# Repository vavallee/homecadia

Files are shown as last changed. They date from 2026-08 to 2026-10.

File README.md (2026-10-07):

<h1 align="center">
  <picture>
    <source media="(prefers-color-scheme: dark)" srcset="docs/img/logo-dark.svg">
    homecadia
  </picture>
</h1>

<!-- Logo: the Grand-Pré Memorial Church (Grand-Pré National Historic Site, Nova
     Scotia) behind the case wordmark; drawn without religious symbols. -->

**A battery-powered Matter-over-Thread room sensor for Home Assistant, built
from scratch on the ESP32-C6 with esp-matter and ESP-IDF. 125 µA average,
e-ink display, rotary dial, no cloud, no Wi-Fi, and every trap written down.**








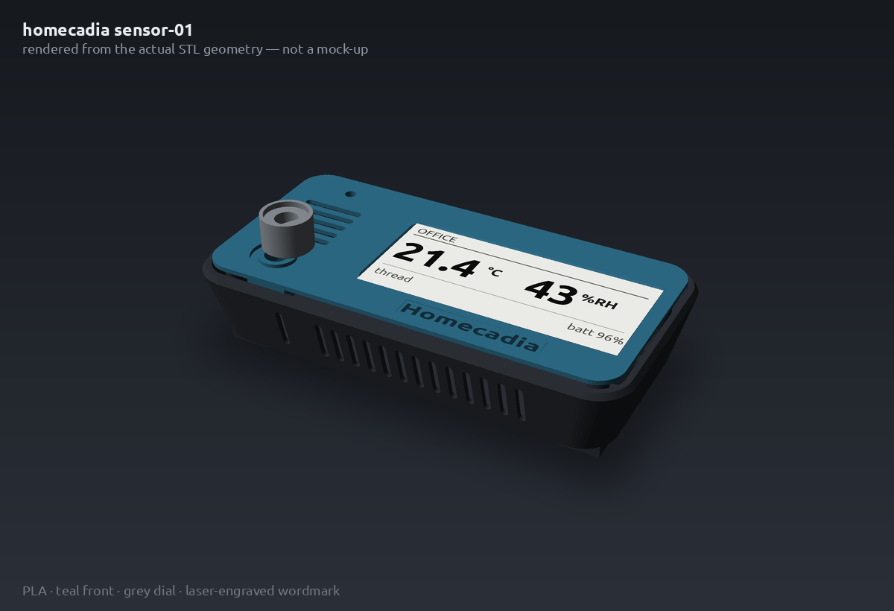
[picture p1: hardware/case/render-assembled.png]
sensor-01


<!-- photo replaces the render once a unit is assembled: ![sensor-01](docs/img/sensor-01.jpg) -->

A room temperature and humidity sensor that reports to Home Assistant over
Thread as a Matter sleepy end device, shows its own readings on a 2.9" e-ink
panel, and takes input from a rotary dial. It averages **125 µA** measured on
the bench, about eighteen months on one 2000 mAh cell at 85 % usable. No vendor
cloud, no hub beyond a Thread border router, and no Wi-Fi: the radio is
compiled out.

Everything is here: firmware, drivers, pin map with schematic-verified board
facts, measured power budget, 3D-printable enclosure, bill of materials with
real prices, and the reasoning behind each decision, including the ones that
turned out wrong.

## At a glance

| | |
|---|---|
| MCU | Seeed XIAO ESP32-C6 (RISC-V, 802.15.4 + BLE; Wi-Fi compiled out) |
| Firmware | **aardvark** (Matter model name and version string, e.g. `aardvark 0.7.0`; build output `aardvark.bin`, OTA image `aardvark-<version>.ota`) |
| Stack | [esp-matter](https://github.com/espressif/esp-matter) v1.6 on ESP-IDF v5.5.5, C++ |
| Network | Matter over Thread, OpenThread minimal device (MTD), commissioned over BLE |
| Power mode | Intermittently Connected Device (ICD), short idle time: 15 s parent polls, 600 s idle interval, automatic light sleep |
| Controller | Home Assistant with matterjs-server, Home Assistant Connect ZBT-2 border router |
| Clusters | Temperature Measurement, Relative Humidity Measurement, Power Source (battery % and voltage), Thread Network Diagnostics with counters |
| Measured current | **125 µA** paired and settled (sleep floor 57 µA, parent poll ~0.48 mC); **19.7 µA** unpaired in deep sleep |
| Display | 2.9" 296×128 SSD1680 e-paper, partial refresh ~6–7.5 mC, full ~19 mC |
| Status | One unit bench-verified on a Nordic PPK2; enclosure being redesigned |

## If you are building Matter or Thread devices on an ESP32

Most of this repo is reusable even if you never build this sensor. The
findings that took longest, with where to read them:

| Topic | Where |
|---|---|
| Getting an ESP32-C6 Matter device from ~376 µA to 125 µA: ADC power domain, bus power-down flags, ICD mode, a pin regression | [power-budget.md](docs/power-budget.md), [field-notes](docs/field-notes.md) §20–§22, §28 |
| Long Idle Time ICD buys nothing with Home Assistant (no check-in client) and costs ~67 µA; what to use instead | [retro](docs/retro.md) M8, [sdkconfig.defaults](firmware/sensor-01/sdkconfig.defaults) |
| A non-wake GPIO with a level interrupt under `CONFIG_PM_SLP_DISABLE_GPIO`: +16 µA floor, polls 60 % dearer | [field-notes](docs/field-notes.md) §28 |
| Waking light sleep from a rotary encoder: LP GPIOs only, level not edge | [field-notes](docs/field-notes.md) §21, [`ec11_encoder`](firmware/components/ec11_encoder) |
| An unpaired Matter device draws 28 mA; deep sleep that works (restart, then sleep before the stack starts) | [field-notes](docs/field-notes.md) §26–§27 |
| `attribute::update()` silently does nothing for code-driven clusters in esp-matter v1.6 | [field-notes](docs/field-notes.md) §9 |
| Commissioning to Home Assistant without HAOS: test certificates, BLE proxy, border router | [commissioning.md](docs/commissioning.md) |
| Thread coverage, border-router outages, a bare XIAO ESP32-C6 as a Thread router | [field-notes](docs/field-notes.md) §6–§7, §24, [infrastructure.md](docs/infrastructure.md), [bringup.md](docs/bringup.md) Radio / Matter |
| Measuring µA on a sleepy radio device with a PPK2, and analysing captures offline | [`tools/ppk2-events.py`](tools/ppk2-events.py), [retro](docs/retro.md) T7–T9 |
| Hardware bring-up traps: FPC ribbons, flux, underside pads, breadboard battery paths | [assembly.md](docs/assembly.md), [battery-runbook.md](docs/battery-runbook.md), [field-notes](docs/field-notes.md) §15–§19, §25 |
| Eight weeks of bring-up in one place: what went wrong, why, and the checklist for the next unit | [retro.md](docs/retro.md) |

> **Status: bench-verified, not yet assembled.** One unit runs on the bench
> (XIAO, driver board, panel, SHT40, encoder on a breadboard) with a Nordic
> PPK2 standing in for the cell. Verified there: commissioning to Home
> Assistant over Thread, display output, battery-voltage reading (within 3 mV
> of a meter, 3.4–4.0 V), **125 µA settled paired current** (2026-10-05),
> 19.7 µA unpaired deep sleep, and the dial waking the chip from light sleep on
> battery power. It has run 21 h on a real LiPo with no restart. **Not yet
> done:** a long soak on a real cell, and the enclosure, which is being
> redesigned. Open rows are in [docs/bringup.md](docs/bringup.md); code written
> ahead of hardware is marked `HW-VERIFY` and tracked there. The build
> procedure, with a test gate after every soldering stage, is
> [docs/assembly.md](docs/assembly.md).

## Devices

| Device | Status | Description |
|---|---|---|
| [sensor-01](firmware/sensor-01/) | in development | Battery-powered room temp/humidity sensor. 2.9" e-ink display, rotary dial, Matter-over-Thread sleepy end device (SIT ICD). 3 units. |

## What you can lift from here

The drivers are self-contained ESP-IDF components with no dependencies beyond
the IDF itself. Copy the directory into your own `components/` and it builds.
MIT licensed.

| Component | Why it might be useful |
|---|---|
| [`sht40`](firmware/components/sht40) | Sensirion SHT40 on the ESP-IDF 5.x `i2c_master` API (not the deprecated legacy driver), high-precision single-shot with CRC-8 validation |
| [`ssd1680`](firmware/components/ssd1680) | 2.9" e-paper with **differential partial refresh**, periodic full refresh to clear ghosting, and panel deep sleep between updates — the parts most sample code leaves out |
| [`monogfx`](firmware/components/monogfx) | 1-bit framebuffer renderer with a scaled 5×7 font and a seven-segment digit routine. No LVGL, no external graphics library |
| [`ec11_encoder`](firmware/components/ec11_encoder) | EC11 rotary encoder decoded from a Gray-code transition table in an ISR — bounce-immune without debounce delays, and draws no idle current |

Tools, usable on any project:

| Tool | What it does |
|---|---|
| [`tools/ppk2-events.py`](tools/ppk2-events.py) | Reads a Nordic PPK2 `.ppk2` capture offline and splits it into sleep floor, radio polls, bursts and short wakes with their charge, so one capture gives a per-item current budget |
| [`tools/matter-node.py`](tools/matter-node.py) | Reads a node through the Home Assistant Matter server WebSocket: the cached attributes (free for the device) or a forced interview |
| [`tools/check-profiles.sh`](tools/check-profiles.sh) | Asserts a shipping and a bench sdkconfig really differ on sleep, and that test-only options are off in shipping. Runs in CI |

Also reusable regardless of hardware: the
[power budget](docs/power-budget.md) and the firmware policies it forced, the
[retro](docs/retro.md), and the [documented traps](#traps-that-cost-time)
below.

## Features

Firmware capabilities, all implemented in this repo unless noted:

- **Matter over Thread**, Wi-Fi compiled out. OpenThread MTD, commissioned over
  Bluetooth Low Energy, joins via any OpenThread border router (developed
  against Home Assistant Connect ZBT-2).
- **Short Idle Time ICD** (Intermittently Connected Device): automatic light
  sleep between 15 s parent polls, and a 600 s idle interval that the device
  offers as its subscription max interval, so a report with nothing new goes
  out every 10 min. Long Idle Time was dropped on 2026-10-04: Home Assistant
  registers no check-in client, so it only added cost
  ([retro](docs/retro.md) M8).
- **Unpaired deep sleep**: a unit nobody pairs deep-sleeps at 19.7 µA once
  its 15-minute commissioning window closes, and a turn of the dial starts a
  new window ([field-notes](docs/field-notes.md) §27).
- **Thread Network Diagnostics with counters** (attach attempts, parent
  changes, MAC retries), readable from the controller at no reporting cost.
- **Matter clusters**: TemperatureMeasurement, RelativeHumidityMeasurement, and
  PowerSource with battery percentage and voltage.
- **Delta-gated reporting** — a report is sent on ≥0.2 °C / ≥1 %RH change, with
  a forced heartbeat every N polls, instead of on every sample.
- **SHT40 driver** (`firmware/components/sht40`) on the ESP-IDF 5.x
  `i2c_master` API, high-precision single-shot with Sensirion CRC-8 checking.
- **SSD1680 e-paper driver** (`firmware/components/ssd1680`) with differential
  partial refresh, periodic full refresh for ghosting, and panel deep sleep
  between updates.
- **1-bit framebuffer renderer** (`firmware/components/monogfx`) with a scaled
  5×7 font and a seven-segment digit routine — no external graphics library.
- **EC11 rotary encoder** (`firmware/components/ec11_encoder`) decoded from a
  Gray-code transition table in an interrupt handler: bounce-immune and drawing
  no idle current.
- **Local-only UI**: readings, diagnostics, and settings views; settings persist
  in NVS. The display never renders Home Assistant state — it shows what this
  device measured.
- **Battery monitoring** via a 2×1 MΩ + 100 nF divider on GPIO4 (an underside
  pad): 64 one-shot ADC samples after a 20 ms settle, eFuse curve-fitting
  calibration, and a scale factor fitted against a metered source to correct the
  ADC input loading the 500 kΩ divider. Open-circuit-voltage lookup table for
  percent.
- **Dial wakes the chip** from light sleep on a detent (encoder A on an LP
  GPIO underside pad, level-triggered).
- **Factory reset** on a 10-second encoder press (turn first: the switch is on
  a pin that cannot wake the chip); commissioning and low-battery states shown
  on a single LED and on the display.
- **CI** builds the flashable images on every push touching `firmware/**` and
  uploads them as an artifact.

## sensor-01 hardware

Seeed XIAO ESP32-C6 + Seeed ePaper Driver Board for XIAO V2 + 2.9" mono e-ink
(296×128, SSD1680) + Grove SHT40 + EC11 rotary encoder + 2000mAh LiPo, in a
wall-mount enclosure remixed from [veltoc](https://github.com/danking6/veltoc)
([hardware/case](hardware/case/README.md) — rev 4, FDM PLA, laser-engraved
wordmark).

assembled render

*Assembled view rendered from the enclosure STLs. Colours and finish are
indicative; no unit has been built yet.*

sensor-01 pin map

Full bill of materials: [docs/bom.md](docs/bom.md). Pin map with the
schematic-verified board facts behind this diagram:
[docs/pinmap.md](docs/pinmap.md). The official bare-board pinout is on the
[Seeed XIAO ESP32-C6 wiki](https://wiki.seeedstudio.com/xiao_esp32c6_getting_started/)
(not reproduced here — Seeed's wiki content is GPL-3.0, this repo is MIT).

⚠️ This build involves a bare lithium-polymer cell soldered directly to the
board. Read the polarity warning at the top of
[docs/assembly.md](docs/assembly.md) before connecting anything — reversed
polarity destroys the charge circuit, and damaged LiPo cells are a fire hazard.

## Firmware

Espressif [esp-matter](https://github.com/espressif/esp-matter) v1.6 on
ESP-IDF v5.5.5, C++. Thread only (Wi-Fi disabled), commissions over Bluetooth
Low Energy to Home Assistant via an OpenThread border router (Home Assistant
Connect ZBT-2). Build instructions: [docs/build.md](docs/build.md).

The device advertises Espressif's **test vendor ID 0xFFF1** and shared test
commissioning credentials. It is not a Matter-certified product; controllers
will show an uncertified-device warning. Per-device factory partitions
(`esp-matter-mfg-tool`) are an open work item — see
[docs/commissioning.md](docs/commissioning.md).

## Documentation

| Doc | Contents |
|---|---|
| [docs/bom.md](docs/bom.md) | Bill of materials, part SKUs, divider-value rationale |
| [docs/pinmap.md](docs/pinmap.md) | Pin assignments and schematic-verified XIAO ESP32-C6 board facts |
| [docs/assembly.md](docs/assembly.md) | Wiring and build order, battery-polarity warning |
| [docs/build.md](docs/build.md) | Pinned toolchain SHAs, Docker and native builds, flashing from WSL2 |
| [docs/commissioning.md](docs/commissioning.md) | Pairing to Home Assistant: the three preconditions, the BLE-proxy workaround, factory reset. Apple Home is not available here and the doc says why |
| [docs/retro.md](docs/retro.md) | **Retrospective of the whole bring-up**: lessons, timeline, every problem with its cause and rule, the checklist for the next unit, open questions |
| [docs/field-notes.md](docs/field-notes.md) | **Traps that cost real time during bring-up**, one numbered section per incident (cited as §n). Read before bringing up another unit |
| [docs/power-budget.md](docs/power-budget.md) | Modelled and measured current draw per item, battery-life calculator, the policies it forced |
| [docs/battery-runbook.md](docs/battery-runbook.md) | Why a pack reads 0 V or a unit resets on battery: protection-board causes, look-alikes, and the test order |
| [docs/bringup.md](docs/bringup.md) | Hardware verification checklist — every `HW-VERIFY` marker has a row |
| [docs/diagrams/](docs/diagrams/) | Bench wiring, battery/divider schematic, enclosure internals and the no-solder bring-up ladder (self-contained HTML) |
| [docs/infrastructure.md](docs/infrastructure.md) | Network-side hardware: ZBT-2 border router, Thread coverage, Voice PE, order status |
| [docs/source-reliability.md](docs/source-reliability.md) | Documented traps in vendor docs and third-party sources |
| [hardware/case/README.md](hardware/case/README.md) | Enclosure: revision history, measured wall thicknesses, print vendor and material, engraving artwork |
| [circuit-board-maker/](circuit-board-maker/README.md) | Custom-PCB evaluation and two paper board designs. **Concluded: not worth it for three units.** Never fabricated — see the conflicts list before reviving it |

## Traps that cost time

Findings that aren't in any datasheet, written down so the next person doesn't
pay for them twice. Full list in
[docs/source-reliability.md](docs/source-reliability.md) and
[docs/pinmap.md](docs/pinmap.md).

- **A0 and D0 are the same pin on the XIAO ESP32-C6.** If your display uses D0
  for reset, the obvious ADC pin is gone. Battery sense moved to an underside
  test pad ([pinmap](docs/pinmap.md)).
- **The C6's RF switch is off at reset.** GPIO3 has a 10k pull-up and must be
  driven low in firmware before the antenna works; GPIO14 selects onboard
  ceramic versus U.FL. Neither pin is on the header. Schematic-verified.
- **espboards.dev pin tables are wrong for the C6** — they're shared boilerplate
  across ESP32 variants.
- **The Seeed wiki's battery-sense snippet doesn't apply.** It assumes an
  onboard divider the C6 schematic shows isn't populated.
- **A 100k battery divider costs ~9% of a 300µA budget.** 2×1MΩ + 100nF instead,
  at the price of a high-impedance ADC source ([power budget](docs/power-budget.md)).
- **A live ADC unit keeps the C6's radio power domain on through every light
  sleep** (~95 µA). Create and delete the unit per reading, and hold a
  no-light-sleep lock across it or the chip can fail to wake
  ([field notes](docs/field-notes.md) §21).
- **The chip only powers down its peripherals in light sleep if every I2C and
  SPI bus asks for it** (`flags.allow_pd`, `SPICOMMON_BUSFLAG_SLP_ALLOW_PD`).
  Without them the sleep floor was 279 µA; with them, 56 µA (§21).
- **A multimeter on a high-impedance node is a load, not a reference.** A 10 MΩ
  meter reads a 1 MΩ:1 MΩ divider midpoint ~5 % low. Calibrate the ADC against
  the supply, end to end (§23).
- **Light sleep kills the USB serial port in ~2 seconds**, which makes a board
  effectively unflashable without `CONFIG_USJ_NO_AUTO_LS_ON_CONNECTION`
  ([build](docs/build.md) has the recovery procedure, including the WSL2/usbipd
  quirks).
- **Opening `/dev/ttyACM0` with a plain shell read can hard-reset the chip** —
  it pulses the USB-Serial-JTAG control lines. Use `idf.py monitor`.
- **Seeed's sleep-current figures are for a bare board.** Measured on this build:
  a 45–57 µA light-sleep floor once the fixes here were in; 376 µA before
  them ([power budget](docs/power-budget.md)).
- **Long Idle Time ICD does nothing for you under Home Assistant.** No
  check-in client registers, so the device runs short-idle mode anyway, while
  LIT forces a 5 s minimum active period after every exchange and an extra
  wake a minute. Turning it off and raising the idle interval to 600 s took
  the average from 307 to 185 µA ([retro](docs/retro.md) M8).
- **A non-wake GPIO with a level interrupt reads as triggered in light sleep.**
  With `CONFIG_PM_SLP_DISABLE_GPIO`, pins that are not wake sources are
  isolated and read low. A push switch on an HP pin with a low-level interrupt
  raised the floor 16 µA and made every Thread poll 60 % dearer;
  `gpio_sleep_sel_dis()` fixed it, 185 → 125 µA (§28).
- **Only LP GPIOs (0–7) wake the C6 from light sleep with peripheral
  power-down on, and only on a level.** On the XIAO the free LP pins are
  underside pads (§21, [pinmap](docs/pinmap.md)).
- **An unpaired Matter device on the C6 never light-sleeps and draws ~28 mA.**
  `esp_deep_sleep_start()` from the running stack hung or stuck at 20 mA; what
  worked is restarting and entering deep sleep at the top of the next boot,
  before Bluetooth, Thread or power management start (§26–§27).
- **A USB host keeps the C6 out of light sleep**, so a sleep bug can be
  invisible for weeks on the bench. Test sleep on battery or a PPK2 with USB
  out (§20).
- **A breadboard row in the battery path brown-outs the radio.** Thousands of
  restarts read as a firmware fault; the Matter `bootReason` attribute said
  brown-out all along ([battery-runbook](docs/battery-runbook.md) B3).

## Milestones

| # | Deliverable | Status |
|---|---|---|
| 1 | Repo scaffold, docs, CI compiling an esp-matter skeleton for esp32c6 | done |
| 2 | Matter temp/humidity over Thread, commissions to HA (TinyENV parity) | **done 2026-08-23** — commissioned to HA over ZBT-2 OTBR, readings live in HA; see `docs/field-notes.md` for the preconditions |
| 3 | Display driver, view 1 rendering readings, measured refresh cost | **done** — display verified 2026-08-22 (full 1.79 s / partial 0.54 s BUSY); refresh charge measured 2026-10-05: partial ~6–7.5 mC, full ~19 mC |
| 4 | Encoder, views, settings, wake behavior | **done 2026-09-28** — a detent wakes the chip from light sleep on battery (encoder A on the MTCK pad); the push switch registers within 2 s of a turn |
| 5 | ICD tuning, battery reporting, power budget with measured numbers | **done** — 238 µA over 12.6 h (2026-09-22); **125 µA settled** after the ICD and pin fixes (2026-10-05); unpaired deep sleep 19.7 µA; battery voltage within 3 mV. See `docs/power-budget.md` |
| 6 | Factory reset, low-battery behavior, assembly guide final, v1.0.0 | factory reset + LED + low-bat display done; rest awaits hardware |

## Repo layout

```
docs/               BOM, pin map, assembly, commissioning, power budget, build,
                    field notes, retro
hardware/case/      wall-mount enclosure (veltoc remix, MIT) + engraving artwork
circuit-board-maker/ custom-PCB evaluation + two unfabricated KiCad designs
firmware/
  components/       drivers shared across future homecadia devices
  sensor-01/        esp-matter application
tools/              PPK2 capture analysis, Matter server node reader, profile check
.github/workflows/  CI: firmware build on push, .bin artifacts
```

## Building it yourself

1. **Read [docs/bom.md](docs/bom.md)** — real parts, real prices in CAD, real
   vendors, and which ones have known counterfeits or reversed polarity.
2. **Print the enclosure** from [hardware/case](hardware/case/README.md), or
   adapt it. The revision history there explains why each dimension is what it
   is, which matters if you swap the battery or the display.
3. **Build the firmware** with [docs/build.md](docs/build.md) — Docker path
   matches CI exactly and is the low-friction option.
4. **Wire it** using [docs/pinmap.md](docs/pinmap.md) and
   [docs/assembly.md](docs/assembly.md). Read the LiPo polarity warning first.
5. **Commission it** with [docs/commissioning.md](docs/commissioning.md), then
   work through [docs/bringup.md](docs/bringup.md).

Forking for different hardware? `firmware/sensor-01/main/app_config.h` is the
single source of pin truth and the place to start.

## Contributing

This is a personal build against one specific parts list, so the parts list, the
pinned toolchain and the locked design decisions are unlikely to change. That
said: **corrections are very welcome**, especially if you've measured something
this repo only models, or if one of the [traps](#traps-that-cost-time) turns out
to be wrong on your hardware. Issues and pull requests both fine.

If you are working on Matter or Thread devices on the ESP32-C6 (or H2, or any
ESP32 with an 802.15.4 radio) and hit something documented here, or something
that should be, open an issue: comparing measured numbers across boards is
the fastest way to tell a board quirk from a firmware one.

## License

MIT, see [LICENSE](LICENSE). Third-party attribution — including the veltoc
enclosure remix and the TinyENV architecture references — is in
[NOTICE.md](NOTICE.md).

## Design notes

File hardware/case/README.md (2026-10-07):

# Wall-mount case (veltoc remix, rev 5)

Remix of [veltoc](https://github.com/danking6/veltoc) 3D models (MIT,
© 2026 Dan King). `case-back-wallmount.stl` and `case-front.stl` are both
modified; `insert-tray.stl` and `encoder-knob.stl` print as-is from upstream.

> **rev 5 — back 8 mm deeper (2026-10-06); not yet printed.** Print it with
> [PRINTING.md](PRINTING.md). Only
> `case-back-wallmount.stl` changed: 23.00 → **31.00 mm** tall, outline and
> rim unchanged, so the rev 4 front, tray and knob still fit it. The shell was
> cut at z = 17.74 mm (above the USB-C hole, below the rim fillet), the upper
> part lifted 8 mm and the cut joined with a vertical band (`deepen.py`, in
> this directory: `python3 deepen.py IN OUT 17.74 8`, IN = the rev 4 file). The mesh keeps the
> same open-edge count as the vendor-printed rev 4 file (33), so the cut added
> no defects.
>
> Layout it is built for, from caliper measurements of the parts as built
> (2026-10-06), floor upward: the **cell flat on the floor** (56 × 34.2 ×
> 11 mm, bare leads ~29 mm, no JST), the tray on the cell (1.6 mm plate), the
> XIAO in its sockets on the driver board (15.5 mm from the USB-C top to the
> driver board's underside), the **pins under the driver board trimmed to
> ~1.5 mm** (they are 9.0 mm as built for the breadboard), then the panel
> (~1.2 mm, not measured) against the front plate: ~30.8 mm against ~33.6 mm
> of inside depth: ~2.8 mm spare for the unmeasured panel and foam tape. The USB-C panel connector's long leads coil in the free
> bay at one end; its hole does not need to line up with the XIAO's port.
> SHT40 board: 41.8 × 19.7 × 6.5 mm, ~130–140 mm lead to a 4-pin connector.
>
> **rev 4 does not fit the parts — found 2026-09-24.** Kept in git history
> (commit `4a53b2e`). Against the STL geometry, the 2000 mAh cell
> (56 × 34.5 × 10.6 mm) does not fit the cavity with the tray and driver board
> in place; the free bay at the left end is about 35 × 48 × 17 mm and the USB
> port falls inside it. Against the printed parts in hand: the panel and the
> tray fit; the driver board does not seat, because the header sockets soldered
> to it are taller than the back allows. The "2.1 mm clearance" below counts
> length only and did not account for the stack height. A deeper back is the
> expected fix; it waits on caliper measurements of the real parts
> ([docs/bringup.md](../../docs/bringup.md), Case & mechanical).
>
> **rev 2 — lengthened 7 mm for the 2000 mAh cell.** Upstream is built around a
> 1400 mAh cell (EEMB 112945, 45 mm long). Our BOM specifies a 2000 mAh EEMB
> LP103454, whose finished size is **56 × 34.5 × 10.6 mm** — 11 mm longer. The
> rev 1 interior measured 99.64 mm and had to hold the 48.5 mm `insert-tray`
> plus the cell: 104.5 mm of parts in a 99.6 mm box.
>
> Both shells were cut at **x = 24.73 mm** — a band verified prismatic (identical
> cross-section either side) and clear of the display aperture (29.5–97.5),
> encoder, LED, vents and tray posts — and everything right of the cut moved
> +7 mm. Interior is now **106.64 mm**, leaving **2.1 mm clearance**. The display
> aperture is unchanged at 68.00 mm wide; it simply sits 7 mm further along.

assembled render

Assembled view, rev 4 (the rev 5 back is 8 mm deeper; not re-rendered). Rendered directly from the STL geometry in this
directory — real part shapes and real relative positions, so the proportions,
the wordmark placement and the aperture framing are accurate. The wordmark is
composited at its true size and position, representing the laser engraving.
Surface finish and screen contents are illustrative. `preview.png` is the older
rev 1 image and no longer matches the models.

**Colours (PLA, matched to EurekaTec stock):** teal front, light grey dial,
black or dark grey back (PLA availability to confirm), tray any colour since it
is never seen. EurekaTec's ABS stock is black / dark grey / red only, which is
part of why the build moved to PLA.

## Files (`stl/`)

| File | Status | Outer size (mm) | Notes |
|---|---|---|---|
| case-back-wallmount.stl | remixed + rev 2 stretch + **rev 5 deepen** | 116.28 × 59.28 × **31.00** | wall-mount rails, side USB-C, rear port plugged |
| case-front.stl | rev 2 stretch | 110.60 × 53.60 × 8.20 | EC11 mount (Ø6.8 shaft hole, Ø9.8/Ø14 recess), 3mm LED hole, display aperture; flat face, wordmark laser-engraved after printing |
| insert-tray.stl | rev 2 thickened | 48.50 × 45.50 × 6.60 | XIAO mount: plate thickened 1.0 → **1.6mm**, four Ø2.4mm pegs on a 17.0 × 21.0mm pattern. **Not** a battery cradle — the cell sits loose beside it |
| encoder-knob.stl | upstream | 13.50 × 13.50 × 9.50 | fits 20mm flatted D-shaft |

Interior of the assembled back: **106.64 × ~47.9 × ~26.6 mm** (rev 5; 18.6 in rev 4), one open cavity
with four corner bosses. No battery compartment and no sensor mount — both are
open questions for the test fit.

## Changes in case-back-wallmount.stl

- Rear Ø12.8mm panel-mount USB-C hole **plugged** (was center-rear — would
  face the wall).
- New Ø12.8mm USB-C hole through the **left side wall** (y=25, z=10) for the
  female USB-C panel pigtail; cable reaches the XIAO's USB-C internally.
- Two standoff rails (11×44×3mm) on the rear face: 3mm air gap so the rear
  vents breathe against a wall, and flat landings for Command Small strips
  (one per rail).
- Keyhole slots in each rail (**92mm apart after the rev 2 stretch** — was 85;
  measured centre-to-centre at x=7.50 and x=99.50, center height y=30): Ø9.5 entry,
  4.3mm slot rising 8mm, head pocket behind a 2mm retention face. Fits #6
  pan-head screws (head ≤ Ø8.5×2.4mm). Level the two screws; the slot rises
  up, so the case drops onto them.
- Orientation on the wall: slatted side **down** (air inlet), rear vent band
  at the top (outlet).

## rev 4 — wordmark is laser-engraved, not printed

**The rev 3 embossed wordmark was reverted.** Raised lettering is incompatible
with the only good print orientation for this part. The outer face is flat and
the interior bosses rise 8.2mm, so the panel must print outer-face-down: face on
the bed, bosses building upward, no supports. Add 0.6mm of raised lettering to
that face and only **85.6 mm² of letter tops touch the bed** — the entire panel
then starts 0.6mm up over air and needs support across the whole cosmetic
surface. Flipping it over is worse: the plate ends up 8.2mm in the air on boss
pillars. EurekaTec caught this in quoting; the geometry confirms it.

`case-front.stl` is therefore back to flat (2,600 triangles, 110.60 × 53.60 ×
8.20mm, 6.16 cm³, watertight) and the wordmark is applied **after printing, by
laser engraving** — which also reads crisper at 5mm cap height than extruded
plastic ever would. This requires PLA; ABS lasers poorly.

Artwork lives in [`artwork/`](artwork/):

| File | Purpose |
|---|---|
| `wordmark-homecadia.svg` | **vector, send this one.** Glyphs outlined (no live text, no font needed), 36.72 × 5.70mm, 1 user unit = 1mm, filled black = material to remove |
| `wordmark-placement.svg` | vector placement drawing: panel outline, datum lines, wordmark in position. Reference geometry is stroked grey; only the filled wordmark is engraved |
| `wordmark-homecadia-1200dpi.png` | the original raster, black-on-white at 1200 dpi. Superseded by the SVG; kept because it is what the 2026-08-13 quote was based on |
| `wordmark-placement.png` | original dimensioned drawing, datum = lower-left corner of the outer face |

The SVGs are generated from `Ubuntu-B.ttf` at 5.00mm cap height with 0.098mm of
letter-spacing, chosen so the ink box matches the 36.72mm width the raster
artwork and the quote were built around. Two independent renderers (fontTools
and PIL) put untracked Ubuntu Bold at 35.94mm, so the spacing in the original
PNG was deliberate and is reproduced rather than discarded.

**The height is 5.70mm, not the 5.64mm quoted above.** 5.70mm is the true ink
height of `homecadia` in Ubuntu Bold at a 5.00mm cap height — the ascenders of
`h` and `d` rise above the cap line, and there are no descenders. The 5.64
figure appears to be a measurement artifact; the 0.06mm difference is far below
engraving tolerance and does not move the placement datum, which is the
lower-left corner.

Placement: 54.09mm from the left edge, 3.07mm up from the bottom edge, 36.72 ×
5.64mm, Ubuntu Bold, 5.00mm cap height, engraved 0.3–0.5mm deep. That sits in
the solid strip between the aperture's bottom edge and the panel edge, clear of
the vents, encoder and LED hole.

## Wall thickness / DFM

Measured off the meshes, so these are the numbers to answer a vendor DFM flag with:

| Feature | Thickness | Verdict |
|---|---|---|
| `case-back-wallmount` shell walls | **1.44mm** | 3–4 perimeters at a 0.4mm nozzle — normal enclosure wall |
| `case-front` shell walls | **~1.3mm** | same |
| `insert-tray` plate | **1.60mm** (rev 2; was 1.00) | thickened specifically to clear the flag |
| `insert-tray` pegs | Ø2.4mm shank, Ø4.0mm base, 5mm tall | pins, not walls; printable in PLA |

JLC3DP's FDM guidance is a 1.2mm minimum with 2mm ideal, so the shells sit
between the two and trigger "thin walls detected". **Accept it** — a 1.4mm wall
is sound in PLA or ABS, and thickening the shells would mean a true surface
offset in CAD, not the cut-and-shift edits used here.

Sub-millimetre readings do appear in an automated scan (down to 0.13mm) at the
corner bosses and the mating lip. Those are **tangency slivers** where a
cylindrical boss meets a filleted wall, not standalone walls; slicers merge
them into the adjacent perimeter. Verified by cross-section at z=10.

## Material and vendor (current decision)

**FDM PLA, all four parts, at [EurekaTec.ca](https://eurekatec.ca)** — Canadian,
quotes by email, no online quoting system. Quote requested 2026-08-13; a second
request went to Azata.ca the same day.

ABS was the original choice, for heat margin around the LiPo. Two things changed
it: EurekaTec stocks ABS only in black, dark grey and red, and ABS does not
laser engrave cleanly — and the wordmark has to be engraved (see rev 4 above).
PLA gets both the intended colours and the engraving.

The heat argument turned out to be over-cautious. This is an indoor wall sensor
that must already be sited away from sun, radiators and exterior doors or its
readings are meaningless ([bringup.md](../../docs/bringup.md) placement notes),
so the conditions that would soften PLA are ones the device cannot be used in.
PETG remains the ideal middle ground — asked, answer pending.

**One material for all four parts.** Mixing PLA and ABS across two shells that
mate over 116mm introduces a shrinkage mismatch on a fit that already has only
2.1mm of battery clearance.

Avoid SLA resin: brittle, UV-degrading, and it would shear the Ø2.4mm tray pegs
and the M2 self-tapper bosses. If resin is ever forced, use a toughened grade
(8228 or 9000HE), never 9600.

### Vendor evaluation: JLC3DP — rejected for FDM, viable as MJF fallback

Recorded because the constraints are non-obvious and cost a quoting round.

**JLC3DP does not offer PETG** (their FDM lineup is ABS, ASA, PA12-CF, TPU,
PEBA, PEEK, ABS-ESD, PLA-P), and more decisively their FDM process enforces a
**30 × 30 × 10 mm minimum bounding box**, which this design cannot meet:

| Part | Size (mm) | Volume | FDM 30×30×10 | MJF 5×5×5 |
|---|---|---|---|---|
| case-back-wallmount | 116.28 × 59.28 × 23.00 | 19.86 cm³ | passes | passes |
| case-front | 110.60 × 53.60 × **8.20** | 6.16 cm³ | **rejected** (vendor-confirmed) | passes |
| insert-tray | 48.50 × 45.50 × **6.60** | 3.09 cm³ | **rejected** | passes |
| encoder-knob | 13.50 × 13.50 × **9.50** | 1.01 cm³ | **rejected** (vendor-confirmed) | passes |
| | | **30.12 cm³/set, 90.36 cm³ for 3** | | |

Splitting across processes was rejected: FDM holds ±0.3mm per 100mm and SLA
~±0.1mm, and the front and back must mate over a 116mm span with aligned corner
screws. Mixed shrinkage on mating parts trades a size rule for a fit problem.

If JLC3DP is ever needed, **MJF Nylon PA12** is the process that works there:
its 5×5×5mm minimum accepts every part, 0.8mm minimum wall clears our 1.30mm
thinnest, and 0.8mm minimum feature clears the Ø2.4mm tray pegs. PA12 is also a
genuinely good enclosure material — tough, no supports, no scars in the display
aperture. It costs more than FDM, which is why EurekaTec won on price.

The knob prints on any of these routes; a commodity aluminium 6mm D-shaft knob
remains a fine substitute if the printed bore proves too tight to ream.

## Print notes

- 3 units → print each file ×3. PLA, ~0.2mm layers.
- **case-front prints outer-face-down**, no supports — see rev 4 above for why
  this only works with a flat face.
- Back prints rear-face down (rails on bed); keyhole head-pockets bridge
  ~8.8mm — fine with standard supports/bridging.
- Tolerances derived from published dims, **not test-fitted**. Print ONE unit
  first and test-fit the panel, driver board, encoder, USB pigtail and a #6
  screw head before committing all three.
- `case-back-wallmount.stl` carries **33 non-manifold edges** — present in the
  upstream mesh, not introduced by the rev 2 stretch (verified against git
  HEAD). Slicers and print services auto-repair this class of defect; no action
  needed unless one complains.
- `preview.png` shows the rev 1 geometry and is superseded by
  `render-assembled.png`; replace both with a photo once a unit is built.

## Parts this design needs beyond the sensor BOM

- EC11-style rotary encoder (upstream links Amazon B08728K3YB; this build
  uses the Bourns PEC11R — see [docs/bom.md](../../docs/bom.md))
- Female USB-C panel-mount pigtail (upstream links Amazon B0D1MW6YPL; bezel
  must fit Ø12.8)
- 3mm LED
- Battery divider resistors: upstream specifies 2×100k, **this build uses
  2×1MΩ + 100nF** — 100k bleeds ~21µA continuously, ~9% of the power budget
  ([docs/bom.md](../../docs/bom.md)).
- Upstream firmware drives a BME280; this build's esp-matter firmware uses
  an SHT40.

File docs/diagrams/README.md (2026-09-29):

# Bench diagrams

Self-contained HTML pages used during sensor-01 bring-up. Open any of them
directly in a browser — no build step, no external assets, no network access.
Each follows the viewer's light/dark theme.

| File | What it shows |
|---|---|
| [bench-rig.html](bench-rig.html) | Breadboard wiring for the second bench step: XIAO + Grove SHT40 + ePaper driver board + panel, with the full jumper table |
| [battery-divider.html](battery-divider.html) | Step 3: the LiPo on the XIAO's underside pads and the 2×1M + 100nF ADC divider — schematic, connection table, and the polarity warning |
| [encoder-led.html](encoder-led.html) | Step 4: the EC11 rotary encoder and status LED, as built on node 26 (redrawn 2026-09-28): encoder A on the MTCK underside pad, push switch on D9 |
| [internals.html](internals.html) | How the parts sit inside the enclosure — plan view and side elevation, dimensioned from the STLs. **Does not match the parts:** the 2000 mAh cell and the stacked header height do not fit the printed case; redesign pending |
| [bringup-ladder.html](bringup-ladder.html) | The no-solder connectivity procedure: one thing added per rung, using only internal pull resistors and the ADC |
| [bench-verify.html](bench-verify.html) | Bench state as of 2026-09-12 (encoder pins since moved): every wire drawn on the breadboard by node, with the meter reading each node must give with the PPK2 as the battery. Pins from `app_config.h`, which is what is flashed — `assembly.md` steps 1–3 are stale |

## These are dated snapshots, not current state

They record what was believed at the moment they were drawn. Bench work since
has contradicted parts of them, and the contradictions are the useful bit:

- **`bench-rig.html` draws the driver board with female sockets fitted.** It
  ships with bare through-holes and no headers — see the warning in
  [../assembly.md](../assembly.md). The drawing was made before that was
  known, and the phantom faults that followed are what prompted the ladder.
- **`bench-rig.html` says step 1 is verified.** It was, then it wasn't — the
  SHT40 dropped off the I2C bus repeatedly. Root cause was a breadboard with
  dead spring clips, not the sensor or the wiring. A replacement board brought
  it straight back (`0x44` answering, readings flowing).
- **The panel has still never drawn.** Every "what success looks like" item in
  `bench-rig.html` remains unobserved.
- **`battery-divider.html` and `encoder-led.html` are drawn ahead of the
  work**, 2026-08-24. Pins and values come from `app_config.h`, `pinmap.md`
  and the component sources, but nothing in either has been built or measured.
  `encoder-led.html` draws the bench wiring; in the assembled unit the encoder
  A/B lines move to the driver board's `D4`–`D7`/`D9` breakout instead.
- **`internals.html` marks its own soft spots.** The driver board and ePaper
  module outlines are sketched rather than measured; everything tagged
  *geometry* came out of the STL files and is trustworthy.

Bring-up rows these feed are tracked in [../bringup.md](../bringup.md).

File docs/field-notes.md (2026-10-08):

# Field notes: traps that cost real time

Hard-won during sensor-01 bring-up (2026-08-17 → 24). Ordered by how much time
each one burned. Read this before bringing up units 2 and 3 — most of these
cost hours the first time and minutes once you know them.

## 1. Make "working" distinguishable from "silent" before you need it

`ssd1680.c`'s `busy_wait()` returned `ESP_OK` the instant BUSY read low, which
is also the resting state of a panel that received nothing. Every refresh
reported success while nothing was drawn. **Two days** went into probing pins
with a multimeter because the firmware said the display was fine.

Fixed by requiring BUSY to *rise* after `CMD_MASTER_ACTIVATE` (~1.8s full,
~0.5s partial). The general rule: **a status check that cannot fail is a bug.**
When adding any driver, ask what a disconnected part would return, and if it is
the same as success, fix that first.

## 2. Light sleep kills the USB-serial-JTAG console

With `CONFIG_PM_ENABLE` + `CONFIG_FREERTOS_USE_TICKLESS_IDLE` +
`CONFIG_PM_POWER_DOWN_PERIPHERAL_IN_LIGHT_SLEEP`, the port still **enumerates**
but every open fails at driver level — on Windows, `A device attached to the
system is not functioning`. It reads exactly like broken hardware. Hours were
lost blaming pyserial.

Use `sdkconfig.bench` for anything needing a console:

```sh
idf.py -B build-bench -DSDKCONFIG=build-bench/sdkconfig \
       -DSDKCONFIG_DEFAULTS="sdkconfig.defaults;sdkconfig.bench" build
```

**Nothing verified on the bench profile carries over to the shipping profile.**
ICD timing, radio wake and peripheral power-down all differ — re-validate
Matter and Thread on the default profile before shipping.

## 3. Map a tty to its USB VID before opening it

`node1` carries both the XIAO (`303a:1001`) and the Zooz Z-Wave stick
(`1a86:55d4`). Both appear as `ttyACM*`, and the numbering is not stable.
Opening the wrong one asserts DTR/RTS and resets someone else's radio.

```sh
for t in /sys/class/tty/ttyACM*; do
  root=$(readlink -f $t/device/..)
  echo "$(basename $t) -> $(cat $root/idVendor):$(cat $root/idProduct)"
done
```

Related: the ESP32-C6's USB-serial-JTAG discards output when it decides no host
is attached, and stays that way. If the port opens but yields nothing, reset
with esptool and capture immediately — a plain `cat` often never sees a byte.

## 4. ePaper FPC: go by insertion force, not by which way the copper faces

The correct orientation slides in with light finger pressure; the reversed one
needs pushing. Reversed, tab *n* meets panel pin 25−*n*, putting VDDIO on RST
and VCI on BUSY — the MCU then drives a supply rail and pulling RST low shorts
it. **Two panels died this way.** Seat until the stiffener is inside the
housing; a ribbon stopped short still latches and makes intermittent contact.
Insert and remove only with power off, and treat the bare flex as ESD-sensitive.

The XIAO seats with its **USB-C end away from the FPC connector**. Backwards,
nothing works and nothing looks wrong.

## 5. Matter commissioning needs three things aligned at once

1. **Test DAC trust.** Self-built devices carry esp-matter's test DAC, signed by
   a PAA not in the production DCL. Without `ENABLE_TEST_NET_DCL=true` on
   matter-server, commissioning reaches attestation and dies with
   `PAA not found in trust store`. The server downloads test roots either way;
   the flag is what makes it *trust* them.
2. **A working BLE proxy.** matter-server allows exactly **one** `/ble` client,
   and Home Assistant grabs it. On matter-server >= v0.8.0 that is fine — leave
   it alone and let HA's own proxy do the work. On older builds the bleak client
   could not complete the BTP handshake (matter-js/matterjs-server#1006) and the
   Node/noble client from `docs/ble-proxy-pod.yaml` was needed instead. See §12
   for why that was chased for two evenings rather than fixed in five minutes.
3. **Thread in range.** BLE and Thread must both reach the device *at the same
   time* — `connectNetwork` has to succeed inside the fail-safe window.

The commissioning window is time-limited from boot. **The QR staying on the
e-ink is not evidence the window is open** — it is drawn once and the panel
just holds the image. Power-cycle immediately before commissioning.

## 6. Check the infrastructure is alive before theorising about the device

An OTBR that has lost its dataset presents as `state: disabled` with an empty
child table, and every device then looks like it is out of range. Hours went
into a shielding theory while the border router simply was not running.

```sh
ot-ctl state        # expect leader/router/child, not disabled
ot-ctl ifconfig     # expect up
ot-ctl dataset active | head   # expect a network name
```

Restore from the dataset HA keeps in `/config/.storage/thread.datasets`:

```sh
ot-ctl dataset set active <tlv>
ot-ctl ifconfig up
ot-ctl thread start
```

Same credentials, so nothing needs re-provisioning. **Check this first whenever
a device will not attach.**

## 7. Thread coverage is a deployment problem, not a commissioning one

One border router in the basement does not cover a second-floor office. A
sensor commissions fine next to the ZBT-2 and cannot hold the mesh where it
actually lives. Any mains-powered Matter-over-Thread device becomes a router;
budget for one per floor. A Nanoleaf Shapes is a border router but hosts *its
own* network and cannot be moved onto yours without its credentials, which
Apple will not surrender without an Apple border router present.

## 8. Debugging discipline

- **Attribute traffic to the right device.** A shared Bluetooth adapter carries
  every BLE device in the house. Resolve the connection handle for the address
  you care about before reading anything into a capture.
- **One variable at a time.** Several hours here came from moving the device,
  reflashing and changing config between attempts.
- **Suspect your own instrumentation.** A capture that resets the device, a
  `pkill` that matches its own shell, an `sed` range whose end marker never
  matches — all produced confident, wrong conclusions in this build.

## 9. `attribute::update()` is a no-op for code-driven clusters

**Resolved 2026-08-23** — cause, fix and upstream status below. Symptom: the
device logs correct readings, a controller reads null for temperature and
humidity while battery reads fine, and HA creates no sensor entity at all
(it skips a sensor whose primary attribute reads null).

The investigation is kept in full because the elimination order is the reusable
part — every layer reported success, and the shape recurs.

What was established:

- Endpoints declare the right device types — `770` (0x0302 Temperature Sensor)
  on ep1, `775` (0x0307 Humidity Sensor) on ep2 — with clusters 1026/1029.
- `MinMeasuredValue` (`1/1026/1`) reads back `-4000` over the wire. Set from
  the same `config_t` by the adjacent SDK line. So the cluster is served fine.
- `MeasuredValue` (`1/1026/0`) reads null — whether set at creation via
  `temp_cfg.temperature_measurement.measured_value` or at runtime via
  `attribute::update()`.
- A forced `interview_node` (a live read of everything) still returns null, so
  it is not a matter-server cache artifact.
- Reading the attribute back on the device with `attribute::get_val()`
  immediately after the update returns `type=137` (nullable int16) with
  `i16=-32768` — the null sentinel — while `esp_matter_attribute` has just
  logged `Attribute 0x00000000 is 2437`.

So the value is lost inside `update()`, and that log line prints the requested
value rather than the stored one. Battery attributes on ep3 work at both
creation and runtime; they are the two the app creates explicitly with
`create_bat_percent_remaining` / `create_bat_voltage`, which is the only
structural difference found so far.

A controlled comparison narrows it to the attribute rather than the API. Both
calls are in the same function, one line apart, through the same `update()`:

```
DIAG in:               type=137 i16=2442                      <- value we construct is correct
DIAG after update():   err=ESP_OK  type=137 i16=-32768         <- temperature, nullable int16: LOST
DIAG after set_val():  err=ESP_ERR_NOT_FINISHED type=137 i16=-32768
DIAG battery readback: type=140 u32=680 (wrote 680)            <- battery, nullable uint32: STORED
```

So `esp_matter_nullable_int16()` builds the value correctly, `update()` returns
`ESP_OK`, and the store ends up holding the null sentinel — while the identical
pattern on `BatVoltage` stores fine. The only structural difference found: the
battery attributes are created explicitly by the app with
`create_bat_percent_remaining` / `create_bat_voltage`, whereas the measurement
attributes come from `endpoint::temperature_sensor::create()`.

Note `esp_matter_attribute`'s `Attribute 0x00000000 is 2442` prints the
*requested* value, not the stored one — the same "a log that cannot report
failure" shape as the `busy_wait()` defect in section 1. Do not trust it.

### Root cause: writes and reads use different stores

Established by writing a value that could not already be present and reading it
straight back:

```
DIAG after set_val(4660): err=ESP_OK   type=137 i16=-32768
```

`set_val()` returned `ESP_OK` — it stored — and the read immediately after still
returned the null sentinel. Writing the *same* value twice instead returns
`ESP_ERR_NOT_FINISHED`, which `set_val` only emits when `val_compare()` finds
the stored value equal to the new one. So the writes are landing.

Following the SDK:

- `set_val()` writes `current_attribute->attribute_val` on the `_attribute_t`
  struct, and `val_compare()` compares against that same struct.
- `get_val(attribute_t *)` does **not** read that struct. It resolves the path
  and delegates to `get_val(endpoint_id, cluster_id, attribute_id, ...)`, the
  path-based read that the Matter wire read also goes through.

For `MeasuredValue` those two are not linked, so every write succeeds and every
read returns null. For `BatVoltage` they are — and that attribute is created
explicitly by the app with `create_bat_voltage()` rather than by
`endpoint::temperature_sensor::create()`. That is the only structural
difference found, and it matches which attributes work.

Two consequences worth carrying:

- `attribute::update()` returning `ESP_OK` does not mean a controller will be
  able to read the value back. Verify over the wire, not from the return code.
- `esp_matter_attribute`'s `Attribute 0x... is <value>` log prints the
  *requested* value. It is not evidence of storage.

### Ruled out: bounds

The only difference between the two creation paths in the SDK is one line —
`create_bat_voltage()` calls `attribute::add_bounds()` and
`create_measured_value()` does not. Applying bounds to both MeasuredValue
attributes applied cleanly and did not fix the read. Bounds are not the cause.

### Resolved: reads and writes go to different objects (esp-matter v1.6)

Following the read path end to end: the path-based `attribute::get_val()` is
not a struct read. It runs a full simulated Matter read through
`data_model::provider::ReadAttribute()`, which is why the device-side read-back
and the wire read always agreed. That function checks, in order:

1. `mRegistry.Get(path)` — a registered code-driven server-cluster object
2. an `AttributeAccessInterface` for the cluster
3. `get_val_internal()` — esp-matter's own attribute store

`attribute::update()` writes store 3 only. esp-matter v1.6 registers a
code-driven `TemperatureMeasurementCluster` / `RelativeHumidityMeasurementCluster`
per endpoint (`data_model_provider/clusters/<cluster>/integration.cpp`), so
reads stop at step 1 and return that object's own `mMeasuredValue`, which is
never seeded — its `StartupConfiguration` carries min, max and tolerance only —
and never synced, because `temperature_measurement` has `function_list = NULL`
so `set_val_internal()`'s attribute-changed hook never fires. Min/Max survive
because the object reads them from the store at startup via `GetDefault()`.
PowerSource is exempt because esp-matter keeps it AAI-based ("uses AAI (not
SCI)" in its integration.cpp), so BatVoltage reads fall through to step 3.

**Espressif's own `examples/sensors/main/app_main.cpp` uses the same
`attribute::update()` call and is broken the same way on v1.6.** The same
applies to every measurement cluster with a registered SCI: pressure, flow,
illuminance, soil, air quality, occupancy, boolean state.

Fix (`sensor_loop.cpp`): set the value on the registered object.
`provider::registry()` is public, so

```cpp
auto *iface = esp_matter::data_model::provider::get_instance().registry().Get(
    chip::app::ConcreteClusterPath(endpoint_id, TemperatureMeasurement::Id));
static_cast<TemperatureMeasurementCluster *>(iface)->SetMeasuredValue(MakeNullable(v));
```

under the Matter stack lock. esp-matter's humidity integration already exports
exactly this as `RelativeHumidityMeasurement::SetMeasuredValue(EndpointId, ...)`
in its `integration.h`; the temperature integration has no header. Verified
over Thread: `1/1026/0 = 2463`, `2/1029/0 = 4952`, matching the device log.

Upstream status (checked 2026-08-23): this is **espressif/esp-matter#1798**
(2026-07-20, same root cause, same workaround) and **#1738** (2026-03-23, the
OccupancySensing sibling). Espressif confirmed it as a bug on both. On `main`:
`9a1c0777` (2026-07-23) makes `set_val` return `ESP_ERR_NOT_SUPPORTED` when the
cluster is SCI-served, and `3abe4c20` (2026-08-14) adds
`TemperatureMeasurement::SetMeasuredValue(EndpointId, ...)`. **Neither is on
`release/v1.6`** (tip `31b76ad1`, 2026-08-20), which is what this project pins,
so there the call still silently succeeds and there is no public setter. The
real fix — `update()` routing to the registered object — is still open.

When the toolchain moves to a release containing `3abe4c20`, the wrapper can
replace the downcast in `sensor_loop.cpp`; the registry approach keeps working
either way.

Rule to keep: **`attribute::update()` is only correct for attributes esp-matter
actually serves.** For any cluster with a local SCI integration, the served
value lives on the registered object and must be set there. Check
`data_model_provider/clusters/<name>/integration.cpp` for `registry().Register`.

## 10. Measuring sleep current with a manual-ranging DMM (AstroAI AM33D)

The meter on hand is an AstroAI AM33D: 2000-count 3½-digit, **manual ranging**,
DC current only. Read off the dial 2026-08-23:

| | |
|---|---|
| DC A ranges | **2000 µ · 20 m · 200 m · 10** |
| VΩmA jack | fused, **500 mA MAX**, 600 V MAX |
| 10 A jack | fused, **MAX 10 SEC EACH 15 MIN** |
| DC V ranges | 200 m · 2000 m · 20 · 200 · 600 |

2000 µA on a 2000-count display is 1 µA resolution — enough for a 15–40 µA
sleep floor. The problem is not resolution; it is what the meter does to the
device during a radio burst. Two consequences of the jack ratings: a C6 TX
burst (~100–300 mA) will **not** blow the 500 mA mA-jack fuse, so the fuse trap
below is mostly ruled out on this meter; but the 10 A jack **cannot** stay in
circuit through a boot and commissioning, so the bypass jumper in the procedure
is mandatory, not a convenience.

**The trap, in two forms.** Before trusting any number, rule out the
instrument. A XIAO ESP32-C6 user on the Seeed forum measured 57–80 mA where an
ESP32-H2 running identical code drew 2.5 mA and concluded the board was broken.
It was the meter: a flat meter battery plus the wrong input jack dropped enough
voltage across the meter to restart the C6 continuously. With that fixed the
real figure was ~2 mA. The failure mode is nasty because the device genuinely
misbehaves — it is restarting — so the reading looks like a real fault.

The mechanism is **burden voltage**: on a low current range the meter's shunt
is large (roughly 100 Ω for a 2000 µA range on this class), so a sleep-floor
reading is fine but a Thread TX burst of ~100–300 mA across that shunt drops
volts, browns out the C6, and it reboots — and this device bursts every
`CONFIG_ICD_SLOW_POLL_INTERVAL_MS` = 5 s, so you cannot wait one out. On many
meters of this class the burst also exceeds the mA-jack fuse (a blown fuse
reads as a device that draws nothing); the AM33D's 500 mA rating gives margin,
but check the fuse first if a reading is exactly zero.

**Procedure that works with this meter:**

1. Fresh 9 V in the meter. Check it first, not after.
2. Power the board from the cell (or a bench supply at 3.7–4.2 V) through the
   battery pads. **USB disconnected** — USB powers the board and bypasses the
   measurement entirely.
3. Put the meter in series with the battery **positive** lead.
4. Fit a **bypass jumper across the meter's leads** and keep it closed through
   boot and commissioning. The board never sees the shunt, and the 10 A jack's
   10-second limit never applies because the meter carries nothing until the
   device is asleep.
5. Once the device is attached to Thread and the panel is in deep sleep, move
   the red lead to the µA/mA jack, select the lowest DC range, then open the
   jumper. Read. If the display shows a reboot pattern (reading collapses and
   climbs every few seconds), the burst is browning it out — close the jumper.
6. To read a stable floor with bursts present, either raise
   `CONFIG_ICD_SLOW_POLL_INTERVAL_MS` in a measurement build so bursts are rare
   enough for the display to settle between them, or put a low-ESR bulk
   capacitor (1000–4700 µF) across the board's supply so bursts are sourced
   locally and the meter sees something close to the average. Say which was
   used when recording the number.

**What this meter cannot do:** capture the burst itself or a true average of a
bursty load. The per-poll and per-refresh charge figures in
[power-budget.md](power-budget.md) need a Nordic PPK2 or a µCurrent, as that
file already says. The AM33D answers one question — the sleep floor — and only
when the bursts are kept off it.

Record alongside the reading: meter range and jack, whether a bypass cap or a
longer poll interval was used, panel state, LED state, and whether the display
had refreshed within the previous minute.

## 11. There is no reference implementation for this build

Worth knowing when something does not work: as of 2026-08, nothing published
combines XIAO ESP32-C6 + esp-matter (ESP-IDF, C++) + Matter over Thread as a
LIT ICD + ePaper + battery + encoder. What exists:

- Seeed's wiki and marketing: "supports Matter and Thread", no working device.
- Seeed forum threads at Arduino / ESP LaunchPad level — sketches exceeding the
  1.3 MB limit, needing a "Huge APP" partition scheme, and commissioning that
  "added to Google Home but showed disconnected", HA discovery failing, and
  needing physical proximity to the hub. None of it diagnosed. In hindsight
  those read like the same two causes that cost days here: Thread coverage and
  a BLE proxy that cannot complete the BTP handshake.
- `github.com/Frapais/Sprig-C6` — a competent C6 board with battery management,
  but ESPHome/WiFi oriented, no display, ~32 mA average. Not a sleepy ICD.
- `tomasmcguinness.com/2025/01/06/lowering-power-consumption-in-esp32-c6/` —
  the only material found doing real Matter power work on this silicon. Worth
  reading before milestone 5.

Consequence: when something breaks there is no known-good implementation to
diff against, so budget for first-principles debugging and keep instrumenting.
One independent confirmation did turn up — the same light-sleep serial symptom
in section 2, reported verbatim ("device reports readiness to read but returned
no data") by another XIAO C6 user.

## 12. A version number in someone else's manifest is not a container tag

The manifest for matter-server was written on 2026-08-19 pinning
`ghcr.io/matter-js/matterjs-server:0.7.1`. That tag was released 2026-05-21 and
was already three months and twenty-plus releases stale on the day it was
written; current was 1.4.0.

The `0.7.1` came from the right-hand side of this line in
`kubernetes/apps/default/matter-server/README.md`:

> HA 2026.8.1's `manifest.json` requires `matter-python-client==1.3.0` and
> **`matter-ble-proxy==0.7.1`**

`matter-ble-proxy` is a **PyPI package** on its own numbering. The container
image is a different artefact with different versioning. The number was carried
across because it was sitting on the same line of the same file.

Cost: two evenings debugging a BLE commissioning failure, an upstream bug report
(matter-js/matterjs-server#1006), and a PR that was half redundant — for a
defect fixed upstream **twelve days after** the pinned tag. The maintainer
identified the build from the log format before we thought to check it.

Two things would each have caught it:

- **Ask "is this current?" when pinning anything.** One API call. The version
  was correctly stated in the bug report; nobody compared it to the latest
  release.
- **A working dependency bot.** Renovate was configured and running, had already
  detected the update, and had queued PRs for `v0.8.0` and `v1` — but six
  branches had errored on a `403` (`GET /commits/<sha>/statuses`, missing
  **Commit statuses: Read** on the token) and were holding all six
  `prConcurrentLimit` slots. Nothing new could be proposed. The backlog was
  visible only as unticked checkboxes on the dependency dashboard issue, which
  nobody opens.

Second-order lesson: **a guard that fails silently is worse than no guard**,
because it produces the feeling of coverage. Check that the bot is actually
opening PRs, not merely scheduled.

## 13. BLE is gone after commissioning, so reopening a window is not enough

`kFabricRemoved` reopened the commissioning window so an un-paired device could
be re-adopted without a physical factory reset. It never worked, for two
independent reasons, and the second one is the interesting one.

First: the window was opened with `kDnssdOnly`. Removing the last fabric also
takes the device off Thread, so it advertised on a network it had just left.

Fixing that to `kAllSupported` changed nothing. The device still advertised
**nothing at all** — `removeFabric` returned `statusCode: 0`, the `Leave` event
arrived, and `btmon` on the controller's own adapter saw zero `FFF6` reports.

The reason is in the SDK. With `CONFIG_USE_BLE_ONLY_FOR_COMMISSIONING=y`:

```cpp
void BLEManagerImpl::DeinitESPBleLayer()
{
    VerifyOrReturn(DeinitBLE() == CHIP_NO_ERROR);
#ifdef CONFIG_USE_BLE_ONLY_FOR_COMMISSIONING
    BLEManagerImpl::ClaimBLEMemory(nullptr, nullptr);
#endif
}
```

— `connectedhomeip/src/platform/ESP32/nimble/BLEManagerImpl.cpp:1004`

`ClaimBLEMemory` hands the BLE controller's RAM back to the general heap once
commissioning finishes. That cannot be undone in place. **No advertisement mode
could have worked, because there was no BLE stack left to advertise on.**

The fix is to reboot (3-second delay, so the RemoveFabric response and Leave
event get out first). A fresh boot with zero fabrics initialises BLE and
advertises the way first boot does. Verified: 2884 advertisement reports after
`remove_node`, unattended, where the same operation previously produced zero.

The general lesson: **a fix that is not tested on hardware is a hypothesis.**
The first fix was committed with a confident comment explaining reasoning that
turned out to be only half the story, and only failed testing revealed the rest.

## 14. Controllers cache device identity from the commissioning interview

`VendorName` / `ProductName` / `HardwareVersionString` are compile-time strings
(`CONFIG_CHIP_PROJECT_CONFIG` → `main/chip_project_config.h`), and the
controller reads them **once**, during the commissioning interview.

Reflashing corrected strings does not update what the controller shows. Verified:
after flashing, `strings` on the image confirmed `homecadia` present and
`TEST_VENDOR` absent, the flash hash-verified, the device rebooted and rejoined
Thread — and matter-server still reported `TEST_VENDOR` / `TEST_PRODUCT`. Only a
decommission and re-commission changed it.

Forcing a refresh does not work either. `read_attribute` is not a command
matter-server implements — it is silently dropped, no error, no log line. And
`interview_node` times out, because a complete read against a sleepy end device
on a 5-second poll exceeds the interview budget:

```
Interview requested for node @1:16 - do a complete read
WebSocket error response (interview_node) 1 [aborted] Operation aborted
    at abort.timeoutHandler (@matter/protocol/src/peer/Peer.ts:447:27)
```

Practical rule: **get device identity right before commissioning**, and treat
identity changes as requiring a re-pair. Per-unit naming belongs in NodeLabel,
set by the controller, not in VendorName/ProductName — all units share a model.

## 15. The panel FPC is the least reliable joint in the build — check it first

**2026-08-25.** Half a bench session went into a display that would not draw. It
presented as a dead panel and, for a while, as a firmware fault. It was neither:
the FPC was not seated correctly.

The symptom chain, in the order it appeared:

1. `BUSY never rose within 200ms of MASTER_ACTIVATE` on every refresh. The
   readings themselves were fine — `sensor_loop` reported real values every
   poll, so the whole software path ran and only the last step failed.
2. The panel kept showing an old commissioning QR. That is **not** evidence of
   an unpaired device: e-ink holds its last successfully drawn frame with no
   power, and every refresh after it had failed. The device was commissioned
   the whole time (`Fabric index 0x4 ... NodeId 0x17`). See also section 14.
3. MOSI (D10/GPIO18) could not be pulled low — it sat at **3.1 V** while the C6
   drove it low. Something was hard-driving it, not pulling it.

Bisecting by substitution found it, one variable at a time:

| Configuration | MOSI | Meaning |
|---|---|---|
| XIAO alone on USB | follows driver | GPIO18 healthy, no bridge on the XIAO |
| XIAO + driver board #2, no panel | follows driver | not normal behaviour for these boards |
| XIAO + driver board #1, no panel | follows driver | board #1 is fine |
| XIAO + board #1 + panel | **stuck at 3.1 V** | the panel was driving it |

MOSI is an *input* to the SSD1680 and should never drive that line. A misseated
FPC explains it: the ribbon carries supply rails (VDD, VGH, VGL) directly
alongside the signals, so a ribbon that is skewed or not fully home puts a rail
onto a signal net. That also explains why D10-to-3V3 measured **open** with the
board unpowered — the path only exists once the panel's rails come up.

Two things that would have saved the time:

- **A short is not always a bridge.** The unpowered continuity check said "no
  short" and was believed for too long. Anything gated behind a supply reads
  open until the board is powered.
- **A logic-level readback is not a voltage.** `gpio_get_level()` returning 1
  cannot distinguish a hard 3.3 V from an intermediate voltage above V_IH. The
  meter is what turned "stuck high" into "hard-driven by a supply".

After reseating, the fault became *intermittent* before it became fixed —
`BUSY` read high at rest on failing boots and low on working ones, and one boot
got a single command through before dying. Intermittent contact looks like a
flaky driver. It is not: it is a joint.

**Practical rules:**

- **Contacts face UP**, away from the driver board. That is the orientation
  this board expects — confirmed 2026-08-22 and again here. Full detail and the
  insertion-force cross-check are in [assembly.md](assembly.md).
- Reseat the FPC deliberately, once, and inspect it. Latch open before moving
  the ribbon, fully home, square at both edges, equal backing visible each side.
  Repeated blind reseating wears the contacts and is how board #2's connector
  died.
- Suspect the connection before the firmware. Every measurement in this session
  pointed at hardware, and every hour spent on the driver was wasted.
- `ssd1680_init()` now scans and drives each signal at boot and logs the result.
  Read those lines first — `drive hi=1 lo=0 follows the driver` on all five
  outputs is the precondition for anything else being worth investigating.

## 16. A diagnostic that runs after the driver owns the pin measures the driver

**2026-08-25.** Four traps from one bench session, all downstream of
instrumentation that ran too late or looked too shallow.

**The SHT40 probe was measuring the controller, not the wire.** The first I2C
line-state check in `sht40.c` ran *after* `i2c_new_master_bus()` on a failed
probe. It returned byte-identical readings — SDA held HIGH, SCL held LOW —
across every wiring change: sensor connected, sensor disconnected, cable
unplugged entirely. By the time it ran, the I2C peripheral already owned
GPIO22/23, held them with its own internal pull-ups, and was parked in a
stuck-bus state. Several wiring changes were requested on the strength of a
reading that could not have changed no matter what was on the bus.

Rule: **sample a pin before any driver claims it.** That is why the boot-time
harness scan (`firmware/sensor-01/main/bench_selftest.cpp`, gated by
`CONFIG_HOMECADIA_BENCH_SELFTEST`, set in `firmware/sensor-01/sdkconfig.bench`)
is the first call in `app_main()` (`app_main.cpp:199`), ahead of
`board_rf_switch_init()` (`:200`) — nothing has touched a pin yet. The probe
helpers were previously duplicated in `ssd1680.c` and `sht40.c`; they now live
once in `firmware/components/pinprobe/` (`pinprobe_line_state`,
`pinprobe_drive_test`), and `sht40_init()` calls `pinprobe_line_state()` on
SDA/SCL (`sht40.c:59-60`) before the bus is created two lines later.

**"Disconnected" means both ends out.** Same day, second lesson: encoder
jumpers pulled from the encoder end but left plugged into D7/D9 at the XIAO
end are unterminated antennas on two interrupt-enabled pins. The quadrature
ISR (`firmware/components/ec11_encoder/ec11.c` — the Gray table at lines
20–25, the 4-steps-per-detent accumulator at line 37) logged 411 valid-looking
detents in 25s with nobody touching the knob — each one a panel refresh,
~4,900 refreshes/hour against a panel rated for 1,000,000 cycles. Removing the
wires entirely dropped it to 0. An "isolation" test that leaves a wire in the
pin isolates nothing.

**The short that killed the SHT40 was in the breadboard, not on the board or
the panel.** The driver board's header pins sit in breadboard rows, so every
row it occupies is on a signal net — SCL was shorted to ground through the
breadboard itself, not through anything on the board or the FPC. Lifting the
board straight out of the breadboard (USB only) made SCL read floating at
boot. The timeline is the evidence: the sensor read fine through one capture
and failed on the next, and the only change between the two captures was
pulling encoder wires *on the breadboard* — the FPC was not touched. Bisect by
substitution, one reset per step, and read the timeline before touching the
ribbon.

**A line probe on a live bus is itself a fault injector.** A pull-up/pull-down
probe on a live I2C bus is itself a START condition — SDA falling while SCL is
high — so the probe can wedge an attached slave mid-transaction; afterwards
both lines read held LOW, which looks exactly like the dead-bus symptom the
probe was trying to characterise in the first place. Recovery is the standard
nine SCL clocks followed by a STOP. `bench_selftest()` issues that recovery
after probing the I2C pins (`i2c_bus_recover()`, `bench_selftest.cpp:19-47`),
and `sht40_init()` calls `i2c_master_bus_reset()` before its own probe
(`sht40.c:78`) for the same reason.

### Addendum, 2026-08-26 — three more from the encoder bring-up

- **A probe that reconfigures a pin kills whatever driver owns it.** The
  init-step bisect that found the SCL fault (`bench_probe_i2c()`) was left
  wired in after `ui_init()`. Each call ran `gpio_config()` on the encoder pins
  with interrupts disabled and pulls off, so the quadrature ISR never fired
  again and A/B floated. Two rounds of "the encoder produces no events" were
  the instrumentation, not the encoder. The function stays, with a warning in
  its header; the call sites are gone.
- **"Wired as in the diagram" is only right if the diagram is.** The diagram
  had the original D7/D9/D6 assignment; firmware had moved A to D6 and the LED
  to D7 an hour earlier. The drawing is now updated, but the rule is: after a
  pin move, the diagram, `pinmap.md`, `app_config.h` and the breadboard change
  in the same sitting or one of them lies.
- **EC11 blades do not seat.** Breadboard springs and Dupont sockets both
  grip a 0.64 mm square pin; the encoder's flat ~0.6 mm blades sit loose in
  either. Symptom: one line toggles cleanly while the other is stuck, and which
  one changes between runs. Soldered leads fixed it in one go.
- **D7 anomaly — closed 2026-08-31.** On both driver boards GPIO17/D7 read 0 V
  once `display_init()` brought up SPI; the meter read it open unpowered and
  the schematic has nothing on it. Cause found: plumbing-flux residue between
  the adjacent D7/D8 socket joints — see section 17. D7 followed SCK because
  they are neighbours, not because of anything electrical.

## 17. An ohmmeter cannot clear a powered-only path — and plumbing flux makes them

**2026-08-31.** Driver boards #1 and #2 both had 4–8 kΩ conduction between
*adjacent* socket pins (D2↔D3, D3↔D4, D7↔D8, D8↔D9, D9↔D10 — pairs with
nothing electrical in common, only physical adjacency). Every multimeter
resistance measurement of those pairs, on every range, powered off, read
open. Days went into substitution tests that could not succeed: both boards
were soldered with the same flux, so swapping boards was never an independent
trial, and the meter kept "clearing" the true fault.

**Why the meter lies:** a DMM's resistance test drives ~0.3 V. Ionic
contamination conducts electrochemically — it needs bias to move ions and
grow filaments. At 0.3 V: open. At 3.3 V: kΩ. The conduction also *drifts*
under sustained DC (watched live: 0.2–1.0 V wandering, pinning near 0, then
recovering — a fixed resistor cannot do that; ionic residue does).

**Root cause:** the flux was AIM **Nitro Flux — "a plumbing solder paste
flux"** per its own TDS, ASTM B-813 (copper *pipe* flux, water-flushable,
ionic by design). It is not an electronics flux. Every joint made with it
carries corrosive, hygroscopic residue that conducts under bias and keeps
corroding. IPA alone made it *worse* — it dissolves the binder and spreads
the ionic salts over more pads (observed: coupling count rose after an IPA
wipe).

**The measurement that works — pin-hold + voltmeter:**
`CONFIG_HOMECADIA_BENCH_PIN_HOLD` parks the pins with internal pull-ups on
and one neighbour driven low; a 10 MΩ DMM on DC volts reads the divider:

    V = 3.3 · R / (45k + R)
    3.3 V none · 2.3 V ≈ 100k · 1.65 V ≈ 45k · 0.33 V ≈ 5k · 0.03 V ≈ 450R

(The C6 pull-up is specified 10–80 kΩ — read order of magnitude, not value.)

**The clean that works — two stages, matching the two-component residue:**
1. IPA flood + brush, *drained off the board edge* (never wiped in place),
   to strip the rosin/binder.
2. Hot water + drop of dish soap, brush, then a distilled-water rinse, to
   dissolve the ionic salts (B-813 flux is water-flushable by design).
3. Dry hard: shake out socket bores, hair dryer low 10 min, an hour warm.

Verified on board #3: pre-wash 0.2–1.0 V drifting on D9; post-wash flat
3.1 V through every phase, and the first fully clean coupling scan ever
recorded on the assembled stack.

**Decoder rows:**
- *Uniform kΩ between many adjacent pins, resistance growing with distance*
  = a conductive sheet or joint contamination, not a circuit.
- *Coupling that only registers in one direction* = the follower's other
  loads (panel input leakage on MOSI/SCK) moved its threshold — not a diode.
- *Resistance that drifts under steady DC bias* = ionic/electrochemical, and
  no amount of solvent-wiping fixes it; wash the chemistry it matches.

**Standing rule:** electronics joints get rosin-core wire or a no-clean
electronics flux (J-STD-004). The plumbing paste stays with the plumbing.
After soldering headers: two-stage clean, dry, and one bench boot — the scan
must print `coupling scan: no pin follows any other` before anything else is
attached. New parts need that one 30-second scan, not days.

## 18. Never inject from a stiff source into a live GPIO

**2026-08-31.** XIAO #1 died measuring the leak. PPK2 source meter at 3.3 V
(1 A capability) clipped to D9 while the board ran — but the boot-time
coupling scan *drives* every pin, so within milliseconds of reset the C6
pulled D9 low against the source: a direct short through an output
transistor rated 40 mA. The PPK2 logged 0.68 A bursts. The smoke came out at
the opposite corner, by D0 — injected current also forward-biases the pin's
ESD clamp into the 3V3 rail, and the regulator (which lives by the USB end)
ate the rest.

Rules, in order of preference:
1. Measure **voltage** with the firmware holding the pins (pin-hold + DMM).
   Nothing external sources current; nothing can be harmed.
2. If current must be injected, put **≥1 kΩ in series** — caps any mishap at
   ~3 mA — and only into a pin the firmware provably holds as an input for
   the whole window, including reboots.
3. PPK2 source-meter mode is for **supply substitution** (battery pads, USB
   out, single supply) — never for signal pins on a powered board.

## 19. Two nodes within 0.2 V are indistinguishable by a one-point check

**2026-09-12.** The battery divider was "verified" on 2026-09-02 by one
reading: meter 1.57 V at the ADC pin, firmware 1.55 V, 1.2% apart. Both
numbers were wrong in the same direction. 1.57 V on a 10 MΩ meter across a
1 MΩ lower leg is 3.30 V at the top of the divider (the meter makes the
ratio 0.476, not 0.5) — while BAT+ was recorded at ~3.1 V the same day. The
mismatch was in the data and was rationalised as ADC tolerance.

The trap: with no cell fitted, BAT+ (charge IC output) and the 3V3 rail both
sit near 3.3 V. A divider on either node reads the same at that one point.
Ten days of "the battery always reads the same" followed.

**What separates them is a sweep, not a better single reading.** With the
PPK2 substituting for the cell (Source Meter, USB out), move the source
3400 → 4000 mV and re-read the node. A node on BAT+ follows; a node on the
rail stays at 3.3 V. Two points, in-circuit, ten minutes. That is now the
standard for any "verified against a meter" row: two source voltages, or it
is not verified.

The same session produced six readings that looked like faults and were
measurement artifacts, each of which triggered an intervention:

| Looked like | Was |
|---|---|
| Two dead packs, 0 V both polarities | probe on the JST housing rim, not the recessed contact |
| Dead pack after charging, 0 V | latched protection board; releases hours after charge starts |
| XIAO won't charge (LED blinking) | charging normally at 106 mA (spec 100 mA) |
| PPK2 reads 0.00 A | leads reversed; the PPK2 cannot read negative current |
| Short on the board (cell to 0 V "fast") | 41 mA sleep-disabled draw over three days, then the latch |
| Source not reaching BAT+ (0.6 V, decaying) | the wire had been unplugged to measure it |

Rules that came out of it, all cheaper than the interventions they replace:

- **Measure in-circuit.** DC volts with a 10 MΩ meter disturbs nothing. A
  wire unplugged to be measured reads the charge trapped on it.
- **One physical change, then measure-only until it is confirmed.** Two
  matching readings before acting on a surprise.
- **The PPK2 is the battery for bring-up.** It cannot latch, drain
  overnight, or be reversed at a JST. A cell goes on for a bounded session
  and comes off after — the bench profile draws ~41 mA and flattens a
  2000 mAh pack in about two days.
- **Read firmware from the glass.** The DIAG view shows `battery_mv`; no
  USB, so no second supply and no charge IC in the loop. It is the last
  poll's value (120 s), so wait a poll after changing the source.

What the sweep then found, once the wiring was trusted: the ADC reports a
constant 340 mV low at battery level (0.17 V at the pin), the same at 3.4 V
and 4.0 V. That is ~0.34 µA of ADC input current across the divider's
500 kΩ source impedance — the known cost of a high-value divider straight
into an ESP32 ADC, and a firmware constant, not a wiring problem.

## 20. An experimental sleep option hung the sensor the first time it really slept

**2026-09-15.** The shipping image had run for 40 minutes on USB without a
fault. On the PPK2 (Source Meter 3700 mV, USB out) it stopped waking 8
minutes after boot and never recovered: 10–33 µA, drifting, not one wake in
two minutes where a healthy sensor polls its Thread parent every 5 s. The
parent dropped it and the controller marked it unavailable.

**USB hides it.** `CONFIG_USJ_NO_AUTO_LS_ON_CONNECTION=y` keeps the C6 out of
automatic light sleep while a USB host is attached. A shipping-profile check
on USB therefore proves nothing about sleep; the first real light-sleep run
here was this one.

Lining the PPK2 recording up with the Matter server log placed the stop at
00:33:31 — two minutes after the previous sensor poll, i.e. at a poll (I2C
read of the SHT40, one ADC read). Everything before it looked normal: 5 ms
radio polls every 5.00 s, a report plus display refresh at 00:31:31, five
seconds of 500 ms fast polls after it.

Suspect: `CONFIG_PM_POWER_DOWN_PERIPHERAL_IN_LIGHT_SLEEP=y`. ESP-IDF v5.5.5
labels it EXPERIMENTAL and defaults it to n (`components/esp_pm/Kconfig`), but
it is not an oddity of this repo: both of Espressif's C6 sleepy-Thread
references turn it on (esp-matter `examples/icd_app`, IDF
`examples/openthread/ot_sleepy_device/light_sleep`), and the milestone-1
scaffold copied `icd_app`'s defaults nearly line for line. Those references run
on a DevKit-C with nothing attached. This build adds the XIAO — its antenna
switch is powered from GPIO3 and selected by GPIO14, both driven by the app —
plus SPI to the panel, I2C to the SHT40, the encoder GPIOs and an ADC read. So
the finding is "hangs on this build", not "Espressif's reference is broken".
One-variable test: a build with only that option off — the two sdkconfigs diffed to that
single line — ran 38 minutes on the PPK2 with no poll gap over 5.0 s and no
subscription loss.

| Run | Option | On PPK2 | Result |
|---|---|---|---|
| 00:25 | on | ~8 min | stopped waking at a sensor poll |
| 01:04 | off | 38 min | longest poll gap 5.0 s, no subscription loss |

One run each: strong evidence, not proof. The option stays off.

Wrong turns, each ruled out by reading the source before touching anything:

- *The display BUSY wait blocks the poll timer.* No — `display_show_readings`
  only queues; a separate task refreshes.
- *A stuck timer task stops Thread.* No — OpenThread's alarm runs off its own
  mainloop select timeout (`esp_openthread_alarm.c`), not esp_timer callbacks.
- *The SHT40 read waits forever.* No — every I2C call has a 50 ms timeout.
- *~900 "wakes" per second in the idle floor.* They are 50 µs pulses — too
  short to be light-sleep wakes. Origin still unverified.

**Save PPK2 sessions and parse them.** A `.ppk2` file is a zip:
`metadata.json` (`samplesPerSecond`, `startSystemTime` in epoch ms) and
`session.raw`, 6 bytes per sample — float32 current in µA, then a uint16 of
digital channels. With the start time the trace lines up with any log to the
millisecond; that is what placed the stop at a sensor poll.

Side finding: the +340 mV battery offset calibrated on the bench image reads
214–294 mV *high* on the shipping image. ADC error depends on the sleep
profile; calibrate on the image that ships.

Still open with the option off, and the reason the average is 696 µA against
a 300 µA target: every 20–40 s a 30 ms transmission drops the sensor into ICD
active mode for the 5 s threshold (500 ms fast polls). A bounded capture on the
border router's `wpan0` (Python raw socket inside the OTBR container — the node
has no tcpdump; 150 s, addresses and ports only) saw one Matter exchange in
that window, the 2 min keepalive. So the episodes never leave the link to the
parent, which reports a 20% frame error rate to the sensor at −77 dBm
(`ot-ctl meshdiag childtable 0xa800`). Espressif's SIT table uses a 1 s
threshold; ours is 5 s, inherited from their LIT table while the device runs as
SIT (no check-in client registered, `0/70/8` = 0).

## 21. The battery ADC kept the radio powered through every sleep

**2026-09-15.** With the hang fixed (§20) the shipping image still averaged
~700 µA against a 300 µA target, and the quiet stretches between radio polls
sat near 376 µA. Espressif's C6 DevKit-C trace for the same stack
(esp-matter `examples/icd_app/README.md`, image `C6-sit-icd.png`) reads
32–71 µA there.

**The trace looked like a wake storm. It was the regulator.** Between polls
98% of the charge arrived in ~2340 short pulses per second (they come in
pairs, ~1170 Hz; ~50 µs, 1–14 mA each) with 3–7 µA between them, and the rate
slid ~10% over the 5 s between polls, jumping back at each poll. That is the
XIAO's 3.3 V supply: U1 is an SGM6029 buck (XIAO-ESP32-C6_v1.0 schematic,
sheet 3/5 "03 Power"; L1 0.47 µH). Its VSEL/MODE pin has 249 kΩ to GND, which the datasheet
(Table 1) reads at startup as 3.3 V; after startup a low on the same pin
selects power-save mode. In power-save mode a buck draws from the battery in
bursts whose rate follows the load. Quiescent current is 2.3 µA typ
(datasheet), which with the divider's ~1.9 µA is the 3–7 µA between bursts.
The average is real; the pulse shape only says how big the load is.

**Instrument before guessing.** A diagnostic image
(`CONFIG_HOMECADIA_SLEEP_DIAG`, `main/sleep_diag.cpp`; how to build it is in
[build.md](build.md)) counts every automatic light-sleep request through the
esp_pm light-sleep callbacks, records the power-down flags IDF applied to each
sleep (`CONFIG_ESP_SLEEP_DEBUG` sleep context, bits from
`esp_private/esp_pmu.h`), and redraws the lot on the DIAG screen every 60 s.
It is read from the glass: a USB host keeps the chip awake.

| Measured (PPK2 3700 mV, USB out, 300–1020 s uptime) | Value |
|---|---|
| Light sleeps | ~2/s, all ≥3 ms, all ended by the timer; no GPIO wakes |
| Time asleep | 98–99% |
| Sleep time with the modem power domain on | **100%** |
| Sleep time with the 40 MHz XTAL on | 0% |
| BLE controller / NimBLE host task | idle / gone (torn down after commissioning) |

Ruled out on the way, each by source or by the counters:

- *A wake storm* — 2 wakes/s.
- *The USB-Serial-JTAG console* (ours; `icd_app` uses the UART) — the C6 does
  not define `SOC_USB_SERIAL_JTAG_SUPPORT_LIGHT_SLEEP` (soc_caps.h:354), so IDF
  disables the USJ pad and clock on every light sleep
  (`sleep_modes.c` `misc_modules_sleep_prepare`).
- *The panel left awake* — `ssd1680.c` sends deep sleep (mode 1) after every
  refresh.
- *GPIO3 held low into sleep.* 3.3 V across Q3's 10 kΩ gate pull-up is 330 µA,
  which fit the number exactly. Its IO_MUX register read `0x1802`: sleep select
  on, sleep output, pulls and input off. IDF already isolates it.
- *BLE keeping the XTAL and modem up* (`CONFIG_BT_LE_LP_CLK_SRC_MAIN_XTAL=y`)
  — controller idle, task gone, XTAL on 0% of sleep time.

**Cause.** `battery.cpp` created its oneshot ADC unit once in `battery_init()`
and never deleted it. On the C6 the ADC front end sits in the modem power
domain (`ADC_LL_ADC_FE_ON_MODEM_DOMAIN`, `hal/esp32c6/include/hal/adc_ll.h:41`),
so `adc_oneshot_new_unit()` calls
`esp_sleep_pd_config(ESP_PD_DOMAIN_MODEM, ESP_PD_OPTION_ON)` and only
`adc_oneshot_del_unit()` sets it back to OFF (`esp_adc/adc_oneshot.c`, IDF
v5.5.5). IDF powers the modem domain down only when that option is not ON
(`sleep_modes.c`, the `RTC_SLEEP_PD_MODEM` condition). With
`CONFIG_PM_POWER_DOWN_PERIPHERAL_IN_LIGHT_SLEEP=y` the same call also pins the
TOP domain on. Espressif's reference has no ADC. The fix creates and deletes the unit around each reading (every
120 s); the calibration handle is eFuse coefficients only and is kept.

**Measured the same day, diagnostic image with the fix:** modem domain on for
0% of sleep time (was 100%); last sleep's flags `0x20003c16`, MODEM bit set.
Quiet floor over a 1.3 s window with nothing above the buck's 13 mA bursts:
**282 µA**, against 376 µA before with the same config (PPK2 3700 mV). The fix
is worth ~95 µA: real, but a third of the excess, not the ~300 µA it was
expected to be. Still powered in every sleep: the TOP domain and the HP
peripherals (flag bits 0 and 3 never set). That is what
`CONFIG_PM_POWER_DOWN_PERIPHERAL_IN_LIGHT_SLEEP=n` (§20) leaves on, and
Espressif's reference runs with that option on. Before the fix the held ADC
unit also pinned TOP on in the option-on build, so no run here has ever
powered TOP down, including the one that hung. Next test: option on plus the
fix, watching for bit 0 and for the hang.

Also found in the same session:

- **The dial does not work on battery.** The encoder uses edge interrupts
  (`components/ec11_encoder/ec11.c`), which cannot wake the chip from light
  sleep (`gpio_wakeup_enable` accepts level types only, `esp_driver_gpio`
  `gpio.c`), and `CONFIG_PM_SLP_DISABLE_GPIO` disables every pin's input while
  asleep (`sleep_gpio.c` `esp_sleep_config_gpio_isolate`). Every dial test so
  far ran on USB, where the chip never sleeps. Open.
- **The CLOCK_SYSTEM retention module is inited but never created** (retention
  bitmaps `0x60000006` inited, `0x60000004` created). `top_domain_pd_allowed()`
  requires the clock domain to be allowed to power down, so this probably
  blocks TOP power-down whatever the peripheral option says — unverified.
- **One-minute PPK2 averages swing ±100 µA with radio traffic** (827 vs 645 µA
  on identical behaviour). Compare quiet windows or long averages.
- **Battery offset on the shipping image:** 3400 → 3676, 3700 → 3988,
  4000 → 4288 mV with the bench image's +340 mV applied — a constant +276 to
  +288 mV, slope 1.02. The fix changes the ADC's power state between
  readings, so it is re-swept after the fix rather than patched now.
**Later the same day: the TOP domain needs two driver flags, and the option
still hangs.** With the ADC fixed and
`CONFIG_PM_POWER_DOWN_PERIPHERAL_IN_LIGHT_SLEEP=y` back on, the TOP domain
*still* never powered down (flag bit 0 never set, floor unchanged at 279 µA).
The retention bitmap said why: I2C0 (bit 12) and GPSPI2 (bit 22) were inited
but never created. IDF's I2C and SPI drivers only build their sleep-retention
entries when the bus asks for it — `i2c_master_bus_config_t.flags.allow_pd`
(`driver/i2c_master.h`) and `SPICOMMON_BUSFLAG_SLP_ALLOW_PD`
(`driver/spi_common.h`, gate in `spi_common.c`) — and `peripheral_domain_pd_allowed()`
refuses TOP power-down until every inited module is created. Our SHT40 bus
(`components/sht40/sht40.c`) and panel bus (`components/ssd1680/ssd1680.c`)
set neither.

With both flags set and the option on:

| | |
|---|---|
| Last sleep's flags | `0x20007c17` — TOP (bit 0) and LP_PERIPH (bit 14) now powered down |
| Retention inited / created | `6040133e` / `6040133e` — everything created |
| Quiet floor | **56 µA** (106 ms selection), against Espressif's 55 µA reference |
| Sleeps ending early | ~2/s, still timer wakes; IDF appears to wake early to cover the retention restore (inferred) |

**And the §20 hang came back.** Last report 478 s after boot (matter-server:
subscription timeout at 16:48:04 less its 2 min 38 s), screen frozen at
`up 480s` with 882 sleeps counted, `is offline` 16:47:35, unavailable
16:50:35. §20's hang was ~490 s. Both stopped at the **4th** 120 s sensor
poll, not the first, and nothing in `poll_cb()` (`sensor_loop.cpp`) is
every-4th-poll: each poll does the same SHT40 read, battery read and
conditional report. Unexplained.

So the floor is a choice between two known states, until the hang is
understood:

| Shipping option | Quiet floor | Runs |
|---|---|---|
| `PM_POWER_DOWN_PERIPHERAL_IN_LIGHT_SLEEP=n` (current) | 282 µA | 38 min clean (§20), plus several runs today |
| `=y` with both driver flags | 56 µA | hangs at ~480 s, twice |

The driver flags stay in regardless: they cost nothing with the option off,
and they are required the moment it goes on.

**Cause found, same evening: a light sleep inside the ADC sequence.** Bisected
with `CONFIG_HOMECADIA_SLEEP_DIAG`'s poll variants, each run on the PPK2 with
the option on:

| Poll variant | Result |
|---|---|
| Full poll | hangs ~480 s (twice) |
| No poll at all | 1490 s clean |
| Poll without the battery ADC read | 1176 s clean (SHT40, report and refresh all running) |
| Full poll, ADC sequence under an `ESP_PM_NO_LIGHT_SLEEP` lock | **1231 s clean** |

`adc_oneshot_new_unit()` changes the sleep power-domain configuration (modem,
and TOP when peripheral power-down is on) and `adc_oneshot_del_unit()` changes
it back. Nothing stopped a light sleep landing between those two calls, and a
sleep that started mid-change never woke. That also explains the "4th poll"
pattern that looked like a counter: the window is a few ms per 120 s poll, so
which poll loses the race is chance. IDF has no ADC sleep retention yet
(`esp_adc/adc_oneshot.c`, `TODO: IDF-8475`), which is why it pins domains
instead.

Fix: `battery.cpp` holds an `ESP_PM_NO_LIGHT_SLEEP` lock across create, read
and delete, ~10 ms per poll. With it, `CONFIG_PM_POWER_DOWN_PERIPHERAL_IN_
LIGHT_SLEEP=y` is back on in `sdkconfig.defaults` and the numbers are:

| | Before today | Now |
|---|---|---|
| Quiet floor | 376 µA | **52 µA** (4.1 s selection; Espressif's DevKit reference is 55) |
| All-in average | 645–827 µA | **230 µA** over 74 s including a heavy radio burst; 107 µA over a quiet 9 s |

That is ~10 months on 1700 mAh at the pessimistic figure, against 3.3 months
this morning, and it is the first number inside the 300 µA budget.

**Flashing a power-down-on image wedged the USB port.** The first plug-in
after that image ran gave Windows `Unknown USB Device (Device Descriptor
Request Failed)` and esptool could not open the port. Holding the **B** button
while plugging in (ROM download mode never sleeps) flashed first try. Six
plug-ins on option-off images had been fine.

- **The first `get_node` after a reflash can be the server's cache.** The
  interview returned and the attributes still showed the previous boot's
  reboot count and uptime; the next read 25 s later was current. Check
  `0/51/1` (reboot count) moved before trusting anything else.

## 22. After the sleep floor, the radio is the budget

**When:** 2026-09-16, the first overnight soak of the shipping image
(`0.6.0-dev.84+e0760b0`, both §21 fixes,
`CONFIG_PM_POWER_DOWN_PERIPHERAL_IN_LIGHT_SLEEP=y`).

**Run:** PPK2 Source Meter 3700 mV, USB out, 15:18 → 22:56. The PC lost power
before the intended start the previous evening, so the run began the next
afternoon. Node 25 answered a fresh `interview_node` at +85 min, +7.7 h and
after the run; no hang (the §20/§21 hang reproduced at ~480 s).

| Selection | Average | Charge | Note |
|---|---|---|---|
| Whole run, 7:38:36 | **288.5 µA** | 7.94 C | includes boot, Thread attach, five interviews |
| One 120 s report cycle at +5 h 31 min | **240.6 µA** | 28.87 mC | the settled number |
| 1.79 s between polls | 59 µA | 105.8 µC | matches the 52 µA §21 floor |

**What the 240 µA is.** The 2-minute window shows three things: a flat
59 µA floor; 22 evenly spaced ~250 mA spikes 5.3 s apart; and a cluster of
~10 spikes 0.5 s apart right after the report. Per spike ~0.58 mC (from a
1-minute window: 9.54 mC minus 60 s of floor, over 11 spikes). So:

| | per 120 s | µA |
|---|---|---|
| floor | 7.1 mC | 59 |
| slow polls, `CONFIG_ICD_SLOW_POLL_INTERVAL_MS=5000` (SDK default, never set by us) | ~12.8 mC | ~107 |
| fast-poll tail, `CONFIG_ICD_FAST_POLL_INTERVAL_MS=500` for `ACTIVE_MODE_THRESHOLD_MS=5000` after the report | ~5.8 mC | ~48 |
| sensor read + report | ~3 mC | ~25 |

The Thread parent polls cost twice what the chip does asleep. Yesterday's
"107 µA over a quiet 9 s" was a window with no report in it; a 1-minute window
today read 159 µA for the same reason. **Only a window that spans a full
report cycle is a settled average**; anything shorter is a floor-plus-luck
number.

**What changed.** `CONFIG_ICD_SLOW_POLL_INTERVAL_MS=30000` in
`sdkconfig.defaults`. Two things verified in the SDK first:

- The active-mode threshold stays at 5000. It is the LIT spec minimum;
  1000 trips `ICDManager.cpp:82` and boot-loops (already recorded in
  `sdkconfig.defaults`). The fast tail is not recoverable by config.
- A LIT-capable device with no registered ICD client operates as SIT and
  uses `min(LIT interval, SIT interval)` with the SIT interval capped at
  `CHIP_DEVICE_CONFIG_ICD_SIT_SLOW_POLL_LIMIT` = 15 s
  (`ICDConfigurationData.cpp:25-40`, `CHIPDeviceConfig.h:159`, release/v1.6).
  So the poll spacing in the next trace tells whether the matter-server
  registered as a client: 30 s means LIT, 15 s means SIT. Either is a cut.

Expected: ~107 µA → ~18 µA (30 s) or ~36 µA (15 s), settled cycle 240 →
~150–170 µA. Cost: a controller-initiated command waits up to one interval;
subscriptions and the 120 s report are unaffected.

**Result, 2026-09-17 (12 h 37 min, 23:26 → 12:03, no hang).**

| | 5 s poll (09-16) | 30 s configured (09-17) |
|---|---|---|
| Poll spacing in the trace | 5.3 s | **15 s** — SIT clamp, no ICD client registered |
| Whole run | 288.5 µA over 7.6 h, five interviews | **237.7 µA** over 12.6 h, three interviews |
| One settled 120 s cycle | 240.6 µA, 28.87 mC | **207.8 µA**, 24.94 mC |

The cycle saved 3.9 mC, about half of what the poll count alone predicted
(22 → 7 polls ≈ 8.5 mC). The other half went into the active period around
the report, which grew from ~8.8 mC to ~13.6 mC: about twelve spikes reaching
390 mA where the 5 s trace had about ten at 250 mA. Cause not established.
Per cycle now: floor ~59 µA, polls ~35 µA, report active period ~113 µA. The
next lever is how often that active period happens
(`CONFIG_ICD_IDLE_MODE_INTERVAL_SEC` and the 120 s sensor poll), not the polls.

Two measurement traps from this run:

- **A window taken ten minutes after boot read 309 µA** with a cluster of
  twelve 300–400 mA spikes, and looked like the change had made things worse.
  The same image at +12 h read 208 µA. The matter-server re-subscribes and
  re-reads after a node returns; nothing measured in the first half hour is a
  settled number.
- **One `interview_node` costs ~150 mC** — a 2:00 window containing one read
  1.26 mA against 0.21 mA without. It reads every attribute on the node. Three
  of them are 0.45 C of this run's 10.79 C; the five in the 09-16 run were
  ~10 % of its total. A liveness check is not free on a device budgeted in
  microamps; use the PPK2 trace (polls still arriving) as the liveness signal
  instead.

## 23. A meter on a high-impedance node is a load, not a reference

**When:** 2026-09-22, calibrating the battery ADC on the shipping image.

With the PPK2 at 3.70 V the meter read BAT+ 3.67 V and the divider midpoint
1.73 V, a ratio of 0.471 for a 1M:1M divider. I took 0.471 as the divider's
real ratio, compared the firmware's pin voltage against 1.73 V, found them
within 13 mV, and concluded the offset should be 0. Flashed, and the reading
came out 64–144 mV **low**.

The midpoint has a 500 kΩ source impedance. The meter's 10 MΩ input is in
parallel with the bottom leg and pulls the node down ~5 %: 0.5 × 10/10.5 =
0.476, which is what it read (0.471 with tolerance). The ADC's own input does
the same thing, less strongly (~1.9 %). Comparing one loaded reading against
another loaded reading measured nothing.

The fix was to calibrate only against **BAT+**, which is driven by the PPK2
and has near-zero impedance, so the meter cannot move it. Two points, BAT+
3.68 and 4.00 V, gave the same gain (×1.0176, ×1.0201) and no offset, which
is what input loading should produce. A third point the fit never saw, 3.39 V,
read 3389 and 3387.

Rule: **calibrate an ADC chain end to end, from a low-impedance source to the
number the firmware reports. Never use a meter reading of a node with more
than ~10 kΩ source impedance as the reference.** A meter on such a node is
fine for "is it roughly there", not for millivolts.

Two other things this sweep showed:

- **One Matter report is not a measurement.** At 8 samples after a 5 ms
  settle, reports at a fixed voltage scattered ±120 mV; a single report
  looked like an offset change twice. 64 samples after a 20 ms settle (the
  500 kΩ ‖ 100 nF node has a 50 ms time constant) brought it to 4 mV. Take
  several reports per point and hold each point for ≥ 3 report periods; one
  slider move inside a 120 s poll produced a mixed reading.
- **The "dead node" of 2026-09-22 was a broken hookup wire.** The PPK2 read
  1.84 µA at 3.7 V, exactly 3.7 V over the 2 MΩ divider: the divider was the
  only load, so the XIAO was not on the node. Arithmetic on a flat current
  identifies what is connected faster than any probe.

## 24. The border router forgot the network; the node never did

**When:** 2026-09-21 20:19 → 2026-09-22 21:30.

The Kubernetes node hosting the OTBR rebooted. The OTBR pod came back on
OpenThread factory defaults (PAN ID `0xffff`, channel 11, Thread disabled):
its settings file lives in `/var/lib/thread`, and the persistent volume had
been mounted at `/data` since 2026-08-19, a path the image's entrypoint never
links. Fixed in the homelab repo (PR #373: mount at `/var/lib/thread`); the
dataset was restored from Home Assistant's store.

What that looks like from this project's side:

- matter-server logs `ENETUNREACH` to the node's old mesh-local address every
  2 min, and the HA cache keeps serving the last values, so a `get` read
  looks healthy with stale numbers. Check `last_interview` and the OTBR
  (`ot-ctl state`) before blaming the device.
- The off-mesh-routable prefix is regenerated when the OTBR loses its
  settings (`fd20:22ab:77:1::/64` → `fd98:ce54:c5cd:1::/64`). Nodes re-register
  with SRP on the new prefix by themselves; no re-commissioning. The node's
  own Thread credentials are in its NVS and survived untouched.
- `srp server host` stayed empty for an hour after the OTBR recovered. That
  was not the prefix: node 25 was unpowered (§23, broken hookup wire). Once
  powered it attached, registered and was re-interviewed by matter-server
  within two minutes, `RebootCount` +1.

**2026-09-28, the fix held.** The same node (`k8sn3-agent`) went down twice
in one afternoon. Both times the OTBR pod came back attached as a router on
channel 15 with no restore, and node 26 rejoined by itself: `RebootCount` did
not move across the first outage, and the controller resubscribed within
about a minute of the matter server returning (16:27:24).

## 25. Three faults, none where the symptoms pointed

**When:** 2026-09-24 → 2026-09-28, XIAO #3 then #4.

The dial did nothing on a freshly soldered XIAO. Four days of symptoms:
D6 at 0 V with nothing attached, every encoder wire reading open, the board
vanishing from USB whenever the knob turned, the press never registering.
The causes, in the order they were found:

| Symptom | Cause | How it was found |
|---|---|---|
| 0 V on D6, D5, the 3V3 pin and the 5V pin; no beep on any encoder wire | **meter probe lead loose in its jack** | the 5V pin read 0 V while the board was enumerated on USB, which no board fault can produce |
| board drops off USB on the first detent; encoder A never changes in the log | **encoder wire soldered to the 3V3 pad, which sits beside MTCK** | MTCK wire beeped to the 3V3 header pin |
| press never registers | **wire loose in the D9 breadboard row** | found by hand after rotation worked |

Wrong turns on the way, each of which was written up as a conclusion before
it was tested:

- **Flux residue on D6.** The 0 V readings matched §17 exactly (0 V under
  bias, open unpowered), and a pin swap in firmware was planned around a
  "dead" GPIO16. The flux was a no-clean pen and the pin was fine: 3.27 V
  once the meter worked.
- **Encoder wires not reaching their pins.** Both beep tests "failed" on
  wires that were connected. A loose probe cannot beep.
- **MTCK bridged to BAT+.** Proposed from the board dying when contact A
  closed. One voltage reading (3.26 V on the wire, 4.04 V on BAT+) killed it.
- **Wire tugging.** The reset followed the knob, so handling was blamed. The
  log showed the last line before the drop was the first contact closure.

What decided it each time was a measurement that could only come out one way:

- **A reading the fault cannot explain identifies the instrument.** A board
  that is enumerated on USB has 5 V on its 5V pin. Check the meter against a
  known source before believing a run of zeros.
- **The chip's own reads stayed right throughout.** `encoder raw` lines and
  the harness verdicts come from the pins, not the meter. When the two
  disagree about a powered board, the firmware is the better witness.
- **The harness said `held HIGH` for GPIO6 on the miswired board.** The probe
  applies a pull-down, so a free pad is expected to follow it. The note in
  `bench_selftest.cpp` explained the reading away as the JTAG pull-up. What a
  correctly wired MTCK reads is not recorded, so this stays a hint, not a
  verdict; turning the knob is the test.
- **Isolate by removing the other signal.** With B pulled from its row and
  only A connected, the first detent still killed the board and no line
  reached the log. That put the fault on A with nothing inferred.
- **An ePaper panel is not a liveness signal.** It kept its image through
  every power loss. The COM port was the only indicator.

Process changes, now in [assembly.md](assembly.md):

- Test before glue. The glue hid which pad each wire was on, and XIAO #3
  lost its pads in the handling that followed the glue's removal.
- Identify pads by exclusion, unpowered: beep each signal wire against 3V3,
  5V and GND, and against GND with the B and R buttons held (BOOT and EN).
  What is left can be corrected in `app_config.h`.
- Prove them powered: the battery reading proves MTMS and BAT+, three
  detents each way prove MTCK.

## 26. An unpaired unit does not sleep

**When:** 2026-09-28, XIAO #4, shipping image, PPK2 3700 mV, USB out.

Before commissioning: **28.1 mA average** over 10 s, baseline 20–40 mA,
~200 mA spikes every 0.5 s, matching the 500 ms advertisement interval the
firmware logs after its first 30 s. `CONFIG_PM_ENABLE` and
`CONFIG_BT_LE_SLEEP_ENABLE` are both set, so the build is able to sleep.
Three minutes after commissioning, same unit, same source: 91 µA over a quiet
10 s.

**Cause: not known.** The explanation written here on 2026-09-29 was wrong
and is kept below, struck, because the mistake is instructive: ESP-IDF's
OpenThread port creates a power-management lock named
`ot_sleep` and takes it at init (`components/openthread/src/port/
esp_openthread_sleep.c`, `esp_openthread_sleep_init()`). It gives the lock
back only when the 802.15.4 radio reports the state
`ESP_IEEE802154_RADIO_SLEEP` (`esp_openthread_sleep_process()`, same file). A
unit with no Thread network never starts the Thread interface, so nothing
puts the radio into that state and the lock stays held. Any held lock blocks
light sleep. Bluetooth is not the cause by this reading: its controller has
its own lock and releases it between advertisements. No lock in this
project's own code is tied to pairing state (`battery.cpp`, `ui.cpp` and
`ec11.c` hold theirs for milliseconds to seconds). To confirm: run the sleep
diagnostic image (`CONFIG_HOMECADIA_SLEEP_DIAG`) on an unpaired unit and read
which locks are held.

**Retracted 2026-10-02:** that lock is created as `ESP_PM_APB_FREQ_MAX`,
which only keeps the bus clock up while awake; it does not block light
sleep (`ESP_PM_NO_LIGHT_SLEEP` does). The USB console of an unpaired unit
also drops about 30 s after boot, when Bluetooth moves to slow advertising,
which suggests it does light-sleep from then on. Measured since: with the
window closed but before deep sleep, the unit draws a few mA; it is the
window's advertising that costs ~28 mA (29.2 mA, 2026-10-01).

**Decision 2026-09-29, done 2026-10-02:** an unpaired unit goes to deep
sleep once its window has closed, and a turn of the dial brings it back with
a new window. 19.7 µA asleep; how it got there is §27.

Two consequences:

- A dial test on an unpaired unit proves the wiring and nothing about wake
  from sleep. The first "works on battery" result was exactly that and was
  withdrawn. The valid test is a detent on a paired, settled unit, with the
  trace showing a flat baseline before and after
  ([bringup.md](bringup.md), Encoder & LED).
- At 28 mA a 2000 mAh cell lasts about three days. Pair a unit before it
  goes on a cell.

## 27. Deep sleep from a running Matter device: four designs, one that works

**When:** 2026-09-29 → 2026-10-02, XIAO #4. Goal: an unpaired unit asleep,
woken by the dial.

| Design | On USB | On battery |
|---|---|---|
| 1. `esp_deep_sleep_start()` from the running system | slept; the boot after a wake **hung for 25 h** (task watchdog, `main` stuck in GPIO interrupt setup) | not tried |
| 2. same, light sleep off (debug image) | slept, woke on the dial | not tried |
| 3. same, shipping config, wake pin taken out of sleep isolation, clean restart after a wake | slept 12 min untouched; dial woke it 7 of 8 | **stuck at ~20 mA**, never reached sleep, deaf to the dial |
| 4. **restart first, sleep from the top of the next boot** | 5 of 5 | **19.7 µA, 5 of 5** |

What each failure turned out to be, as far as it was established:

- **Woke by itself within seconds** (design 1 on the shipping config):
  `CONFIG_PM_SLP_DISABLE_GPIO` sets every pin to an isolated, floating state
  in sleep. The wake pin floated to its wake level. Fixed by taking the wake
  pin out of the sleep switch and setting its pull-up explicitly.
- **Hung boot after a wake:** the woken boot inherits the wake pin's pad
  hold and LP wake setting. Fixed by releasing both and taking one ordinary
  software restart before anything else runs.
- **Stuck at ~20 mA on battery only:** ESP-IDF's sleep docs require the
  radios to be stopped before deep sleep (`sleep_modes.rst`), and the
  deep-sleep entry runs PHY shutdown hooks with interrupts off. On USB the
  connection blocks light sleep, so the radio block is never powered down
  between advertisements; on battery it is. The best-supported reading is
  that entry stalls on a powered-down radio. Not proven; design 4 removes
  the question by sleeping before any radio exists.
- **Awake indefinitely after a failed pairing:** the SDK re-opens the window
  for a retry with no timeout of its own (`CommissioningWindowManager::
  HandleFailedAttempt`). Fixed by an uptime cap: 16 min after boot the unit
  sleeps whatever the window says, unless a pairing holds the fail-safe.

**The 6,100 restarts.** During a failed phone pairing on 2026-10-02 the
unit restarted about 6,100 times in 54 minutes (`RebootCount` 30 → 6131),
which the PPK2 showed as a steady 67 mA with a spike every ~0.6 s. It was
first read as "awake" and then blamed on the firmware. Two deliberate
reproductions on USB, one with the window closing mid-pairing, paired
cleanly. The next restart the device reported, on 2026-10-03, gave
`bootReason: 2`, a **brown-out reset**. The rate (~0.5 s) matches the
battery-path episode of 2026-09-28 ([battery-runbook.md](battery-runbook.md)
B3): a supply through breadboard contacts sags under the radio's bursts.
The PPK2 measures at its own terminals and cannot see that sag.

What the debugging tools did, because each one misled at least once:

- **The USB console is not evidence of anything on the shipping config.**
  The port stays listed while the chip sleeps and every open fails; it also
  drops ~30 s into an unpaired boot. A "port vanished" was read as deep
  sleep when it was light sleep. Captures need a listener that reopens a
  dead handle (the first one held it and recorded nothing three times).
- **The panel is not a liveness signal** (§15). A test build drew
  `rst<reason> wakes<count> cause<cause>` on the onboarding screen instead;
  that line answered questions the console could not.
- **The PPK2 needs the right zoom.** At 1-minute zoom a buck converter's
  ~1 kHz pulse train looks like radio activity; at 1-second zoom it is a
  flat 20 mA. Read the 10 s average, then zoom to the event.
- **`bootReason` in the controller** names the cause of the last restart
  and costs nothing to read. It settled the restart loop after two days of
  inference.
- **A build directory can keep an sdkconfig from before new Kconfig
  options existed** and compile a feature out without an error. The profile
  check now asserts the option is on in shipping.

## 28. A level interrupt on a pin that light sleep isolates

**When:** 2026-10-04 → 2026-10-05, XIAO #4 (node 28), PPK2 at 3700 mV.

**Symptom.** Paired, settled, the sleep floor was 73–76 µA against 59 µA in
September, every parent poll cost ~0.76 mC against ~0.54, and the chip made
1 ms wakes with no radio activity at 4–120 a minute. The extra floor charge
arrived as ~10 mA × 50 µs pulses, ~120 a second on a ~3.1 ms grid.

**Ruled out first, from the captures and without touching the board:**

- the measurement method (the same script gives September's capture 59 µA);
- longer BAT leads (series resistance adds no current; leakage would show in
  the between-pulse current, which went *down*);
- the encoder A pull-up against a closed contact (floor flat across detents);
- the dial's GPIO wake keeping `RTC_PERIPH` on (`sleep_modes.c:2697-2699`):
  `CONFIG_HOMECADIA_DIAG_DIAL_WAKE_DELAY_S` A/B in one capture, ≤3 µA;
- Thread reattachment (diagnostics counters: no attach attempt or parent
  change in 2 h).

**Bisect, app-only flashes on the same board:**

| Image | Floor | Charge per poll | Stray wakes |
|---|---|---|---|
| `f798d25` (2026-09-22) | 49 µA | 457 µC | 0.2/min |
| `07457a1` (2026-09-23, switch on MTDO/GPIO7) | 45 µA | 446 µC | 0.6/min |
| `58a3cb5` (switch on D9/GPIO20 since `7d25512`) | 73 µA | 745 µC | 4–120/min |
| `58a3cb5` + fix | 57 µA | 478 µC | 1 in 49 min |

The resolved sdkconfigs of the first and third differ only in ICD settings,
`CONFIG_ESP_SLEEP_GPIO_ENABLE_INTERNAL_RESISTORS` (deep-sleep wake pins only,
`esp_hw_support/Kconfig:207-212`) and `CONFIG_MDNS_ENABLE_BROWSE`. Between
`07457a1` and the regression, only `7d25512` touches the paired sleep path:
the push switch moved from LP GPIO7 to HP GPIO20, still on a
`GPIO_INTR_LOW_LEVEL` interrupt.

**Cause, as far as it is established.** A wake-source pin keeps its pad
config in light sleep; any other pin is isolated by
`CONFIG_PM_SLP_DISABLE_GPIO` (input and pull off), and an isolated input reads
low — the level the switch interrupt is armed for. Keeping GPIO20's awake
config through sleep (`gpio_sleep_sel_dis()`, `ui.cpp` `push_switch_init()`)
removes all three symptoms; the press still registers. How the false level
turned into the pulse grid and the heavier polls was not traced (inferred:
the interrupt fires on each wake and runs the switch task's 20 ms debounce).

**Result:** 185 → 125 µA settled (power-budget.md). ~10 µA of floor above
`07457a1` remains, unexplained; the floor also drifted 50 → 58 µA within one
50 min capture.

**Rules:**

- Any HP GPIO with a level interrupt needs `gpio_sleep_sel_dis()` (or an
  edge interrupt) when `CONFIG_PM_SLP_DISABLE_GPIO` is on.
- Moving a pin between LP and HP GPIOs changes its sleep behaviour; re-measure
  the floor after any pin move, not only after "power" changes.
- An app-only bisect on the same board separates firmware from hardware in
  one flash; keep the captures and the bisect images.

## 29. The bottom of the battery: warning, brown-out, empty

**Setup.** 2026-10-05/06, node 28 (XIAO #4) paired, PPK2 Source Meter on the
BAT wires, USB out, the supply stepped down by hand. Readings are the
`3/47/11` reports through the Matter server (`tools/matter-node.py`).

| PPK2 (mV) | Reported (mV) | % | What happened |
|---|---|---|---|
| 3700 | 3690 | 40 | |
| 3553 | 3564 | 14 | |
| 3500 | 3511 | 8 | low-battery mode on (below `LOW_BATTERY_PCT` 10, i.e. under 3530 mV) |
| 3400 | 3401 | 2 | |
| 3300 | 3297 | 1 | no report from the % change: 1 % hysteresis needs a 2-point drop |
| 3100 | 3099 | 0 | (forced report) |
| 3000 | — | — | runs |
| 2900 | — | — | old firmware: `RebootCount` 141 → 639 in ~10 min, panel redrawing |

The reading is within ±11 mV of the source from 3.7 V down to 3.1 V.

**Three defects, fixed:**

1. *The low-battery LED pulse was two ~2.5 ms flashes.* The chip
   light-sleeps inside the 100 ms pulse; with peripheral power-down the GPIO
   domain goes down with it. `gpio_sleep_sel_dis()` (the §28 fix) did not
   help — capture `ppk2-20261006T015052`: wake pairs 100 ms apart every 10 s,
   under 2 mA between them. The pad hold does: `gpio_hold_en()` keeps a level
   through "peripheral power-down in Light-sleep" (`driver/gpio.h`, IDF
   v5.5.5); it latches level, output enable and drive strength in the LP_AON
   domain (`LP_AON.gpio_hold0`, `gpio_ll.h:403-405`). `led.cpp` `set_led()`
   releases, sets and re-latches it on every change; now a single full flash.
   The capture showed only ~51 µA extra during the pulse, but in that capture
   the regulator's refill pulses ran 42–45x faster during the pulse while the
   reading rose 18–20x and the charge per refill halved: the PPK2 under-read
   there (the same capture's 3500 mV floor, below). Scaled by the pulse rate
   the LED takes roughly 1–2 mA; not measured directly.
2. *Below 2 % Home Assistant stopped seeing the battery fall.* Below
   `LOW_BATTERY_PCT`, any 1-point drop now reports (`sensor_loop.cpp`).
3. *A flat cell restarts the unit about once a second*, radio and panel each
   time — the worst load for a cell at its protection cutoff. A *running*
   unit rode out 2900 mV on the new firmware (uptime unbroken, 2879 mV
   reported); the loop is boots failing, which fits about one per second.
   `empty_battery_on_boot()` (`app_main.cpp`) reads the battery before the
   radio exists: below 3100 mV (3300 mV after a brown-out, or once an empty
   spell has begun) it draws one large-text "BATTERY EMPTY" screen, restarts,
   and deep-sleeps with the dial and an hourly timer as wakes. A running unit
   reading under 3050 mV restarts into the same check (`sensor_loop.cpp`).
   Verified: a cold boot at 2900 mV and a running unit taken to 3000 mV both
   end on the screen and asleep; at 3700 mV a turn of the dial brought the
   unit back paired.

**The empty sleep costs depend on the supply, not the firmware.** Same deep
sleep, never woken: **298 µA at 2900 mV** (captures `…T030820`,
`…T031355`), **21.2 µA at 3700 mV** (`…T031731`, 145 s flat). Drawing,
restarting and then sleeping (the unpaired path's order, §27) made no
difference at 2900 mV, and neither did isolating the divider pin GPIO4 with
`rtc_gpio_isolate()` (298.9 µA, capture `…T050631`; tried and removed). Below
~3.3 V in, the SGM6029 runs at 100 % duty and passes the battery through
(datasheet, "100% Duty Cycle Operation Mode", p.16; no quiescent figure is
given for that mode), and the trace is flat DC with no bursts. The rail then
sits at ~2.9 V, under the C6's 3.0 V minimum (datasheet v1.5, Table 5-2), so
its 7 µA deep-sleep figure no longer applies. Hardware either way; firmware
cannot recover it. Not separated: regulator vs chip (feed 3V3 directly at
2.9 V to tell them apart).

**Brown-out level 7 is ~2.51 V on the 3V3 rail** (IDF v5.5.5
`esp_hw_support/power_supply/port/esp32c6/Kconfig.power:24-25`, an Espressif
estimate; the detector watches VDDA3P3/VDDA1/VDDA2, TRM v1.2 §12.4.4). Until
the app sets it, the detector runs at its hardware default of ~2.7 V with a
direct reset (TRM §12.4.4; the C6 bootloader does not set it), which fits
"running survives 2900 mV, boots fail there" — inferred. Level 7 stays: a
higher level would reset running units on radio peaks; the empty-battery
check is the control.

**The 3500 mV "4 µA floor" is the regulator, not a lower draw.** One capture
stepped 3700 → 3600 → 3500 → 3400 → 3700 mV (`ppk2-20261006T220735`, 59 min,
paired and settled, split with `tools/ppk2-events.py`):

| Supply | Average | Floor | Per poll | Samples at exactly 0 |
|---|---|---|---|---|
| 3700 mV | 108 µA | 40.2 µA | 464 µC | 2 % |
| 3600 mV | 192 µA | 62.9 µA | 789 µC | 31 % |
| 3500 mV | 109 µA | 5.2 µA | (116 "polls" at 260 µC, 16.6/min) | 33 % |
| 3400 mV | 204 µA | 63.4 µA | 547 µC | 34 % |
| 3700 mV again | 136 µA (2 reports in window) | 40.5 µA | 457 µC | 2 % |

At 3500 mV the regulator's bursts grow large and rare enough that the
splitter counts them as wakes; floor plus "polls" is 109 µA, the same as at
3700 mV. Below 3700 mV a third of the samples read exactly zero (the PPK2
cannot read reverse current), which points at the regulator near dropout
interacting with a source that cannot sink — inferred. At 3600 and 3400 mV
the sleep costs ~1.8x more. A real cell spends little of its life there;
the 125 µA figure (3700 mV) stands and today's 3700 mV segments reproduce it
(polls 457–464 µC against 478 µC on 2026-10-05). A Source-Meter capture
below ~3.7 V is not a battery-life measurement.

**Also from this round:** the Matter `BootReason` attribute (0/51/4) was
never created by esp-matter's legacy data model (`esp_matter_cluster.cpp:
502-534`); `app_main.cpp` now creates it and it reads 6 (software reset)
after a dial wake. The first battery report after boot (read during Thread
attach) is now followed by a forced report on the second poll.

**Rules:**

- Check every timed output with the chip actually light-sleeping; a bench
  build that never sleeps (the 2026-08-25 LED check) proves nothing about it.
- A pin that must hold a level through light sleep with peripheral power-down
  needs the pad hold, not only `gpio_sleep_sel_dis()`.
- Decide "empty" before the radio starts, and give it hysteresis.
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

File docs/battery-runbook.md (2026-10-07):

# Battery runbook — protected LiPo on the XIAO ESP32-C6

For the EEMB LP103454 2000 mAh pack (with protection board) feeding a XIAO
ESP32-C6 through its underside BAT pads. Use it when a pack reads 0 V, when a
unit is dead or resetting on battery, or before leaving a unit on a cell.

Each entry says how it is known. **Measured** = read on this bench, with the
date. **Vendor** = a vendor page or schematic. **General** = how protection
boards of this class behave; not confirmed for this pack. The pack's own
thresholds are **unverified**: the EEMB specification could not be retrieved
(2026-09-28), so no trip voltage or current is quoted here.
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

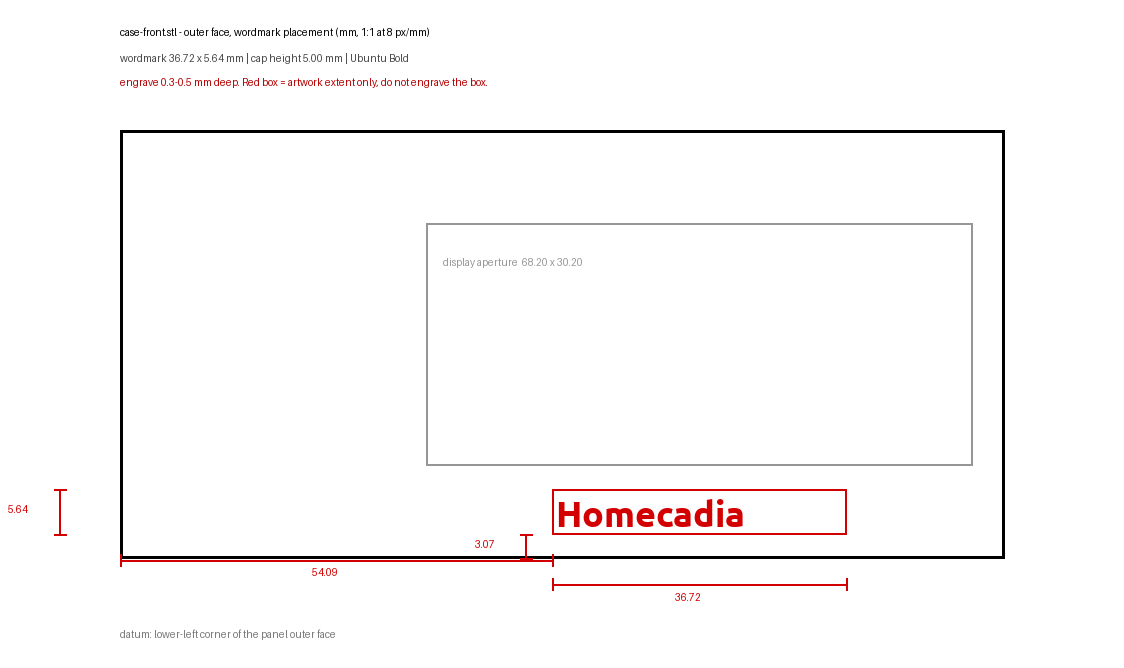
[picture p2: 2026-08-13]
hardware/case/artwork/wordmark-placement.png

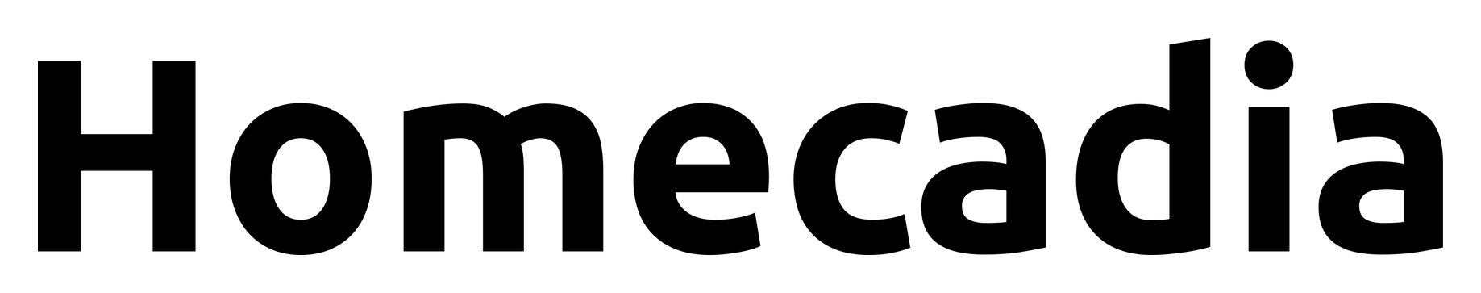
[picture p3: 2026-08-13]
hardware/case/artwork/wordmark-homecadia-1200dpi.png

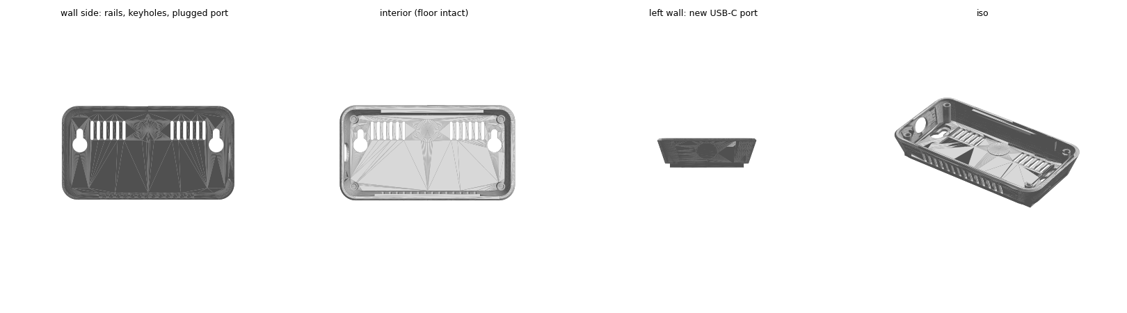
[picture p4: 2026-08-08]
hardware/case/preview.png

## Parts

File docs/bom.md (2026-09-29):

# Bill of materials — sensor-01

Quantities are per unit; build run is 3 units. Prices in CAD; blank = not yet
known, fill as paid. Network-side hardware (ZBT-2 border router, Voice PE) is
in [infrastructure.md](infrastructure.md); hardware checks that gate assembly
are in [bringup.md](bringup.md).

## Ordered and confirmed (reconciled against vendor order pages, 2026-08-13)

| Part | Spec / SKU | Qty per unit | Vendor | Order status | Price paid |
|---|---|---|---|---|---|
| Seeed XIAO ESP32-C6 | MCU, Thread radio, LiPo charge IC on underside pads | 1 | — | **3 in hand, confirmed 2026-08-13**; more bought since. As of 2026-09-28: four consumed (one dead, two with lifted underside pads, one in service as node 26 — [bringup.md](bringup.md)) and **4 unused in hand**. Budget spares: the underside pads do not survive rework | — |
| Seeed ePaper Driver Board for XIAO V2 | SKU 114993558; 24-pin FPC, SPI; battery JST + power switch (JST **not** used — see notes) | 1 | Seeed | **delivered 2026-08-17**, 3/3 | US$5.90 ea / 17.70 |
| Seeed 2.9" mono ePaper 296×128 | SKU 104990853; SSD1680-class; partial refresh + panel deep sleep | 1 | Seeed | **delivered 2026-08-17**, 3/3 — marking `029BN-T94-D2` = Good Display GDEY029T94, SSD1680 controller, **verified 2026-08-22**. ⚠️ 2 of 3 killed during bring-up; reorder | US$9.95 ea / 29.85 |
| Grove SHT40 | SKU 101021032; ±0.2 °C, ±1.8 %RH typ (max ±3.5 %); I2C 0x44; Grove cable cut and soldered | 1 | Seeed | **delivered 2026-08-17**, 3/3 | US$5.50 ea / 16.50 |
| JST 2-pin power connector | SKU 321050009 | 1 | Seeed | **delivered 2026-08-17**, 20/20 | US$0.05 ea / 1.00 |
| EEMB 2000mAh 3.7V LiPo | LP103454; finished size **56 × 34.5 × 10.6mm** — drove the rev 2 case stretch ([hardware/case](../hardware/case/README.md)); JST 2.0mm lead, cut it off; ⚠️ polarity | 1 | Amazon.ca | **delivered 2026-08-12**, qty 3 | 29.29 ea / 87.87 |
| Perfboard | Chanzon 34pcs double-sided FR4, 5 sizes | 1 | Amazon.ca | **delivered 2026-08-18** | 22.79 (kit) |
| Capacitor 100nF | Chanzon 50pcs, 104M disc ceramic, 1000V, through-hole. Voltage rating is overkill but harmless; ±20% is fine for an ADC hold cap | 1 | Amazon.ca | **delivered 2026-08-11** | 29.05 (kit, with resistors) |
| Resistor 1MΩ | ALLECIN 1/4W 1% metal film, 25 values 1Ω–1MΩ — 1MΩ is the top value | 2 | Amazon.ca | **delivered 2026-08-11** | (same order as above) |
| USB-C female panel-mount pigtail | Gebildet 10pcs, 2-pin 24AWG, 3A, waterproof. **M11×2.3 nut, needs a Ø12mm hole — case hole is Ø12.8mm, so it fits** with ~0.8mm slop. Charging via USB **A-to-C only** (no CC resistors) | 1 | Amazon.ca | **delivered 2026-08-13**, 10pcs | 14.99 (10pcs) |
| 3mm LED | Chanzon 60pcs assortment, diffused, 3V 20mA; needs a series resistor from the kit above | 1 | Amazon.ca | **delivered 2026-08-18**; on the bench since 2026-08-25 | 9.11 (kit) |
| M2 self-tapping screw kit | 800pcs stainless, cross-drive pan head | ~4 | Amazon.ca | **delivered 2026-08-12** | 23.44 (kit) |
| Bourns PEC11R-4220F-S0024 | EC11 rotary encoder, 20mm flatted D-shaft, push switch, 24 detents; DK part PEC11R-4220F-S0024-ND | 1 | Digi-Key CA | **delivered 2026-08-12**, qty 3; DDP Timberlea NS | 4.27 ea / 12.81 (+15.00 ship +3.89 HST = **31.70**) |

Seeed line total **US$65.05** (4 lines above, shipping not shown on the order
page). Amazon.ca orders of 2026-08-08, checked against the order pages
2026-09-28: five parts orders at **CAD 99.38** (22.79 + 29.05 + 14.99 + 9.11 +
23.44) plus the three cells at **CAD 87.87**, **CAD 187.25** in all. A sixth
order, 120 Ω resistors, was cancelled by the seller and never charged; the LED
series resistor comes from the ALLECIN kit. The bench order of 2026-09-12 (wire,
flux pens, breadboard) added **CAD 66.44**. The earlier CAD 125–155 estimate
for Seeed was high.

## Still to order

| Part | Spec / SKU | Qty per unit | Vendor | Order status | Price paid (CAD) |
|---|---|---|---|---|---|
| Enclosure set | 4 parts, 30.12 cm³/set. **FDM PLA** — teal front, light grey knob, black/dark grey back. Wordmark **laser-engraved after printing**, not printed ([hardware/case](../hardware/case/README.md)). JLC3DP MJF nylon is the fallback; JLC3DP FDM is ruled out by its 30×30×10mm minimum. **Order ONE test set first** | 1 set | EurekaTec.ca / Azata.ca | quotes requested 2026-08-13; EurekaTec replied — moved ABS→PLA to enable engraving, revised STLs + artwork sent 2026-08-13. Awaiting price, lead time, PLA colour for the back, and whether they stock PETG | |
| #6 pan-head screws + drywall anchors | keyhole wall mounts, **92mm centres** (rev 2), head ≤ Ø8.5×2.4mm | 2 | local | not ordered | |
| Command Small strips | rail landings on case back | 2 | local | not ordered | |
| **Female header sockets, 2.54mm** | **2×7 per unit (42 positions for 3 units)** — the ePaper driver board ships with **bare through-holes**; the XIAO cannot seat on it until these are soldered in ([assembly.md](assembly.md)). Buy 40-pin strips and cut | 14 pos | local / Amazon.ca | **fitted** on the driver boards (confirmed 2026-09-28). Note for the case: the fitted sockets are taller than the printed back allows ([hardware/case](../hardware/case/README.md)) | |
| Solder + flux | 63/37 leaded rosin-core 0.6–0.8mm. Flux: no-clean rosin flux pens, 3-pack, unbranded Amazon listing ("No Clean Soldering Pen Rosin"); composition not stated on the listing, so **unverified** beyond "no-clean". Wick/braid in hand | — | Amazon.ca | solder in hand; flux pens **delivered 2026-09-15** (order of 2026-09-12) | |
| Hookup wire, bench | TUOFENG 22 AWG **solid core** tinned copper, PVC, OD 1.60 mm, 6 colours × 30 ft. Right for breadboard rows. **Too stiff for the XIAO underside pads**: a solid 22 AWG lead levers the pad off when it moves ([assembly.md](assembly.md) rule 5) | — | Amazon.ca | **delivered 2026-09-17** (order of 2026-09-12, CAD 66.44 for the whole order, which also holds a BB830 breadboard) | |
| **Pad wire, 30 AWG** | silicone stranded or Kynar wire-wrap, for the four underside pad leads only | ~0.5 m | local / Amazon.ca | **not ordered** | |
| Heat shrink | assorted; fallback if the perfboard divider carrier doesn't work out | — | local / Amazon.ca | not ordered | |

The LEDs and resistors were bought from Amazon.ca rather than Digi-Key, so the
encoder is the sole Digi-Key line and carries the whole $15 freight + HST.

**Every electronic part in this build is in hand** except the 30 AWG pad wire
and the enclosure, which is being redesigned. The female headers, a hard
blocker when found missing on 2026-08-17, are fitted.

## ⚠️ Assembly warnings (repeated in [assembly.md](assembly.md))

- **EEMB LiPo polarity is frequently reversed** vs the Seeed/Adafruit
  convention. Multimeter-check every cell before connecting anything.
  Reversed polarity kills the XIAO. (Pack #1 in this batch was standard:
  red = +, measured 3.87 V on 2026-09-03.)
- **A pack reading 0 V is usually not dead.** The JST-PH crimp contacts sit
  below the housing rim — a probe on the connector reads nothing in both
  polarities. And the pack's protection board latches on over-discharge:
  terminals read 0 V while it still accepts charge, and it stays at 0 V for
  hours after charging starts. Pack #1 did this twice (2026-09-05 and
  2026-09-09) after the sleep-disabled bench profile drained it at ~41 mA;
  it recovered to 3.97 V both times. Cross-project rule in the homelab
  `battery-bringup` skill. **Disconnect the cell at the end of every bench
  session until the shipping profile is flashed.**
- Battery solders to the **XIAO's underside battery pads** (its charge IC),
  NOT the ePaper driver board's JST — that path does not charge.
- **SHT40 sits in the case airflow path, external to MCU heat** —
  self-heating skews readings.

## Notes

- **Battery JST on the ePaper driver board is unused.** The battery solders to
  the XIAO's underside battery pads so the XIAO's charge IC manages it. The
  Seeed wiki claims the V2 driver board has its own charging IC, but veltoc's
  build (same board) found the JST path does not charge in this stack. Battery
  goes to the XIAO pads; the driver board's power switch is therefore also
  bypassed.
- **100k vs 1M divider:** a 100k+100k divider across a 4.2V battery bleeds
  ~21µA continuously — about 9% of the ≤300µA average power budget. 1M+1M
  bleeds ~2.1µA. The tradeoff is a high-impedance ADC source, handled with the
  100nF hold cap and a settling delay in firmware. See
  [power-budget.md](power-budget.md); divider lands on GPIO4/MTMS, not A0
  ([pinmap.md](pinmap.md)).

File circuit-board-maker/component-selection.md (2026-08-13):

# Component selection — board-mount equivalents

Companion to [pcb-evaluation.md](pcb-evaluation.md). That document decides
*whether* to build a board. This one decides *which parts* go on it, if one gets
built.

Stock and pricing pulled from LCSC via the jlcsearch community API on
2026-08-13. Prices are USD at the low-quantity break. Stock figures move; treat
them as "was plentiful / was thin", not as commitments.

**HS** = hand-solderable at through-hole/JST/perfboard skill level.
**M** = machine assembly only.

---

## Board-mounting is a downgrade for three of these parts

Going board-mount is not uniformly an improvement:

| | Part | Verdict |
|---|---|---|
| ✅ | Divider resistors, hold cap | Clear win — flying components get a footprint |
| ✅ | Battery connector | Clear win — strain goes into the board |
| ✅ | Charger, LDO, fuel gauge | Clear win — they don't exist as discrete parts today |
| ➖ | EC11 encoder | **Already correct.** Nothing to change |
| ⚠️ | 3mm LED | Ambiguous — board-mounting forces case alignment |
| ⚠️ | USB-C | Costs a case revision |
| ❌ | SHT40 | **Actively worse** on the main board |

### The EC11 is already a PCB-mount part

Bourns PEC11R-4220F-S0024 has through-hole PC pins and two mounting posts,
designed to solder to a board and take shaft force through the posts. It is the
one part in [docs/bom.md](../docs/bom.md) that was already selected correctly
for a board. No change.

### The LED gets worse

On flying leads it goes wherever the case has a hole. On a board it is fixed in
X/Y, and the case aperture must match board placement within roughly a
millimetre — or a light pipe gets added. For a single status LED, flying leads
to a panel-mounted 3 mm part is the more forgiving design. **Keep it as-is.**

### The SHT40 must not go on the main board

[docs/bom.md](../docs/bom.md) already records why: *"SHT40 sits in the case
airflow path, external to MCU heat — self-heating skews readings."*

The board-mount version of this part is a **satellite board** — a ~10 × 10 mm
PCB carrying the sensor and its decoupling cap, on a 4-wire cable to a JST-SH on
the main board. That is board-mounting done right. Placing it beside the LDO and
a booster inductor is board-mounting done wrong.

---

## The display: the board-mount answer is "don't"

The instinct is to put the FPC connector and the SSD1680 booster on the board.
The parts exist and are cheap:

| Function | LCSC | Part | Package | Stock | Unit |
|---|---|---|---|---|---|
| 24-pin FPC | [C2856805](https://www.lcsc.com/product-detail/C2856805.html) | FPC-05F-24PH20 | 0.5 mm horiz. | 93,037 | $0.110 |
| 24-pin FPC (Hirose) | [C324726](https://www.lcsc.com/product-detail/C324726.html) | FH34SRJ-24S-0.5SH(50) | 0.5 mm horiz. | 53,948 | $0.276 |
| Inductor 47 µH | [C167766](https://www.lcsc.com/product-detail/C167766.html) | FNR3015S470MT | 3×3 mm | 46,881 | $0.042 |
| Schottky ×3 | [C82046](https://www.lcsc.com/product-detail/C82046.html) | MBR0530T1G | SOD-123 | 78,840 | $0.063 |
| NMOS | [C179399](https://www.lcsc.com/product-detail/C179399.html) | NX3008NBK,215 | SOT-23 | 61,392 | $0.053 |

That NX3008NBK is **the exact part Solomon Systech names** in Table 13-1 of the
[SSD1680 datasheet](https://www.crystalfontz.com/controllers/uploaded/SSD1680.pdf),
and it is in stock at five cents. The whole booster BOM is under a dollar.

**Build it anyway and you have taken on the hardest part of this project to save
about six dollars.** It means laying out a ±20 V switching node beside a Thread
radio, on a first PCB, with two footprint traps:

1. **Top-contact vs bottom-contact FPC.** All the connectors above are
   "horizontal mount," which says nothing about which face the contacts are on.
   Order the wrong one and the panel flex will not mate, and there is no rework
   path on a 0.5 mm ZIF. **Unresolvable until the Seeed panel is physically in
   hand** — measure it when it lands.
2. **The 25 V capacitors.** C2–C7 are 1 µF at **25 V**, and C8 must hold
   *effective* capacitance >0.25 µF at 18 V DC bias. Solomon Systech spells that
   out because Class II ceramics lose most of their capacitance under bias.
   Substitute a 1 µF 6.3 V 0402 because the value matched, and the booster
   quietly underperforms.

**Better move: keep the Seeed driver board and mount *it*.** It already carries
the booster, the FPC, and an ETA9740 charger, and Seeed's product description
lists an **"IO Break out"** header alongside the XIAO socket. Give the harness
board a mating header footprint and the display becomes a module. Cost: a few
millimetres of stack height in an 18.6 mm cavity. Benefit: never touch ±20 V or
0.5 mm pitch.

> **Open question:** the exact pinout of the driver board's IO breakout header is
> not documented in anything found so far. Probe it when the board arrives; the
> harness board design in [hb-01/](hb-01/) treats it as a labelled 2.54 mm field
> rather than a precise mating connector because of this.

---

## Hand-solderable parts

| Job | LCSC | Part | Package | Stock | Unit | |
|---|---|---|---|---|---|---|
| Charger | [C424093](https://www.lcsc.com/product-detail/C424093.html) | MCP73831T-2ACI/OT | SOT-23-5 | 2,727 | $0.87 | HS |
| **LDO 3.3 V, 25 nA Iq** | [C5142805](https://www.lcsc.com/product-detail/C5142805.html) | **TPS7A0233DBVR** | **SOT-23-5** | **433** | $0.76 | HS |
| USB-C, full data | [C2765186](https://www.lcsc.com/product-detail/C2765186.html) | TYPE-C 16PIN 2MD(073) | SMD | 1,171,811 | $0.074 | HS |
| ESD array | [C3040626](https://www.lcsc.com/product-detail/C3040626.html) | SP0503BAHTG | SOT-143 | 59,167 | $0.096 | HS |
| Battery connector | [C131337](https://www.lcsc.com/product-detail/C131337.html) | B2B-PH-K-S(LF)(SN) | TH, 2 mm | 298,406 | $0.035 | HS |
| Encoder | — | PEC11R-4220F-S0024 (owned) | TH | — | — | HS |

### The TPS7A0233 in SOT-23-5 is the find here

The 25 nA Iq part exists in a package solderable with an iron
([TI datasheet](https://www.ti.com/lit/ds/symlink/tps7a02.pdf)). Two caveats:

- **Stock is only 433**, versus 1,409 for the machine-only X2-SON-4 variant
  ([C2860046](https://www.lcsc.com/product-detail/C2860046.html), $0.54). Buy
  spares now if this is wanted.
- **Re-check the 200 mA rating** against 802.15.4 TX peak plus e-ink refresh
  drawn concurrently. That is the one spec that could bite.

### Use the 16-pin USB-C, not the 6-pin

LCSC has [C456012](https://www.lcsc.com/product-detail/C456012.html) "TYPE-C 6P"
at 527,859 stock and $0.039, and it is much easier to hand-solder. **Don't.**
Power-only means no D+/D−, which costs native USB — and
[docs/build.md](../docs/build.md) flashes over exactly that, with the console on
USB Serial/JTAG. Six-pin USB-C means flashing over the underside pads for the
life of the device.

### Board-mount USB-C costs a case revision

The Ø12.8 mm round side-wall hole exists because the pigtail is panel-mount. A
board connector needs a rectangular cutout aligned to board position, and the
board's X/Y placement becomes mechanically load-bearing — every insertion puts
force into the board and its mounts rather than into the case wall. The
panel-mount pigtail's strain relief is a real advantage being given up.

**But the pigtail cannot be fixed in place.** On a 2-wire panel-mount USB-C
part, CC1 and CC2 terminate inside the moulded housing and are not brought out
on the two wires, so there is nothing external to attach a 5.1 kΩ resistor to.
Fixing C-to-C means either swapping the pigtail for one that has the resistors
built in, or putting the receptacle on this board and accepting the case
revision. See the correction in
[pcb-evaluation.md](pcb-evaluation.md#on-pain-point-3--the-fix-is-a-connector-swap-not-two-resistors).

**Measure before buying.** Some 2-wire pigtails do include internal 5.1 kΩ
resistors. Probe CC1→GND and CC2→GND on the connector face; 5.1 kΩ on both means
there is no problem to solve.

Note that on the Option 0 board the receptacle can only carry **power**. The
XIAO does not expose D+/D− on its header, so USB data still comes from the
XIAO's own connector — VBUS from this board feeds the XIAO's 5V pin and its
onboard charger. Flashing and console remain on the XIAO's connector either way.

---

## Machine-assembly-only parts

| Job | LCSC | Part | Package | Stock | Unit | |
|---|---|---|---|---|---|---|
| MCU module | [C5736265](https://www.lcsc.com/product-detail/C5736265.html) | ESP32-C6-MINI-1-N4 | SMD-53P | 3,344 | $4.22 | M |
| Fuel gauge | [C2682616](https://www.lcsc.com/product-detail/C2682616.html) | MAX17048G+T10 | DFN-8-EP 2×2 | 4,403 | $2.32 | M |
| Temp/humidity | [C2909890](https://www.lcsc.com/product-detail/C2909890.html) | SHT40-AD1B-R2 | DFN-4-EP 1.5×1.5 | 20,692 | $2.03 | M |

Also stocked: [C2848306](https://www.lcsc.com/product-detail/C2848306.html)
SHT40-AD1B-R3 (16,103, $1.84 — cheaper tape variant of the same die) and
[C20627095](https://www.lcsc.com/product-detail/C20627095.html)
ESP32-C6-MINI-1U-H4 (787, $4.55 — the 13.2 × 12.5 mm no-antenna U.FL variant).

**There is no hand-solderable fuel gauge.** MAX17048 is DFN-8 2×2 mm; the WLP-8
alternative ([C7497002](https://www.lcsc.com/product-detail/C7497002.html)) is
0.9 × 1.8 mm with 18 in stock. Fixing pain point 2 means committing to machine
assembly. Given that a fuel gauge saves 3 µA of nothing and improves a
percentage reported hourly, this is the weakest item on the pain-point list to
cross that line for.

---

## Passives — one caveat that is new

1 MΩ 1% and 100 nF X7R in 0805 are trivially available and hand-solderable.

**At 1 MΩ, board surface leakage stops being negligible.** Unwashed flux residue
across the divider node can shift the ADC reading measurably. Clean thoroughly
under that node, or accept a calibration offset. This is a *new* failure mode —
it does not exist on the current flying-component divider because there is no
board surface to leak across.

---

## What this does not change

**A keyed JST does not solve the polarity hazard.** [docs/bom.md](../docs/bom.md)
warns that EEMB cells are *"frequently reversed vs the Seeed/Adafruit
convention"* — that is the cell's crimp, not the connector. A polarized board
connector will happily accept a backwards-wired cell and route it to the
charger. **Keep the multimeter check in [docs/assembly.md](../docs/assembly.md).**
Board-mounting arguably makes this *worse*, by removing the moment where bare
wires are in hand and polarity is already on the mind.

**None of this moves the power budget.** Summing the hand-solderable set:
MCP73831 <2 µA (UVLO), TPS7A0233 0.025 µA, divider 2.1 µA — roughly 4 µA against
a 300 µA budget. The conclusion in [pcb-evaluation.md](pcb-evaluation.md) stands:
measure the assembled unit before component selection is allowed to argue from
power.

**Sourcing:** these are LCSC prices, and for a 3-unit build they are irrelevant
next to freight. [docs/bom.md](../docs/bom.md) already shows the encoder carrying
CAD 15.00 shipping + 3.89 HST on a CAD 12.81 order. Consolidate into one LCSC
order or don't bother — the parts here total under USD 10 for three units.

---

## Unverified — check before ordering

- **Saturation current on the 47 µH inductors.** Table 13-1 needs Io = 500 mA
  max. Only inductance and package were confirmed; Isat and Irms were not.
- **FPC contact side** (top vs bottom). Needs the physical panel in hand.
- **MCP73831 suffix decoding.** Confirm the chosen suffix gives 4.20 V
  regulation and the status-output style wanted.
- **Live stock.** All figures are a 2026-08-13 snapshot.

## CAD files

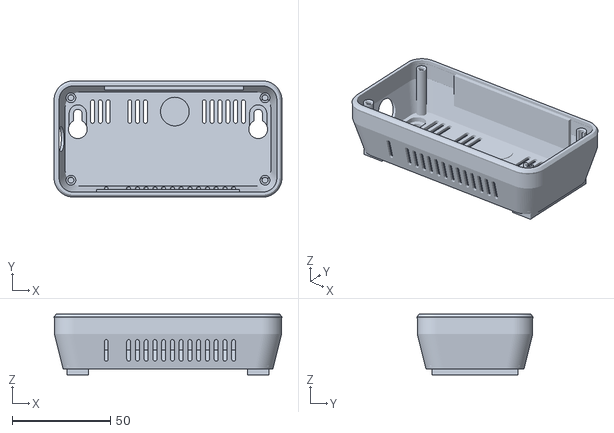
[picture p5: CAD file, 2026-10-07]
hardware/case/stl/case-back-wallmount.stl
116.3 x 59.3 x 31.0

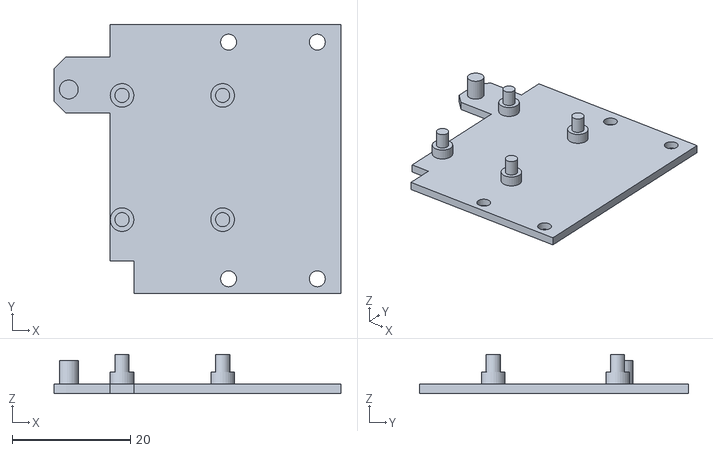
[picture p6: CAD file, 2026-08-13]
hardware/case/stl/insert-tray.stl
48.5 x 45.5 x 6.60

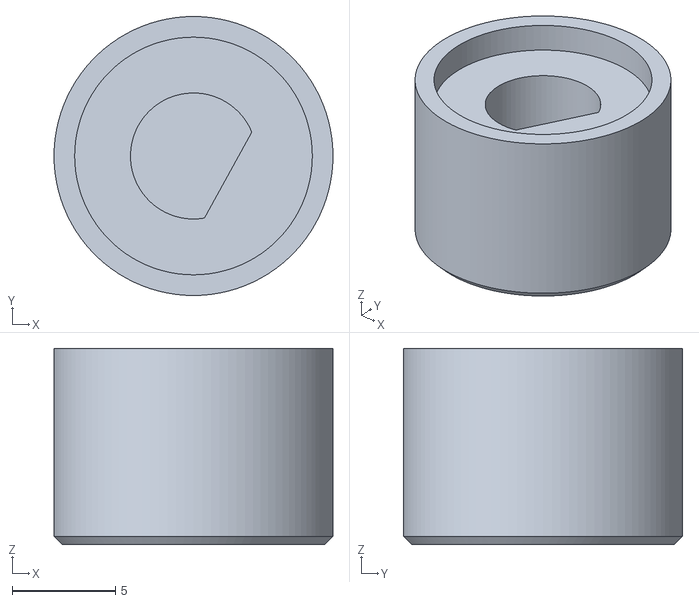
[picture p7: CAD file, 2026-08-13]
hardware/case/stl/encoder-knob.stl
13.5 x 13.5 x 9.50

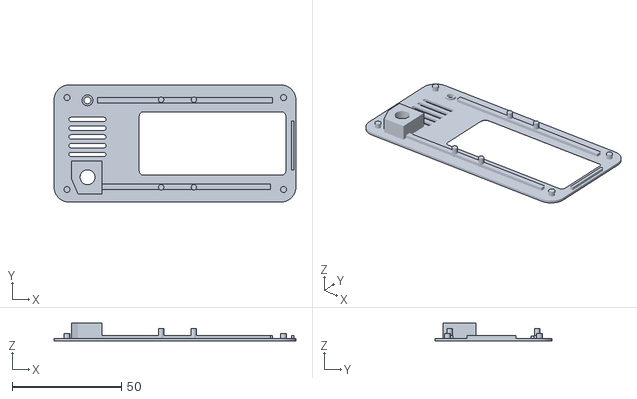
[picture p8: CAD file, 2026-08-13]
hardware/case/stl/case-front.stl
110.6 x 53.6 x 8.20

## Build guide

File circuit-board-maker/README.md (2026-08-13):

# circuit-board-maker

Investigation into replacing the hand-wired sensor-01 build with a custom PCB,
and the board designs that came out of it.

> **Status: paper design, validated against KiCad 10.0.5 but never fabricated.**
> See [Validation](#validation) for exactly what was checked and what was not.

## Conclusion

**Don't build a full custom PCB for three units.** Build `hb-01`, hand-wire the
three units, and measure the assembled device before letting any power argument
justify a board spin. Full reasoning in [pcb-evaluation.md](pcb-evaluation.md).

## Conflicts with the shipped build — read before reviving hb-01

Audited 2026-08-13 against the main docs. None of these are fatal to the
evaluation's conclusion, but every one must be resolved before `hb-01` is
ordered.

1. **Two nets land on pins the XIAO header does not have.** `hb-01/NETLIST.md:54`
   routes `VDIV` to J2.13 and `:44` routes `ENC_SW` to J2.14 on a 14-pin "XIAO
   field". Per [../docs/pinmap.md](../docs/pinmap.md), the battery divider is on
   **GPIO5/MTDI** and the encoder push on **GPIO6/MTCK** — both **underside
   pads**, not header pins. Either those two positions are meant as
   flying-wire landings (undocumented), or the design assumes access that does
   not exist. Until it is resolved, `pcb-evaluation.md:179` ("Zero firmware
   changes") is unproven.
2. **Board-mount USB-C contradicts the case and the bought part.**
   `hb-01/NETLIST.md:10` places a receptacle needing a rectangular cutout;
   case rev 4 has a **Ø12.8mm round hole** and the Gebildet 2-wire pigtail that
   fits it is **already delivered** ([../docs/bom.md](../docs/bom.md)). No case
   revision exists for this. `component-selection.md:133` concedes the point.
3. **It does not fit the cavity as designed.** The 48 × 40mm board has to live
   in a 106.64 × 47.9mm cavity that already holds a 48.5mm tray plus a 56mm
   cell — **2.1mm of slack**
   ([../hardware/case/README.md](../hardware/case/README.md)). Its four M2 holes
   on a 41 × 33mm pattern also cannot mount on the tray's four Ø2.4mm pegs on a
   17.0 × 21.0mm pattern, and the case has no other board mounts. Stack height
   inside 18.6mm is unbudgeted. `README.md` already admits the board "was never
   checked against the STLs".
4. **Board-mounting the LED and encoder fights the front panel.** `case-front.stl`
   carries the EC11 mount and the 3mm LED hole; `hb-01/NETLIST.md:18-19` puts
   both on the board at fixed coordinates, making board position mechanically
   load-bearing against a panel it was never fitted to.
   `component-selection.md:42` independently recommends keeping the LED on
   flying leads.
5. **sb-01 replaces a part already in hand.** The Grove SHT40 (SKU 101021032)
   shipped 3/3; `sb-01` substitutes a bare DFN-4 SHT40-AD1B needing reflow.
6. **Internal staleness.** Both netlists still say "Never opened in KiCad"
   (`hb-01/NETLIST.md:4`, `sb-01/NETLIST.md:4`), contradicting the validated
   status above. Satellite size is quoted as ~10 × 10mm in
   `pcb-evaluation.md:56` and `component-selection.md:49` but built at 14 × 16mm.

## Documents

| Doc | Contents |
|---|---|
| [pcb-evaluation.md](pcb-evaluation.md) | Three options costed, quiescent-current budgets, antenna clearance, firmware change surface, and why a PCB doesn't earn its cost at qty 3 |
| [component-selection.md](component-selection.md) | Board-mount part equivalents with live LCSC stock, and the three parts where board-mounting is a downgrade |

## Boards

| Board | Size | Purpose | Assembly | DRC |
|---|---|---|---|---|
| [hb-01/](hb-01/) | 48 × 40 mm | Harness board — divider, USB-C + CC resistors, ESD, encoder, LED, JSTs, 6 test points | **Hand-solderable** | 65 errors, all inside J1 — see below |
| [sb-01/](sb-01/) | 14 × 16 mm | SHT40 satellite, keeps the sensor out of MCU heat | Needs reflow or hot air | **0 errors** |

### hb-01

hb-01 plan view

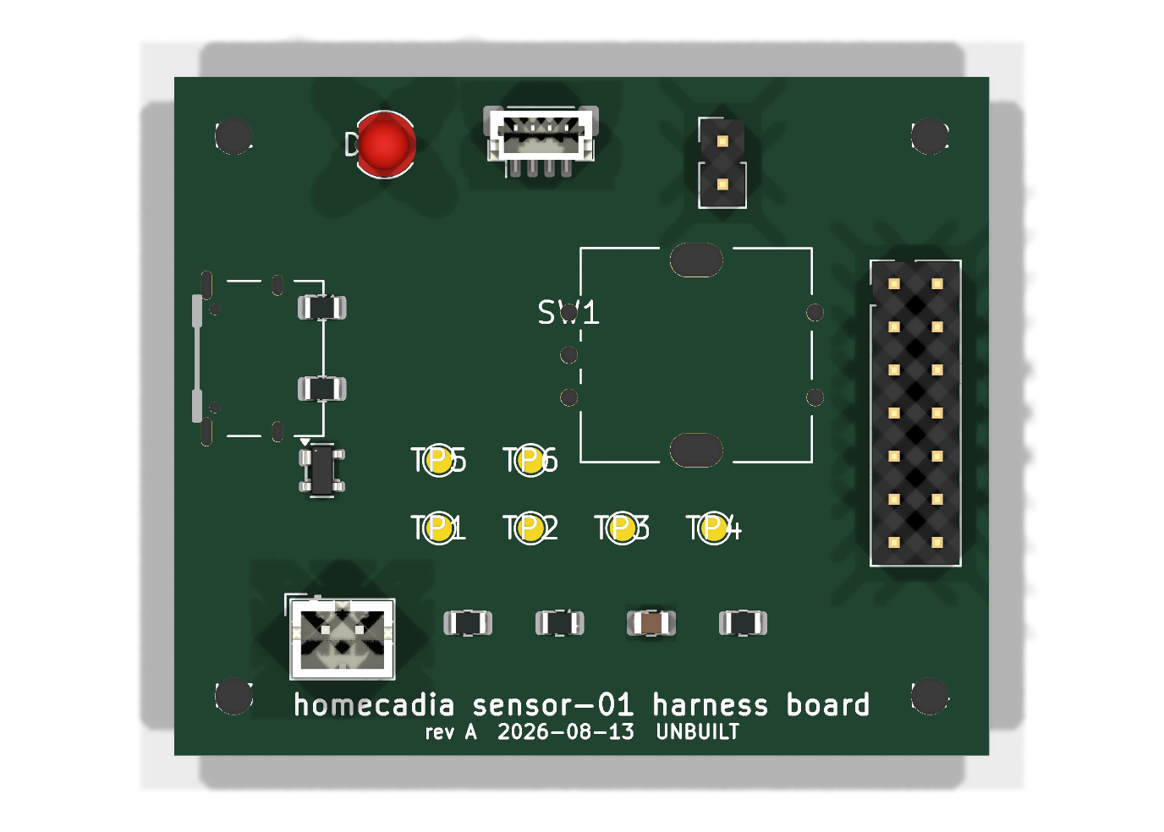
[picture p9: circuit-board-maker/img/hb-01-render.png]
hb-01 render


### sb-01

sb-01 plan view

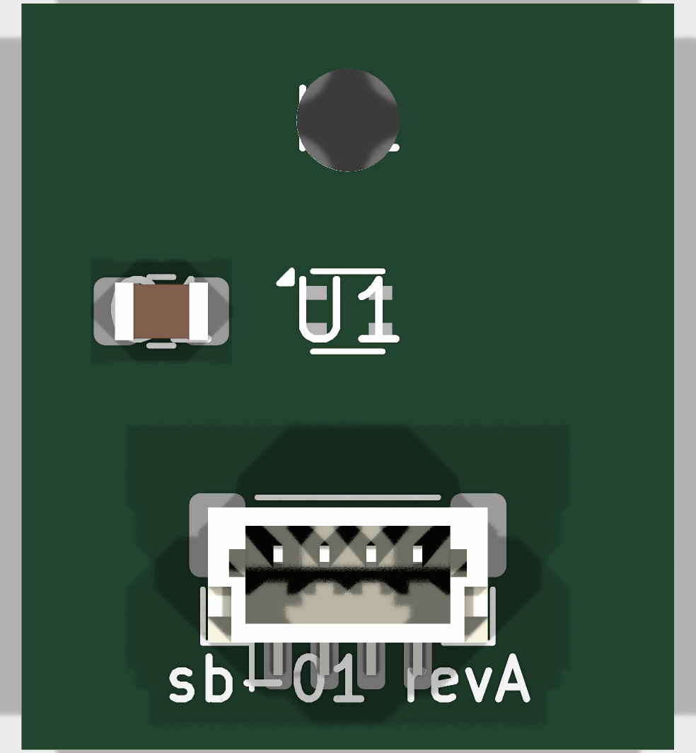
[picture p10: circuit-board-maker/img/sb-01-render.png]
sb-01 render


### How they connect

Option 0 interconnect

## Files per board

```
hb-01/
  hb-01.kicad_pro    project settings, net classes
  hb-01.kicad_pcb    board outline, mounting holes, silkscreen, 24 placed footprints with nets
  hb-01.net          KiCad netlist
  NETLIST.md         authoritative connection list + BOM with LCSC codes
```

There is no `.kicad_sch`. The netlist is the design; a schematic is a drawing of
it, and KiCad can generate one from the board. Open the `.kicad_pro`, and the
footprints are already placed with nets assigned — start by routing.

## Validation

Run against **KiCad 10.0.5** (Windows install, driven from WSL via
`kicad-cli.exe`). What that actually established:

**Verified:**

- **All 13 footprint library references resolve** against KiCad 10's installed
  libraries. One was wrong on the first pass and is fixed —
  `Sensirion_DFN-4-1EP_1.5x1.5mm_P0.8mm_EP0.7x0.9mm` does not exist; the real
  name is `Sensirion_DFN-4_1.5x1.5mm_P0.8mm_SHT4x_NoCentralPad`.
- **`kicad-cli pcb upgrade` accepted both boards** and rewrote them in the
  current format — KiCad parses them.
- **All 26 footprints place with nets assigned**, 0 missing.
- **J1's pads are byte-identical to the library footprint** after the
  generate-and-place round trip (17 pads compared, 0 differences).
- **Both boards render in 3D** — the images above are `kicad-cli pcb render`
  output, not drawings.
- **sb-01 passes DRC with 0 errors.**
- Encoder terminal geometry **checked against the Bourns PEC11R datasheet**:
  5 × Ø1.0 mm holes, 2.5 mm pitch, 5.0 mm spans — matches the footprint.

**Found and fixed during validation:**

- USB-C on hb-01 and the JST-SH on sb-01 both **hung off the board edge**.
- sb-01's C1 and J1 **collided** (courtyard overlap + clearance error).
- sb-01's silkscreen **overflowed a 12 × 16 mm board**; it is now 14 × 16 mm
  with a shorter silk string.
- D+/D− were documented as "broken out to test pads" but **were never actually
  netted**. They now go to TP5/TP6.

**Not resolved:**

- **hb-01 reports 65 DRC errors, every one of them inside J1** (the USB-C
  receptacle) and zero anywhere else. The XKB U262-16XN land pattern has 0.2 mm
  pad gaps, and `kicad-cli` runs with KiCad's default 0.2 mm clearance because
  this hand-written `.kicad_pro` is too minimal for it to load design rules
  from — setting the netclass to 0.05 mm changed nothing. **Open the project in
  the GUI once, set Board Setup → Constraints to 0.127 mm, and save.** That is
  the boundary where these generator scripts should stop and KiCad takes over.
- **Silkscreen sits over pads** on both boards (`silk_over_copper` warnings).
  On sb-01 this hides U1's 0.5 × 0.3 mm pads in the render — they are present
  and netted, just buried under the reference designator.
- **Nothing is routed.** hb-01 has 37 unconnected items, sb-01 has 6.
- **Board dimensions are not fitted to the case.** 48 × 40 mm was chosen to sit
  beside the LP103454 in the 106.64 × 47.9 mm cavity, but was never checked
  against the STLs in [hardware/case](../hardware/case/).
- **The Seeed driver board's IO breakout pinout is undocumented.** `J2` is a
  labelled 2.54 mm field, not a verified mating connector. Probe it when the
  board arrives.
- **The encoder's mounting-boss holes are unverified.** `PEC12R-3x17F-Sxxxx` is
  used because no PEC11R footprint ships with KiCad; its terminals match, but it
  drills 3.1 mm oval bosses and the PEC11R boss dimension could not be read
  reliably from the datasheet drawing. Check before ordering.
- **USB-C on hb-01 carries power only.** The XIAO does not expose D+/D− on its
  header, so flashing and console stay on the XIAO's own connector. TP5/TP6 are
  there for probing, not for a host connection.

## Regenerating

```
python3 gen.py      # netlists, .kicad_pcb outline, .kicad_pro, NETLIST.md
python3 place.py    # loads footprints from the KiCad libs and places them
python3 svg.py      # img/*.svg
```

`place.py` reads the KiCad footprint libraries from
`/mnt/c/Program Files/KiCad/10.0/share/kicad/footprints` — adjust that path
elsewhere. Edit the spec at the top of `gen.py` rather than the generated files.

Once the design moves into KiCad's GUI, **KiCad owns these files** and these
scripts should be retired — re-running them discards routing.

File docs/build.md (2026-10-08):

# Building the firmware

Pinned toolchain: **ESP-IDF v5.5.5 + esp-matter release/v1.6** — the same
combination as the CI image. Don't mix other versions; esp-matter is tightly
coupled to its bundled connectedhomeip submodule and the IDF minor version.

Exact pins (read from inside the pinned image, 2026-10-05):

| Component | Ref |
|---|---|
| esp-matter | `36c2634e99c884830897e2b9501e2d9a6c9d60fd` (head of `release/v1.6` on 2026-08-06) |
| connectedhomeip submodule | `d46cc8c2886cbefc338544bdb2e2f8128f3e9970` |
| ESP-IDF | `v5.5.5` |
| Docker image | `espressif/esp-matter:release-v1.6_idf_v5.5.5` |
| Image digest | `sha256:aabfb665283baf669cd39971763ee1e08788ec876cb4d55c55fa5b125cf8e1d9` (built 2026-08-06) |

Every command here and in CI names the image as `tag@digest`; Docker uses the
digest and ignores the tag, which is kept only so the line is readable.

### Toolchain decision (2026-10-05): stay on this image

**Decision:** stay on esp-matter `release/v1.6` at `36c2634` with ESP-IDF
v5.5.5, pinned by image digest. Do not move to `release/v1.6.1` or to newer
`release/v1.6` commits without a re-measure.

**Why the digest:** Espressif re-pushes its image tags. On 2026-09-17
`release-v1.6_idf_v5.5.5` moved to a new image (`sha256:80664fb6…`) carrying
`release/v1.6` head `c6607128`, 23 commits past the pin. The local image
stayed at `aabfb665`, so from that date CI built against different esp-matter
code from the builds that were flashed and measured. All the measurements in
[power-budget.md](power-budget.md) and field-notes §20–§28 are on `aabfb665`.

**What the alternatives are** (upstream state on 2026-10-05):

| Option | What it brings | Why not now |
|---|---|---|
| `release/v1.6` head (`c6607128`, image `sha256:80664fb6…`) | 23 fixes. The one that touches this build: "Fix SetSlowPollingInterval to enable LIT only if slow polling interval is greater the 15000ms" (2026-08-18). This build runs SIT with the slow poll at exactly 15000 ms, so no change is expected — unverified. The rest are scenes, strings, fan control, bitmaps, a Thread border router fix, and the IDF v6 Docker build | Every change to the ICD path needs a PPK2 capture to confirm the 125 µA; nothing in the 23 is needed |
| `release/v1.6.1` (`717b4bf9`) | 116 commits beyond v1.6: connectedhomeip moved to its v1.6.1 branch, data model regenerated, and "fail loud when setting code-driven cluster attributes" (2026-08-03), which makes the field-notes §9 trap return an error instead of doing nothing silently. It does not fix §9; the workaround stays | Its only image is `release-v1.6.1_idf_v6.0.2`: moving means ESP-IDF 6.0, a major version. Power-management and sleep findings here cite IDF 5.5.5 source by line (`sleep_modes.c`, `ICDManager.cpp`), and the sleep current would have to be re-measured from zero |
| `main` | Development branch | Not a release |

**When to revisit:** when a fix or feature is needed that only a newer
esp-matter has, when ESP-IDF 5.5 drops out of support, or between hardware
revisions. Moving is one change: new digest here and in
`.github/workflows/build-sensor-01.yml`, rebuild, re-read the cited SDK lines,
then a 2 h PPK2 capture on a paired unit analysed with `tools/ppk2-events.py`
against the 125 µA row in power-budget.md.

Assumes Linux. Two paths; Docker is the low-friction one.

## Path A: Docker (matches CI exactly)

```sh
docker pull espressif/esp-matter:release-v1.6_idf_v5.5.5@sha256:aabfb665283baf669cd39971763ee1e08788ec876cb4d55c55fa5b125cf8e1d9

# from the repo root
# (the cd must be inside bash -c: the image's shell init overrides docker's -w
#  and drops you in $ESP_MATTER_PATH, where idf.py would build esp-matter itself.
#  The named ccache volume makes rebuilds after fullclean fast.)
docker run --rm -it -v "$PWD":/work \
  -v homecadia-ccache:/root/.cache/ccache -e IDF_CCACHE_ENABLE=1 \
  espressif/esp-matter:release-v1.6_idf_v5.5.5@sha256:aabfb665283baf669cd39971763ee1e08788ec876cb4d55c55fa5b125cf8e1d9 \
  bash -c 'cd /work/firmware/sensor-01 && idf.py set-target esp32c6 build'
```

Flashing from inside the container needs the serial device passed through:

```sh
docker run --rm -it --device=/dev/ttyACM0 -v "$PWD":/work \
  espressif/esp-matter:release-v1.6_idf_v5.5.5@sha256:aabfb665283baf669cd39971763ee1e08788ec876cb4d55c55fa5b125cf8e1d9 \
  bash -c 'cd /work/firmware/sensor-01 && idf.py -p /dev/ttyACM0 flash monitor'
```

(XIAO ESP32-C6 enumerates as USB CDC, typically `/dev/ttyACM0`. If flashing
won't start, hold BOOT while plugging in.)

### Diagnostic image: light-sleep counters

To see what the chip does while it sleeps, build `build-diag`: the shipping
`sdkconfig` plus `CONFIG_HOMECADIA_SLEEP_DIAG`, which selects the esp_pm
light-sleep callbacks and `CONFIG_ESP_SLEEP_DEBUG`
([field-notes.md](field-notes.md) §21):

```sh
docker run --rm -v "$PWD":/work espressif/esp-matter:release-v1.6_idf_v5.5.5@sha256:aabfb665283baf669cd39971763ee1e08788ec876cb4d55c55fa5b125cf8e1d9 bash -c '
  cd /work/firmware/sensor-01 && mkdir -p build-diag &&
  cp sdkconfig build-diag/sdkconfig &&
  echo CONFIG_HOMECADIA_SLEEP_DIAG=y >> build-diag/sdkconfig &&
  idf.py -B build-diag -DSDKCONFIG=build-diag/sdkconfig reconfigure build'
diff <(grep -E "^CONFIG_|is not set" firmware/sensor-01/sdkconfig) \
     <(grep -E "^CONFIG_|is not set" firmware/sensor-01/build-diag/sdkconfig)
```

The diff must show only the option and what it selects. Use `reconfigure`
after touching `Kconfig.projbuild`: a plain `build` once left a newly
`select`ed option unset.

Run it on the PPK2 with USB out and read the DIAG screen, which the image
redraws every 60 s (the dial cannot open it on battery). Lines, top down:
sleep calls / attempts / % of uptime asleep; requested sleep lengths; actual
sleep lengths and early wakes; wake causes; power-down flags of the last
sleep, those set in every sleep (AND) and in any sleep (OR), bit meanings in
`esp_private/esp_pmu.h` (`PMU_SLEEP_PD_*`: TOP 0, MODEM 2, HP_PERIPH 3, CPU 4,
XTAL 10, RC_FAST 11); share of sleep time with the modem domain and XTAL on;
BLE controller status and the sleep-retention bitmaps.

## Path B: native install

```sh
# ESP-IDF v5.5.5
git clone -b v5.5.5 --recursive --shallow-submodules https://github.com/espressif/esp-idf.git
cd esp-idf && ./install.sh esp32c6 && cd ..

# esp-matter v1.6, at the pinned commit (the branch head has moved past it)
git clone -b release/v1.6 https://github.com/espressif/esp-matter.git
cd esp-matter
git checkout 36c2634e99c884830897e2b9501e2d9a6c9d60fd
git submodule update --init --depth 1
./connectedhomeip/connectedhomeip/scripts/checkout_submodules.py --platform esp32 linux --shallow
./install.sh
cd ..
```

Per shell session:

```sh
source esp-idf/export.sh
source esp-matter/export.sh
```

Then:

```sh
cd firmware/sensor-01
idf.py set-target esp32c6 build
idf.py -p /dev/ttyACM0 flash monitor
```

Expect the first esp-matter build to take a long time (it compiles
connectedhomeip) and the native clone step to download several GB.

## Versioning

`PROJECT_VER` (Matter `SoftwareVersionString`) and `PROJECT_VER_NUMBER` (the
`SoftwareVersion` integer OTA compares) are both derived from the git tag in
`firmware/sensor-01/version.cmake`. Do not set them by hand — they were
hand-set once and drifted to `0.1` / `1` while the repo was tagged `v0.6.0`.

Encoding is `MAJOR*10000 + MINOR*100 + PATCH`, so `v1.2.3` is `10203`.

The firmware is called **aardvark**; the name leads the string, so Home
Assistant's Firmware card shows `aardvark 0.7.0`. The string lives in the
31-character `esp_app_desc_t.version` field, so a dirty tree is marked `*`
rather than `-dirty`.

| Tree state | String | Number |
|---|---|---|
| exactly at `v0.7.0` | `aardvark 0.7.0` | 700 |
| 12 commits past it, dirty | `aardvark 0.7.0-dev.12+4fb2137*` | 700 |
| no tags reachable | `0.0.0-untagged` | 0 |

**The number moves only at tags.** Dev builds keep the tag's number because
they are flashed over USB and never OTA'd, so releasing is `git tag v0.7.0`
and rebuilding — nothing else to remember.

Commits-since-tag is deliberately *not* folded into PATCH. `v0.6.0` plus 63
commits would be 663, and a later real `v0.6.1` would be 601 — lower than what
is already on the device. OTA would then decline the update silently, forever.

Check it after a build, locally or in CI:

```sh
tools/check-version.sh
```

It verifies the tag parses, that the built image actually carries that version
(read from `esp_app_desc_t` at offset 0x30, which catches a stale build
directory), and that the number exceeds the previous tag's.

**CI needs `fetch-depth: 0`.** A shallow checkout has no tags and would build
`0.0.0-untagged` without failing.

## Over-the-air updates

The device side is built in: `CONFIG_ENABLE_OTA_REQUESTOR=y` and
`CONFIG_CHIP_OTA_IMAGE_BUILD=y` (`sdkconfig.defaults`), two 1.9 MB app slots
(`partitions.csv`, 16 % free at 0.6.0). Every build writes
`build/aardvark-ota.bin`, the app with the Matter OTA header,
stamped with vendor 0xFFF1, product 0x8000 and `PROJECT_VER_NUMBER`
(connectedhomeip `config/esp32/components/chip/ota-image.cmake`). CI uploads
it as `aardvark-<version>.ota`. Check a header with
`python3 $ESP_MATTER_PATH/connectedhomeip/connectedhomeip/src/app/ota_image_tool.py show <file>`.

**Home Assistant's firmware card says "Up-to-date" until the Matter server is
told about local images.** It looks up the device in the CSA's public DCL,
where the test vendor 0xFFF1 is not. matterjs-server serves local files only
with both settings ([CLI docs](https://github.com/matter-js/matterjs-server/blob/main/docs/cli.md),
[home-assistant/addons#4520](https://github.com/home-assistant/addons/issues/4520)):

| Setting | Value |
|---|---|
| `ENABLE_TEST_NET_DCL` (`--enable-test-net-dcl`) | `true` |
| `OTA_PROVIDER_DIR` (`--ota-provider-dir`) | a directory holding the `.ota` files |

With only the directory set, the server ignores the files and logs a warning.

**Releasing an update:**

1. Tag: `git tag v0.7.0` (the number moves only at tags; `v0.7.0` is 700
   against 600 for every `0.6.0-dev` build). Build from a clean tree, then
   `tools/check-version.sh`.
2. Copy `aardvark-0.7.0.ota` into the server's `OTA_PROVIDER_DIR` and restart
   the server; it imports the directory once, at startup (homelab
   `kubernetes/apps/default/matter-server/README.md`, "OTA updates for
   homecadia").
3. The device's firmware card offers the update; install from there.

First update, 2026-10-07 ([field-notes.md](field-notes.md) §30): 1.66 MB in
**29.5 min** over Thread to a sleepy end device. The image applied, but **the
restart into it hung on battery** until a power-cycle. Until that is fixed:
update with USB plugged in, and power-cycle a unit that has not rejoined
5 minutes after the transfer completes. Battery cost of a transfer: not yet
measured.

## Flashing from WSL2

USB devices reach WSL through usbipd-win. Field-tested sequence (unit 1):

```sh
# Windows, admin PowerShell, once per board+port:
usbipd bind --busid <BUSID>          # find BUSID with: usbipd list  (XIAO = 303a:1001)

# WSL, per plug-in:
usbipd.exe attach --wsl --busid <BUSID>
# board appears as /dev/ttyACM0; flash via the docker command above with
# --device=/dev/ttyACM0 and `idf.py -p /dev/ttyACM0 flash`
```

**The reliable path is Windows-native esptool**, not usbipd: the C6's
native USB re-enumerates on every reset and usbipd loses it mid-flash about
half the time. Leave the board *Not shared*, take the COM port from
`usbipd.exe list` (it follows the physical port), copy the four images from
`build/` (or `build-bench/`, `build-diag/`) to a Windows folder, and run from
WSL:

```sh
cmd.exe /c "cd /d C:\\path\\to\\images && python.exe -m esptool --chip esp32c6 -p COM11 \
  -b 460800 --before default-reset --after hard-reset write-flash --flash-mode dio \
  --flash-freq 80m --flash-size 4MB 0x0 bootloader.bin 0xc000 partition-table.bin \
  0x1d000 ota_data_initial.bin 0x20000 aardvark.bin"
```

NVS survives, so the device keeps its fabric. On a board powered from the
PPK2, lift the PPK2's VOUT lead before plugging USB in: the two must never
feed BAT+ together.

Gotchas, all hit in practice:

- **A board running firmware without `CONFIG_USJ_NO_AUTO_LS_ON_CONNECTION`
  cannot be flashed normally** — light sleep kills the USB port within ~2s of
  boot (host log: `device descriptor read/8, error -32`) and the
  replug-and-race approach loses to usbipd's attach latency. Recovery: hold
  the **B** button (tiny switch beside the USB-C), plug in while holding,
  release after ~2s — ROM download mode never sleeps. Current firmware pins
  the port awake whenever USB is connected, so this is only needed for
  boards with old/foreign firmware.
- **`usbipd attach` does not survive the device re-enumerating** (e.g. after
  `esptool` exits download mode). `usbipd attach --wsl --busid <BUSID>
  --auto-attach` re-attaches automatically, with ~2–7s latency.
- **Don't script raw reads of `/dev/ttyACM0` for boot logs.** Opening the tty
  pulses the USB-Serial-JTAG control-line latch and can hard-reset the chip —
  sometimes into download mode. Use `idf.py -p /dev/ttyACM0 monitor` in an
  interactive terminal (it owns the reset/reconnect dance); expect the boot
  banner only from its own reset, and expect the port to drop in deep sleep.

## CI

`.github/workflows/build-sensor-01.yml` runs on every push touching
`firmware/**`, in one job using the same Docker image as above. The image pull
dominates the runtime, so extra steps are near-free but a second *job* would
pay that cost again — append steps, do not split.

| Step | Catches |
|---|---|
| Build, shipping profile | ordinary breakage |
| Build, bench profile | code behind `#if CONFIG_PM_ENABLE` that compiles in one profile and not the other; `sdkconfig.bench` also enables the boot-time harness scan (`CONFIG_HOMECADIA_BENCH_SELFTEST`) |
| `tools/check-profiles.sh` | the bench profile silently no longer disabling sleep, and `CONFIG_HOMECADIA_BENCH_SELFTEST` reaching a shipping image — it asserts `# CONFIG_HOMECADIA_BENCH_SELFTEST is not set` in the shipping sdkconfig and `=y` in the bench one, since bench-only diagnostics must not reach a shipping image |
| `tools/check-version.sh` | a `SoftwareVersion` that is stale, untagged, or fails to increase |

## Reading a node over Matter

`tools/matter-node.py` reads a node through the matter-server WebSocket
(`ws://192.168.1.173:5580/ws`, override with `MATTER_WS`) and prints version,
reboot count, temperature, humidity and battery. One shot, 90 s bound.

```sh
tools/matter-node.py get        # server's subscription cache: free for the device
tools/matter-node.py interview  # full read of every attribute on the device
```

`interview` costs the sensor ~150 mC, about ten minutes of its normal running
(field-notes §22); use it once to prove liveness after a reflash, not as a
poll. For calibration or soak work, listen for `attribute_updated` events
instead: every 120 s report arrives with no extra radio traffic.

Flash images (app, bootloader, partition table, `flasher_args.json`) are
uploaded as an artifact.

Both check scripts run locally too, and both fail on a missing or malformed
input rather than passing vacuously — a guard that quietly does nothing is
worse than no guard, because it manufactures confidence
([field-notes.md](field-notes.md) §12).

### What is deliberately not tested

No unit tests. Nearly everything here is I/O — SPI to the panel, I2C to the
sensor, the Matter stack, the ADC — and the small amount of pure logic (the
EC11 Gray-code table, the settings clamp) has not been where the bugs were.
The defects that actually cost days on this project were a reversed FPC, a
`busy_wait()` that could not tell a working panel from a silent one, a stale
container tag, `attribute::update()` writing to a store nothing reads, and BLE
memory being reclaimed after commissioning. No unit test finds any of those.

Hardware-in-the-loop is the right answer eventually and the wrong one now:
there is one working panel and one bench board.

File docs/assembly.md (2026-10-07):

# Assembly — sensor-01

The repeatable build procedure. It is written from four XIAOs: #1 died to a
source-meter injection, #2 and #3 lost underside pads, #4 is in service as
node 26 (2026-09-28). Every gate below exists because skipping it cost a board
or a day. Wiring targets are defined in [pinmap.md](pinmap.md); photos come in
milestone 6.

**Soldering is where every fault in this build was introduced, and none of
them was visible.** The procedure is therefore: solder the smallest possible
set of joints, prove each one by measurement while it is still reworkable,
then fix it in place and never touch it again.

## Rules

1. **Check the meter before the board.** Touch the probes together on beep,
   then read a known voltage (the XIAO's 5V pin on USB reads ~5 V). A probe
   lead loose in its jack reads 0 V and "no beep" on everything; it produced a
   full session of wrong conclusions about good wiring
   ([field-notes.md](field-notes.md) §25).
2. **Four underside joints, no more:** BAT+, BAT−, MTMS, MTCK. Everything else
   goes on header pins.
3. **The silkscreen labels sit beside the pads, and 3V3 is next to MTCK.**
   Which pad a wire is on is decided by the tests, not by looking.
4. **Test before glue.** Hot glue is the strain relief the pads need, and it is
   one-way: taking it off to rework XIAO #3 took the pads with it.
5. **A wire is a lever.** Use 30 AWG silicone or wire-wrap wire on the pads.
   Stiff hookup wire tore pads on two boards with no heat involved.
6. **Electronics flux only** (no-clean pen, e.g. Kester 951). Plumbing flux
   conducts ([field-notes.md](field-notes.md) §17).
7. **USB and a battery source never feed BAT+ together.** Lift the PPK2 VOUT
   lead or unplug the cell before USB goes in.
8. **One change, then one measurement.**

## ⚠️ Battery polarity — read before touching the battery

**Check polarity with a multimeter before connecting anything.** The EEMB
LiPo's connector may be wired **reversed** relative to the Seeed convention.
Reversed polarity destroys the XIAO's charge circuit instantly.

1. Multimeter on DC volts, red probe to the battery lead you believe is +.
2. Expect **+3.5 to +4.2V**. A negative reading means the leads are swapped —
   re-pin the connector or swap the wires at the solder joint.
3. The battery solders to the **XIAO's underside battery pads** (marked BAT+ /
   BAT−), not to the ePaper driver board's JST. The JST path does not charge
   in this stack (veltoc, confirmed in their build; the wiki's charging-IC
   claim did not hold).
4. A protected cell that reads 0 V is usually latched, not dead: probe the
   metal contact (not the housing) and test by whether it accepts charge.
   Causes and the test order are in [battery-runbook.md](battery-runbook.md).

## Wiring, as built on node 26

| Signal | XIAO connection | GPIO | Joint |
|---|---|---|---|
| Battery + | BAT+ pad | — | underside |
| Battery − | BAT− pad | — | underside |
| Battery divider node | MTMS pad | 4 | underside |
| Encoder A | MTCK pad | 6 | underside |
| Encoder B | D6 | 16 | header |
| Encoder common (middle leg) | GND | — | header |
| Push switch | D9 and GND | 20 | header |
| LED + 330 Ω | D7 | 17 | header |
| SHT40 SDA / SCL | D4 / D5 | 22 / 23 | header |
| ePaper RST, CS, BUSY, DC, SCK, MOSI | D0, D1, D2, D3, D8, D10 | 0, 1, 2, 21, 19, 18 | driver board |

Battery divider: 1 MΩ from BAT+ to the node, 1 MΩ from the node to GND, 100 nF
from the node to GND, MTMS wire to the node
([diagrams/battery-divider.html](diagrams/battery-divider.html)). Not A0: A0 is
the ePaper reset line. Encoder A is on MTCK because only LP GPIOs 0–7 can wake
light sleep and the header's three (D0–D2) belong to the display. The push
switch cannot wake the chip: turn first, then press within 2 s.

## Stage 0 — bare XIAO (5 min, no soldering)

Proves the board before anything is attached, so a later fault cannot be the
XIAO as delivered.

1. Plug the bare XIAO into USB. Windows must list a port with
   `VID:PID=303A:1001`.
2. Flash the bench image (all four segments, offsets in
   [build.md](build.md)).
3. Unplug and replug USB (a serial-line reset leaves the console silent), then
   capture 30 s. **Pass:** the harness prints
   `coupling scan: no pin follows any other` and all six outputs
   `follows the driver`.

## Stage 1 — solder the four underside wires

- Leaded solder 300–320 °C, lead-free 340–350 °C (general guidance, not
  measured on this board). Pads lift from time on the pad and from pull on the
  wire more than from temperature.
- Pre-tin the wire. Tin the pad with one touch. Join with a touch of about 1 s.
- Trim stray strands at the BAT+ and BAT− joints; on XIAO #4 strands fanned
  toward the neighbouring pad.
- Lay the board flat and do not move the wires until Stage 2 is done.

## Stage 2 — unpowered tests (5 min, before glue)

USB out, no battery, meter on beep, board flat. Rule 1 first. "Wire" means the
free end of the wire, so the joint is inside the measurement.

| # | Probe A | Probe B | Pass | A fail means |
|---|---|---|---|---|
| 1 | MTCK wire | 3V3, 5V, GND header pins in turn | no beep ×3 | wire is on a power or ground pad |
| 2 | MTMS wire | 3V3, 5V, GND header pins in turn | no beep ×3 | same |
| 3 | BAT+ wire | BAT− wire | no beep | strand or solder bridge across the battery |
| 4 | BAT− wire | GND header pin | beep | BAT− joint open |
| 5 | MTCK wire | GND pin, **B button held**, then **R button held** | no beep ×2 | wire is on BOOT or EN |
| 6 | MTMS wire | GND pin, B held, then R held | no beep ×2 | same |
| 7 | MTCK wire | MTMS wire | no beep | bridge between the two signal pads |

Tests 1–4 exclude the pads that cause damage. Tests 5–6 exclude the two pads
that cannot be fixed in firmware: the XIAO's buttons short BOOT and EN to
ground, which makes those pads identifiable without power. After all seven,
the only mistakes left are mix-ups among MTMS, MTDI, MTCK and MTDO, and those
are a pin number in `app_config.h`.

**All pass: glue.** Hot glue over the four joints and again over the wires a
centimetre away, so a pull lands on glue. Any fail: rework now, while it costs
one joint and not a pad.

## Stage 3 — powered tests on USB, bench image (10 min)

Attach the header-side parts (encoder B and common, push switch, LED, SHT40,
display) and join the encoder A lead to the MTCK wire. No battery.

| # | Action | Pass, from the console | Proves |
|---|---|---|---|
| 1 | boot, wait 10 s | `sensor_loop: reported … bat NN% (~4000–4100mV)` | MTMS wire is on GPIO4 and BAT+ is wired: with no cell the divider reads the charger output |
| 2 | same boot | `harness: … device at 0x44`, six outputs `follows the driver` | sensor and display wiring |
| 3 | turn 3 detents clockwise, 3 back | three `on_rotate dir=1`, three `dir=-1`, `encoder raw` lines changing on both A and B | MTCK wire is on GPIO6; encoder B and common |
| 4 | press 3 times | `on_push` per press | switch wiring |
| 5 | through 3 and 4 | the COM port stays present | no contact shorts a rail |

Start the capture before acting and read it after. A port that vanishes when
the knob turns is a rail being shorted through the encoder: stop and return to
Stage 2.

## Stage 4 — battery-side tests, shipping image (15 min)

1. Flash the shipping image. Unplug USB.
2. PPK2 in Source Meter mode at 3700 mV, VOUT to BAT+, GND to GND, then enable
   output.
3. **Unpaired, expect about 28 mA average** with a 20–40 mA baseline while the
   15-minute commissioning window is open (measured 2026-09-28), then
   **~20 µA** about 30 s after it closes: the unit deep-sleeps until a detent
   starts a new window (field-notes.md §27). Do not leave an unpaired unit on
   a cell with the window open.
4. Pair it ([commissioning.md](commissioning.md)). Check the border router is
   up first.
5. Wait 3 minutes, knob untouched. **Pass:** a 10 s window averages on the
   order of 100 µA with a flat baseline (91 µA measured on node 26), and the
   controller shows a battery voltage within 1 % of the source.
6. Turn one detent. **Pass:** the screen changes view and the trace shows one
   burst of about 2 s at ~40 mA, then the flat baseline again.

Reference values: [power-budget.md](power-budget.md).

## Stage 5 — driver board, display and case

1. Solder 2×7 female headers to the driver board (it ships with bare holes,
   see below). Wash, dry, and run one bench boot: the coupling scan must pass
   before anything else is attached.
2. Cut the Grove cable and solder the SHT40: SDA → D4, SCL → D5, VCC → 3V3,
   GND → GND. Position the sensor **in the case airflow path, away from MCU
   heat**; self-heating skews readings.
3. Encoder B, push switch and LED solder to the driver board's D6, D9 and D7
   through-holes. The encoder needs soldered leads: its blades seat in neither
   breadboard springs nor Dupont sockets.
4. USB-C panel pigtail → XIAO USB port (mechanical detail pending the case
   redesign). **Charging only works with a USB A-to-C cable**: the 2-wire
   pigtail has no CC resistors, so C-to-C supplies won't enable VBUS.
5. Multimeter polarity check (above), then the battery to the BAT wires.
6. Seat the XIAO on the driver board, **USB-C end pointing away from the FPC
   connector**. The board's RST/5V silkscreen marks the XIAO's USB end, at the
   opposite end of the board from the ribbon. Seated 180° out, nothing works
   and nothing is obviously wrong to look at.
7. Connect the 24-pin FPC (orientation rule below), repeat Stage 3 tests 1–5,
   then fit into the case.

**Case rev 5** ([hardware/case](../hardware/case/README.md)) is built for this
stack, floor upward: the cell flat on the floor, the tray on the cell, the
XIAO in its sockets on the driver board, the panel against the front. Two
things differ from the breadboard build:

- **Trim the pins under the driver board to ~1.5 mm** once the encoder, LED,
  switch and SHT40 are soldered to it. As built for the breadboard they stand
  9.0 mm proud, and rev 5's depth assumes they are gone; after trimming the
  board no longer plugs into a breadboard.
- The cell's leads (~29 mm) and the USB-C panel connector's long leads coil
  in the free bay at one end. Foam tape holds the cell to the floor and the
  tray to the cell (the case has no cradle).

Rev 5 has not been printed; the first set is the test fit
([bringup.md](bringup.md), Case & mechanical).

## Symptom → cause, from this build

| Symptom | Cause found |
|---|---|
| 0 V on every pin, no beep on known-good wires | meter probe lead loose in its jack |
| Board drops off USB the moment the knob turns; encoder A never changes in the log | encoder wire on the 3V3 pad beside MTCK; each detent shorts the rail |
| Self-test reads encoder A `held HIGH` | consistent with the wire on 3V3; not recorded on a correct MTCK wire, so not a verdict |
| Press never registers, rotation fine | wire loose in the D9 row |
| One encoder line dead, which one changes between runs | bare encoder blades in a breadboard |
| A pin at 0 V under power that reads open unpowered | conductive flux residue |
| Battery reads the same whatever the source voltage | the source setting did not apply (meter the source first; retro.md T2), or the divider top on the 3V3 rail, not BAT+ |
| Cell reads 0 V | protection latched, or the probe is on the housing |
| Console silent after a flash, port present | board left in download mode or wedged by the reset pulse: replug USB |
| 28 mA average on battery | unit is unpaired with its window open |
| Paired floor well above ~57 µA, polls above ~0.5 mC, 1 ms wakes with no radio | a non-wake pin with a level interrupt isolated in sleep (field-notes.md §28); bisect the firmware on the same board |
| Healthy cell, unit resets continuously on it, LED flickers faintly | resistance in the battery path: [battery-runbook.md](battery-runbook.md) B3 |

### FPC orientation: go by insertion force, not by which way the copper faces

**The correct orientation slides in with light finger pressure. The reversed
one needs force.** That is the reliable test; "contacts down" is ambiguous
depending on how you are holding the board, and getting it wrong is not a
no-op. Reversing the ribbon mirrors the pin order — tab *n* meets panel pin
25−*n* — which lands the panel's VDDIO on RST and VCI on BUSY. The MCU is then
driving a supply rail: pulling RST low shorts it, and the board browns out.
Two panels died during bring-up (2026-08-18/22).

Procedure: flip the black latch up, slide the ribbon in until the **stiffener
is inside the housing** (not merely "as far as it will go" — a ribbon stopped
short still latches and makes intermittent contact), press the latch closed.
Insert and remove only with the power off.

**The driver board expects the panel's copper contacts facing UP**, away from
the board. Confirmed on the bench twice: 2026-08-22 (first successful refresh)
and 2026-08-25 (recovery from a misseated ribbon). Get this wrong and the
symptoms do not say "wrong orientation" — see [field-notes.md](field-notes.md)
section 15, where a misseated ribbon put a panel supply rail onto MOSI and
presented as a dead panel and then as a firmware bug.

Still use the insertion-force rule as the working check: it holds whichever way
you happen to be holding the board, and "up" does not.

**Handle the bare flex as an ESD-sensitive part.** One panel failed after a
successful refresh with nothing electrically suspicious in between; ESD from
handling is the leading guess but is unproven. Ground yourself before touching
the ribbon, and hold the panel by the glass edges.

## The driver board carries every pin this build needs

**Confirmed from the board's silkscreen 2026-08-17/18.** The V2 driver board
is a straight carrier for the XIAO: two 7-pin columns matching the XIAO's 14
pins one-for-one. It renames only the six display signals and passes the rest
through under their own names:

| Driver board label | XIAO pin | Used for |
|---|---|---|
| RST / CS / BUSY / DC | D0 / D1 / D2 / D3 | ePaper control |
| MOSI / SCK | D10 / D8 | ePaper SPI |
| 5V / GND / 3V3 | same | power |
| **D4 / D5** | D4 / D5 | **SHT40 I2C** |
| **D6** | D6 | **encoder B** |
| **D7** | D7 | **LED** |
| **D9** | D9 | **encoder push switch** |

So once female headers are fitted, the SHT40, LED, encoder B and push switch
all solder to the **driver board's** through-holes rather than to the XIAO —
easier joints on bigger pads. Four connections need the XIAO's underside pads:
encoder A (MTCK/GPIO6), battery divider node (MTMS/GPIO4), and BAT+/BAT−.

**Settle before soldering:** which face the XIAO seats on. Dry-fit both ways
and pick the one that leaves the USB port accessible and clears the FPC
connector. Unverified from photos; desoldering 14 pins is the job to avoid.

## ⚠️ The driver board ships with bare holes

**Found on hardware 2026-08-17.** The Seeed ePaper Driver Board V2 arrives
with **unpopulated through-holes** — no female headers fitted. The XIAO
cannot seat on it until 2×7 female header strips are soldered in.

This cost most of a bench session. A jumper wire pushed into a bare plated
hole makes contact only by luck, and the resulting intermittent connections
imitate real faults convincingly: BUSY reading as a floating line (panel
appears dead), the SHT40 dropping off the I2C bus between consecutive
resets, and two USB brownouts severe enough that Windows reported
`Set Address Failed` / `Device Descriptor Request Failed`.

- Solder the headers **before** any further bring-up. Required for the final
  build regardless.
- **Electronics flux only** — rosin-core wire or a no-clean (J-STD-004) pen.
  Plumbing paste flux (ASTM B-813, e.g. AIM Nitro) left ionic residue on
  driver boards #1 and #2 that conducted kΩ between adjacent pins under bias
  and cost days ([field-notes.md](field-notes.md) section 17).
- **After soldering: two-stage clean, dry, scan.** IPA flood drained off the
  edge, then hot soapy water + distilled rinse, dry hard (bores hold water).
  Then one bench-profile boot: the harness scan must print
  `coupling scan: no pin follows any other` before anything else is attached.
- **Confirm which face the XIAO seats on before soldering** — desoldering 14
  pins is the worst job in this build.
- Preferred bench topology afterwards is the final-build one: XIAO seated
  directly in the driver board (no jumpers at all), SHT40 on the board's
  D4/D5 breakout holes.

## HW-VERIFY

- ~~Confirm BAT+/BAT− pad markings on this XIAO revision before soldering.~~
  **Closed 2026-09-28** — node 26 charges through them and reports the source
  voltage within 0.5 %.
- ~~Confirm FPC contact orientation for this panel batch.~~ **Closed
  2026-08-22** — resolved by the insertion-force rule above; panel refreshed
  full and partial on driver board #1.

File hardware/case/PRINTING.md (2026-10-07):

# Printing the rev 5 back

One part: **`stl/case-back-wallmount.stl`**. The front, tray and knob from the
earlier print are reused; only the back changed.

## The part

| | |
|---|---|
| Size | 116.3 × 59.3 × 31.0 mm (fits any bed) |
| Plastic | about 27 cm³ solid, so roughly 30–35 g of PLA |
| Material | **PLA**, black or dark grey. PETG also works |
| Copies | 1 for now (a test fit). Two more later if it fits |

## Orientation

Print it **as the file comes in**: the flat back with the two rails on the bed,
the open side facing up. Do not rotate it. The slicer drops it to the bed on
the rails.

## Settings (any slicer: PrusaSlicer, Orca, Bambu Studio, Cura)

| Setting | Value | Why |
|---|---|---|
| Nozzle | 0.4 mm | |
| Layer height | 0.2 mm | |
| Walls / perimeters | **3** | the shell walls are 1.44 mm: three 0.45 mm lines plus the slicer's gap fill make them solid |
| Top / bottom layers | 5 / 5 | |
| Infill | 20 %, any pattern | the walls are thinner than the infill would matter |
| Supports | **build plate only** | the keyhole pockets inside the two rails need it; nothing inside the box does |
| Brim | 5 mm | the part is 116 mm long; a brim stops the corners lifting |
| Speed | the slicer's normal PLA profile | |

The slicer may warn about **33 non-manifold edges** or offer to repair the
mesh. Accept the repair. The same 33 edges are in the original model, and the
part has been printed from it before.

## Checks after printing

1. **Height:** 31.0 mm from the bed side of the rails to the top rim.
2. **Inside depth:** about 26.6 mm from the inside floor to the rim.
3. **USB-C hole:** the round hole in the short side wall, 12.8 mm across. The
   USB-C panel connector should push through and its nut thread on.
4. **Front fit:** the existing front should sit on the rim the same way it sat
   on the old back. Nothing about the rim changed.
5. **Keyhole slots:** clear any support out of the two slots in the rails; a
   #6 pan-head screw head should drop into the round end and slide up.

## What changed from the last print

The old back was 23 mm tall and too shallow: the 2000 mAh cell and the
board stack did not fit together. This one is the same box raised 8 mm, cut
above the USB-C hole and joined with a straight band, so everything else
(holes, rails, rim, corner screw posts) is where it was.

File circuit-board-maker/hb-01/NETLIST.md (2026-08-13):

# homecadia sensor-01 harness board — netlist

Board `hb-01`, 48 x 40 mm, 2 layer, 1.6 mm FR4.
Generated 2026-08-13. **Never opened in KiCad — see the warning in README.md.**

## Components

| Ref | Value | Footprint | LCSC | Note |
|---|---|---|---|---|
| J1 | USB-C 16P | `Connector_USB:USB_C_Receptacle_XKB_U262-16XN-4BVC11` | [C2765186](https://www.lcsc.com/product-detail/C2765186.html) | power only; D+/D- to test pads |
| R1 | 5.1k | `Resistor_SMD:R_0805_2012Metric` | — | CC1 pulldown |
| R2 | 5.1k | `Resistor_SMD:R_0805_2012Metric` | — | CC2 pulldown |
| D1 | SP0503BAHTG | `Package_TO_SOT_SMD:SOT-143` | [C3040626](https://www.lcsc.com/product-detail/C3040626.html) | ESD array on VBUS/D+/D- |
| R3 | 1M 1% | `Resistor_SMD:R_0805_2012Metric` | — | divider high side |
| R4 | 1M 1% | `Resistor_SMD:R_0805_2012Metric` | — | divider low side |
| C1 | 100nF | `Capacitor_SMD:C_0805_2012Metric` | — | ADC hold cap |
| R5 | 1k | `Resistor_SMD:R_0805_2012Metric` | — | LED series |
| D2 | LED 3mm | `LED_THT:LED_D3.0mm` | — | or 2-pin header to panel LED |
| SW1 | PEC11R-4220F-S0024 | `Rotary_Encoder:RotaryEncoder_Bourns_Vertical_PEC12R-3x17F-Sxxxx` | — | PEC12R fp: terminals verified vs PEC11R datasheet; boss holes 3.1mm oval, unverified |
| J2 | XIAO field 2x7 | `Connector_PinHeader_2.54mm:PinHeader_2x07_P2.54mm_Vertical` | — | labelled field to XIAO / driver-board breakout |
| J3 | BAT JST-PH | `Connector_JST:JST_PH_B2B-PH-K_1x02_P2.00mm_Vertical` | [C131337](https://www.lcsc.com/product-detail/C131337.html) | polarity is NOT guaranteed by the key |
| J4 | SHT40 JST-SH | `Connector_JST:JST_SH_BM04B-SRSS-TB_1x04-1MP_P1.00mm_Vertical` | — | to sb-01 satellite |
| J5 | 5V out | `Connector_PinHeader_2.54mm:PinHeader_1x02_P2.54mm_Vertical` | — | VBUS/GND to XIAO 5V pin |
| TP5 | USB_DP | `TestPoint:TestPoint_Pad_D1.5mm` | — | USB D+ break-out |
| TP6 | USB_DM | `TestPoint:TestPoint_Pad_D1.5mm` | — | USB D- break-out |
| TP1 | VBAT | `TestPoint:TestPoint_Pad_D1.5mm` | — |  |
| TP2 | VDIV | `TestPoint:TestPoint_Pad_D1.5mm` | — |  |
| TP3 | GND | `TestPoint:TestPoint_Pad_D1.5mm` | — |  |
| TP4 | 3V3 | `TestPoint:TestPoint_Pad_D1.5mm` | — |  |
| H1 | M2 | `MountingHole:MountingHole_2.2mm_M2` | — |  |
| H2 | M2 | `MountingHole:MountingHole_2.2mm_M2` | — |  |
| H3 | M2 | `MountingHole:MountingHole_2.2mm_M2` | — |  |
| H4 | M2 | `MountingHole:MountingHole_2.2mm_M2` | — |  |

## Nets

| Net | Nodes |
|---|---|
| `+3V3` | J2.12, J4.1, TP4.1 |
| `CC1` | J1.A5, R1.1 |
| `CC2` | J1.B5, R2.1 |
| `ENC_A` | J2.8, SW1.A |
| `ENC_B` | J2.10, SW1.B |
| `ENC_SW` | J2.14, SW1.S1 |
| `GND` | J1.A1, J1.B1, J1.A12, J1.B12, R1.2, R2.2, D1.2, R4.2, C1.2, D2.1, SW1.C, SW1.S2, J2.1, J3.2, J4.4, J5.2, TP3.1 |
| `LED_A` | J2.7, R5.1 |
| `LED_K` | R5.2, D2.2 |
| `SCL` | J2.6, J4.2 |
| `SDA` | J2.5, J4.3 |
| `USB_DM` | J1.A7, J1.B7, TP6.1 |
| `USB_DP` | J1.A6, J1.B6, D1.1, TP5.1 |
| `VBAT` | J3.1, R3.1, TP1.1 |
| `VBUS` | J1.A4, J1.B4, J1.A9, J1.B9, D1.3, J5.1 |
| `VDIV` | R3.2, R4.1, C1.1, J2.13, TP2.1 |

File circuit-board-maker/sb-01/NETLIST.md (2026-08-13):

# homecadia SHT40 satellite — netlist

Board `sb-01`, 14 x 16 mm, 2 layer, 1.6 mm FR4.
Generated 2026-08-13. **Never opened in KiCad — see the warning in README.md.**

## Components

| Ref | Value | Footprint | LCSC | Note |
|---|---|---|---|---|
| U1 | SHT40-AD1B-R2 | `Sensor_Humidity:Sensirion_DFN-4_1.5x1.5mm_P0.8mm_SHT4x_NoCentralPad` | [C2909890](https://www.lcsc.com/product-detail/C2909890.html) | DFN-4 no central pad; needs reflow or hot air |
| C1 | 100nF | `Capacitor_SMD:C_0805_2012Metric` | — | decoupling |
| J1 | JST-SH 4P | `Connector_JST:JST_SH_BM04B-SRSS-TB_1x04-1MP_P1.00mm_Vertical` | — | to hb-01 J4 |
| H1 | M2 | `MountingHole:MountingHole_2.2mm_M2` | — |  |

## Nets

| Net | Nodes |
|---|---|
| `+3V3` | U1.1, C1.1, J1.1 |
| `GND` | U1.3, C1.2, J1.4 |
| `SCL` | U1.2, J1.2 |
| `SDA` | U1.4, J1.3 |

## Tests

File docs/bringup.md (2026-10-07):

# Hardware bring-up checklist

Every `HW-VERIFY` marker in source or docs gets a row here. Nothing ships
(milestone 6) with open rows. Parts are still in transit; this list grows as
pre-hardware code is written.

Bench wiring diagrams and the no-solder connectivity procedure live in
[diagrams/](diagrams/).

## Flash & console (verified on unit 1, 2026-08-08)

- [x] Flashes over native USB from WSL2 (usbipd path; see
      [build.md](build.md) for the gotchas). Chip: ESP32-C6FH4 (QFN32) v0.2 —
      FH4 = **4MB embedded flash, confirmed**; matches the `partitions.csv`
      4MB OTA layout.
- [ ] **OTA slot headroom.** App image is 0x195990 (1.66MB) of the 1.92MB
      (0x1E0000) OTA slot — **84% full, 16% free** as of 2026-08-23 with
      milestone 5–6 features still landing. **2026-10-05, shipping build at
      `9ccc68b` on the pinned image: 0x195100 (1,659,136 bytes), 84 % full,
      0x4AF00 (306,944 bytes) free** — 2,192 bytes smaller than on 2026-08-23
      despite the dial wake, unpaired deep sleep and the Thread diagnostics
      counters. Bootloader 0x56A0, 55 % of its slot free. Check after every feature merge; overflow forces a partition
      rework and a full reflash of deployed units (`partitions.csv` note).
- [x] USB console stays enumerated with the app running —
      `CONFIG_USJ_NO_AUTO_LS_ON_CONNECTION=y` verified: port alive
      indefinitely; without it, dead in <2s (light sleep powers down USB-SJ).
- [x] Firmware boots on hardware — **re-verified 2026-08-17 after fixing a
      boot loop the 2026-08-08 check missed.** `abort()` fired ~1.3s after
      `app_main()`: `CONFIG_ICD_ACTIVE_MODE_THRESHOLD_MS=1000` is below the
      5s LIT ICD minimum enforced by a VerifyOrDie in connectedhomeip
      `ICDManager.cpp:82`. The chip had accumulated **11,374 reboots** by the
      time the loop was caught on the bench (NVS reboot-count), so a
      seconds-long look at a boot banner is not a boot verification — watch
      the console ≥30s. Now boots to `Server Listening...` with the SHT40
      attached.
- [x] Onboarding codes verified from a live console — **2026-08-23**: console
      printed `QRCODE: MT:Y.K9042C00KA0648G00` and the manual code 34970112332
      commissioned the device.

## Pins & wiring

- [ ] XIAO ESP32-C6 D-pin → GPIO mapping matches [pinmap.md](pinmap.md)
      (check against the official pinout diagram and a continuity test).
- [x] ePaper driver board V2 actually uses D0=RST, D1=CS, D2=BUSY, D3=DC,
      D8=SCK, D10=MOSI — **silkscreen-confirmed 2026-08-17** (back of the
      board labels the D0–D3/D8/D10 positions RST/CS/BUSY/DC/SCK/MOSI by
      function). **Electrically confirmed 2026-08-22** — the panel refreshed
      with these assignments. Bonus: the board breaks out D4/D5 as
      labelled through-holes — a candidate solder point for the SHT40 in
      final assembly instead of the XIAO pins.
- [x] **Driver board is a pure pass-through on every data line — schematic-
      verified 2026-08-25** (`ePaper_Driver_Board.pdf`, Seeed, rev 1.0,
      2024-12-09): CN1/CN2/CN4 route D0–D10 straight to the FPC or to the
      header pins with no pull-ups, series resistors, buffer or level shifter.
      D4/D5/D6/D7/D9 reach nothing on the board except the header. The slide
      switch (CN6) is in the **battery** path only — it does not gate 3V3 or
      the panel. So any pull-up seen on D3/D8/D10 is the panel's, and a
      "held HIGH" on D4/D5 is coupling from a neighbour, not a board pull-up
      (an earlier row here claimed I2C pull-ups on D4/D5; it was wrong).
- [x] BAT+/BAT− underside pad markings confirmed on this XIAO revision —
      **2026-09-28**, XIAO #4 (node 26): runs from a 3700 mV source on those
      pads and reports 3682 mV.
- [x] **Underside signal wires proven on the right pads — 2026-09-28**, XIAO
      #4, by the unpowered exclusion tests and the powered tests in
      [assembly.md](assembly.md) stages 2–3. On XIAO #3 the encoder wire was
      on the 3V3 pad beside MTCK ([field-notes.md](field-notes.md) §25).
- [ ] EEMB battery lead polarity measured with multimeter — **all 3 cells,
      before first connection** ([assembly.md](assembly.md) warning).
- [x] Battery divider reads Vbat/2 — on **MTMS/GPIO4**, not MTDI (see the
      Encoder & LED section rows dated 2026-09-02 and 2026-09-12).
- [ ] USB A-to-C cable charges the battery through the panel pigtail;
      charge LED on XIAO behaves as documented.

## Power & sleep

- [x] ~~GPIO6 (MTCK) wakes the C6 from deep sleep on encoder press.~~
      **Superseded 2026-09-23, closed 2026-09-28.** The firmware sleeps in
      light sleep, not deep sleep, and GPIO6 carries encoder A, not the
      switch. A detent wakes the chip: see "Dial works on battery" under
      Encoder & LED.
- [x] **Runs on a real cell — 2026-09-28/29, 21 h soak.** Node 26 (XIAO #4,
      shipping image, paired) on an EEMB LP103454 through the BAT pads, USB
      out. 2026-09-28 16:33: 3978 mV / 82 %, `RebootCount` 504. 2026-09-29
      13:42: **3978 mV / 82 %, `RebootCount` 504**, available throughout; the
      matter server logged no availability change, timeout or unresponsive
      peer for the node in those 21 h. The voltage is re-measured with every
      report (`sensor_loop.cpp`), and temperature and humidity moved in the
      same reports, so the reading is live. It agrees with the DIAG view
      (3.98 V) and a meter (3.97 V). What it shows: no heavy drain (28 mA
      would have taken ~590 mAh, about 30 %). What it cannot show: the
      238 µA figure itself, which predicts ~5 mAh (0.25 %) in 21 h, inside
      the reading's resolution. A week-long read is the test for that. The
      battery path is still through breadboard contacts, which caused a
      reset loop before the soak ([battery-runbook.md](battery-runbook.md)
      B3).
- [x] **Unpaired unit deep-sleeps and the dial wakes it — verified
      2026-10-01/02**, XIAO #4. `app_main.cpp`, `unpaired_sleep_check()`
      and `unpaired_sleep_on_boot()`. When the 15-minute commissioning window
      has closed with no fabric (or 16 minutes after boot, whatever the window
      reads, unless a pairing holds the fail-safe), the unit draws the
      onboarding screen with "Asleep. Turn the dial to start pairing.",
      restarts, and enters deep sleep from the top of the next boot, before
      Bluetooth, Thread, the PHY or power management exist. Encoder A (GPIO6,
      an LP pin) wakes it; a woken boot releases the pad hold and restarts
      once more, cleanly. Evidence: **19.71 µA and 19.85 µA** in deep sleep
      (PPK2 3700 mV, USB out, two 10 s windows); dial wake 5 of 5 on battery
      and 5 of 5 on USB, every wake booting in under 4 s; the real path on the
      shipping image: power on 23:46, window closed ~00:01, flat sleep line
      30 s later; two pairings completed, one with the window closing about
      55 s into it (node 28, 2026-10-02). Three earlier designs failed and are
      in [field-notes.md](field-notes.md) §27. Not covered: a unit removed
      from its controller (same reboot path, not re-tested). Bench profile:
      off (`CONFIG_HOMECADIA_UNPAIRED_DEEP_SLEEP`); `tools/check-profiles.sh`
      asserts it is on, and the test shortcut is 0, in shipping.
- [x] **Unpaired current — measured 2026-09-28: 28.1 mA average.** Shipping
      image on XIAO #4 before commissioning, PPK2 3700 mV, 10 s window:
      baseline 20–40 mA, ~200 mA spikes every 0.5 s (the 500 ms pairing
      advertisement interval). The chip does not enter light sleep while
      unpaired; cause not established. The `ot_sleep` lock first suspected
      (field-notes.md §26) is `ESP_PM_APB_FREQ_MAX` and does not block light
      sleep; that explanation was retracted 2026-10-02. Worked around: an
      unpaired unit deep-sleeps once its window closes (row above). Three minutes after
      commissioning the same unit averaged **91 µA** over a quiet 10 s with
      one parent poll in the window.
- [x] Light sleep does not hang — **fixed 2026-09-15** by turning off
      `CONFIG_PM_POWER_DOWN_PERIPHERAL_IN_LIGHT_SLEEP`. ESP-IDF v5.5.5 marks it
      experimental (default n), but Espressif's own C6 sleepy references turn
      it on — esp-matter `examples/icd_app`, IDF `ot_sleepy_device/light_sleep`
      — and the milestone-1 scaffold copied `icd_app`. With it on,
      the first real light-sleep run (PPK2 Source Meter, USB out) stopped
      waking 8 min after boot, at a 120 s sensor poll: 10–33 µA, no wakes at
      all, dropped by its Thread parent, marked unavailable by the controller.
      With it off — the only difference, sdkconfigs diffed — 38 min on the
      PPK2 with no radio-poll gap over 5.0 s and no subscription loss. A USB
      run cannot show this: `CONFIG_USJ_NO_AUTO_LS_ON_CONNECTION=y` keeps the
      chip out of light sleep while a host is attached
      ([field-notes.md](field-notes.md) §20). **Reproduced 2026-09-15** with
      the ADC fix in and the TOP domain genuinely powering down: stopped again
      at the 4th 120 s poll, ~480 s after boot. **Cause found the same
      evening** — a light sleep landing inside the battery ADC sequence, which
      changes the sleep power-domain config as the oneshot unit is created and
      deleted. Fixed with an `ESP_PM_NO_LIGHT_SLEEP` lock in `battery.cpp`;
      the workaround (option off) is retired.
- [x] Sleep current measured — **2026-09-15, over budget.** Shipping image
      (with the fix above), PPK2 Source Meter 3700 mV, USB out, no cell, 38 min
      settled: **696 µA average**, radio-free seconds **~376 µA** median.
      Target ≤300 µA ([power-budget.md](power-budget.md)); projects to ~3.3
      months on 1700 mAh usable. Two separate costs, both open: the floor
      between polls is ~10× the modeled 15–40 µA (the ~1 kHz pulse train is
      the XIAO's SGM6029 buck in power-save mode, not wakes; ~95 µA of the load
      behind it was the modem power domain, held on by the battery ADC — see
      the next item), and every 20–40 s
      a 30 ms transmission drops the device into ICD active mode, 500 ms fast
      polls for the 5 s threshold, with no controller exchange to explain it.
      A 150 s capture on the border router's `wpan0` saw one Matter exchange
      (the 2 min keepalive), so the episodes stay on the link to the parent,
      which reports a 20% frame error rate to the sensor at −77 dBm. Our
      active-mode threshold is 5 s against `icd_app`'s 1 s for SIT (the device
      runs SIT: no check-in client registered), so each episode costs ~5× the
      reference's.
      Seeed's ~15µA figure remains unverified
      ([source-reliability.md](source-reliability.md)).
- [x] **Modem power domain off in sleep — fixed 2026-09-15, worth ~95 µA.** A diagnostic image (`CONFIG_HOMECADIA_SLEEP_DIAG`) showed
      the chip asleep 98–99% of the time with ~2 timer wakes/s and no pin
      wakes, but the modem power domain **on for 100% of sleep time**. Cause:
      `battery.cpp` held its oneshot ADC unit from boot, and on the C6
      `adc_oneshot_new_unit()` pins the modem domain on until the unit is
      deleted (`ADC_LL_ADC_FE_ON_MODEM_DOMAIN`, `esp_adc/adc_oneshot.c`). Fix:
      create and delete the unit around each reading. Measured with the fix:
      modem on 0% of sleep time, quiet floor **376 → 282 µA**. Still ~225 µA
      above Espressif's 55 µA reference.
- [x] **Quiet floor near the reference — 52 µA, 2026-09-15.**
      The TOP domain only powers down once the I2C and SPI buses ask for it
      (`flags.allow_pd`, `SPICOMMON_BUSFLAG_SLP_ALLOW_PD`; added 2026-09-15 to
      `sht40.c` and `ssd1680.c`) *and*
      `CONFIG_PM_POWER_DOWN_PERIPHERAL_IN_LIGHT_SLEEP=y`. With both: flags
      `0x20007c17`, quiet floor **52 µA**, all-in average **230 µA** over 74 s
      with a heavy radio burst in it. The §20 hang that this option used to
      bring was bisected the same evening to a light sleep landing inside the
      battery ADC sequence; `battery.cpp` now holds an `ESP_PM_NO_LIGHT_SLEEP`
      lock across it (20 min clean, full poll). Option back on in
      `sdkconfig.defaults` ([field-notes.md](field-notes.md) §21).
- [x] **Overnight soak of the shipping image — 2026-09-16, no hang.**
      `0.6.0-dev.84+e0760b0`, PPK2 3700 mV, 15:18 → 22:56 (7 h 39 min), node 25
      answered a fresh `interview_node` at +85 min, +7.7 h and at the end.
      Whole run **288.5 µA** (7.94 C); one settled 120 s cycle **240.6 µA**;
      quiet floor 59 µA. Radio is now ~155 µA of the 240: the 5 s slow poll
      (~22 × ~0.58 mC per cycle) and the ~10-poll fast tail after each report.
      Slow poll raised 5 s → 30 s in `sdkconfig.defaults`
      ([field-notes.md](field-notes.md) §22).
- [x] **Slow poll re-measured — 2026-09-17.** 12 h 37 min, no hang. Polls
      land 15 s apart, not 30: no ICD client is registered, so the stack runs
      SIT mode and clamps. Whole run **237.7 µA**, settled 120 s cycle
      **207.8 µA** (was 288.5 / 240.6). One `interview_node` costs ~150 mC,
      about ten minutes of normal running — keep liveness checks rare.
- [x] **ADC calibration at two voltages — 2026-09-12.** *(Superseded
      2026-09-22 by the shipping-image calibration below; `VBAT_OFFSET_MV` no
      longer exists.)* PPK2 as the cell
      (Source Meter, USB out). True BAT+ 3.36 V → firmware 3.02 V; true
      3.97 V → firmware 3.64 V. Same 0.33–0.34 V short at both points, slope
      1.02: a **constant offset, not a gain error**. ~0.17 V at the pin across
      the divider's 500 kΩ source impedance = ~0.34 µA of ADC input current.
      Divider itself is exact (SENSE tracks the source at 0.476× on a 10 MΩ
      meter, the correct number for 1M+1M). Fix is `+340 mV` in
      `battery_read_mv()` — **applied 2026-09-13** as `VBAT_OFFSET_MV`
      (bench image, flashed from Windows, fabric kept). The same USB-no-cell
      source read 3972 mV before the flash and 4308 mV after, a +336 mV step:
      proof the offset is in the image, not a third calibration point — the
      charge chip's no-cell output was never metered. A 0 reading stays 0.
- [x] **Battery ADC calibrated on the shipping image — 2026-09-22.**
      `VBAT_OFFSET_MV` is gone; `battery.cpp` now scales the pin reading by
      `VBAT_SCALE_X1000 2038` (ideal 1M:1M is 2000; the ADC input loads the
      500 kΩ source ~1.9 %). Also `SAMPLES` 8 → 64 and `VBAT_ADC_SETTLE_MS`
      5 → 20: report-to-report scatter fell from ±120 mV to 4 mV. PPK2 source,
      BAT+ metered in-circuit, settled Matter reports of `3/47/11`:

      | BAT+ | Reported | Error | Role |
      |---|---|---|---|
      | 3.68 V | 3616 → ×1.0176 (n=5) | — | fit |
      | 4.00 V | 3921 → ×1.0201 (n=3) | — | fit |
      | 3.39 V | **3389, 3387** | −1 to −3 mV | check, fitted image |

      The first report after each boot reads ~80 mV low (3307 at 3.39 V;
      3536 at 3.68 V on the previous image); cause not established. Earlier
      2026-09-22 this row was nearly closed with an offset of 0 from a
      comparison against the divider midpoint — wrong, see field-notes §23.

## Display

- [x] **Panel draws — verified 2026-08-22** on driver board #1 with the XIAO
      seated directly (no jumpers), SHT40 on Grove. Full refresh holds BUSY
      high 1790ms, partial 540ms; readings render with `LOW BATT` (no cell
      fitted, 824mV on the divider reads as 0%). Image upright with
      `DISPLAY_FLIP_LONG_AXIS 1`, short axis 0.
- [x] **FPC seating is the least reliable joint — re-verified 2026-08-25.** A
      misseated ribbon put a panel supply rail onto the MOSI net: D10 sat at
      3.1V and could not be driven low, so every byte clocked to the panel was
      `0xFF` and it went deaf. It read as a dead panel, and the stale QR left on
      the glass read as an unpaired device; neither was true. **Check the
      connection before the firmware** — see [field-notes.md](field-notes.md)
      section 15. `ssd1680_init()` now scans and drive-tests every panel signal
      at boot; `drive hi=1 lo=0 follows the driver` on all five outputs is the
      precondition for anything else being worth investigating.
- [x] **Panel deep-sleep current — bounded 2026-10-06, not isolated.** The
      driver sends the panel to deep sleep (command 0x10, mode 1) after every
      refresh (`ssd1680.c:201-204`, `:247`). Whole unit in deep sleep at
      3700 mV: 21.2 µA (field-notes.md §29). Known parts: ESP32-C6 7 µA
      (datasheet v1.5 Table 5-11), SGM6029 2.3 µA (datasheet p.5), divider
      1.85 µA. Panel, driver board and SHT40 together: **≤ ~10 µA**. Isolating
      it needs the XIAO unseated from the driver board's header (3V3 runs
      through a header pin); not worth it against a 108–125 µA average.
- [x] **Partial and full refresh charge — measured 2026-10-04/05**, node 28:
      partial ~6–7.5 mC, full ~19 mC ([power-budget.md](power-budget.md)).
- [x] **Ghosting acceptable at `DISPLAY_FULL_REFRESH_EVERY_N` 10 — 2026-10-06**,
      by the builder after weeks on the readings screen: no leftover digits
      between full refreshes. The brief dark screen on boot and on wake is
      the full refresh's clearing pass, not a fault.

### Bring-up post-mortem, 2026-08-18 → 22

Two days were spent probing pins for a fault that was mostly mechanical. What
actually went wrong, in the order it mattered:

1. **The FPC was in reversed.** Flipping the ribbon mirrors the pin order (tab
   *n* meets panel pin 25−*n*), which puts the panel's VDDIO on RST and VCI on
   BUSY — the MCU ends up driving a supply rail, and pulling RST low browns the
   board out. The insertion-force rule and the rest of the handling procedure
   are in [assembly.md](assembly.md#fpc-orientation-go-by-insertion-force-not-by-which-way-the-copper-faces).
2. **The ribbon was not seated to the stiffener.** It latched and made
   intermittent contact, which looks identical to a dead panel.
3. **The XIAO was seated 180° out** on board #2. USB-C points *away* from the
   FPC connector.
4. **The firmware could not tell a working panel from a silent one.** `busy_wait()`
   returned `ESP_OK` the moment BUSY read low, which is also the resting state
   of a panel that received nothing, so every refresh reported success while
   nothing was drawn. Fixed by requiring BUSY to *rise* after
   `CMD_MASTER_ACTIVATE` (`ssd1680.c`). Without that check the hardware fault
   was invisible from the log, which is why it was hunted with a multimeter.

Instrumentation that was wasted effort: pin-to-pin bridge sweeps, ADC line
voltages, and an output-drive test (which gave a false STUCK verdict on RST/CS
because configuring an ADC channel disconnects the digital driver). The one
useful measurement was the BUSY timing above.

### Component status, 2026-08-22

| Item | State |
|---|---|
| Panel A (first used) | **dead** — SDA shorted to VDDIO, 16–50Ω |
| Panel B | **dead** — same short, failed after one successful refresh |
| Panel C | **working** — the only good panel left |
| Driver board #1 | working; retains kΩ leaks (see [power-budget.md](power-budget.md)) |
| Driver board #2 | **connector damaged** — bridges tabs 14/15 (SDA↔VDDIO) at 19–49Ω with any ribbon seated, open with none. Not usable for a display |
| Driver board #3 | unopened, headers not fitted |
| XIAO (unit 1) | healthy — D10 to 3V3 open with the board removed |

Blocker: **2 of 3 panels are gone and there is no spare.** Reorder Seeed SKU
104990853 before the next two units are assembled.
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

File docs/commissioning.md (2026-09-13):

# Commissioning — sensor-01 → Home Assistant

Verified end to end, most recently **2026-08-24 on matter-server 1.4.0**: the
device commissions over BLE through **Home Assistant's own proxy** in 18-19
seconds, attaches as a sleepy child of the ZBT-2, and serves
temperature/humidity/battery over Thread.

The 2026-08-23 run needed a separate Node/noble proxy pod because HA's proxy
could not complete the BTP handshake. **That is fixed** — it was
matter-js/matterjs-server#1006, resolved upstream in v0.8.0, and this deployment
was three months behind. The noble pod and the disable/enable dance are gone.

## What is deployed

Home Assistant here is a **container on k3s, not HAOS** — there is no add-on
store, so the Matter server and the border router are separate workloads.

| | |
|---|---|
| Matter server | `ghcr.io/matter-js/matterjs-server:1.4.0` (matter.js 0.17.9) — **not** python-matter-server |
| Runs on | the node holding the ZBT-2 (`zbt2` label), `hostNetwork`, port 5580 |
| Key env | `BLE_PROXY=true`, `ENABLE_TEST_NET_DCL=true`, `PRIMARY_INTERFACE` pinned |
| Border router | `otbr`, same node, ZBT-2 passed through as a char device |
| Home Assistant | `ha2-home-assistant` on `k8sn1-master` (the node with the Bluetooth adapter) |
| Thread network | `ha-thread-5df4`, channel 15 |

HA's Matter integration points at `ws://<matter-server-host>:5580/ws`. The
manifests live in the homelab repo under `kubernetes/apps/default/`.

**Keep the image current.** This deployment sat on 0.7.1 for months against a
then-current 1.4.0, and the cost was two evenings chasing a BLE bug that had
been fixed upstream twelve days after the pinned tag. See
[field-notes.md](field-notes.md) §12.

## Three preconditions

Commissioning fails in a different, confusing way for each of these. Check all
three before starting.

### 1. The server must trust test certificates

Self-built devices carry esp-matter's **test DAC**, signed by a PAA that is not
in the production DCL. Without `ENABLE_TEST_NET_DCL=true` the flow runs all the
way through BLE, PASE and attestation and then dies with:

```
Commission failed: PAA not found in trust store for authority key identifier ...
```

The server downloads the test PAA roots either way; the flag is what makes it
*trust* them. Confirm it took effect — the log should show a much larger trust
store on boot (179 certificates rather than 74).

### 2. A working BLE proxy, and only one

The server accepts **exactly one** `/ble` client, and Home Assistant takes it
automatically whenever its Matter integration is enabled. On 1.4.0 that is all
you need — leave HA's Matter integration on and do nothing else.

Confirm the proxy is attached:

```
BleProxyConnection   [ble0] BLE proxy handshake complete (version 1)
```

That is the *proxy protocol* handshake between the server and the client. It is
not the BTP handshake with the device, and it is not evidence that the device
will commission.

On releases before v0.8.0 this needed a separate Node/noble pod, because HA's
bleak/BlueZ client dropped the device's BTP handshake response
(matter-js/matterjs-server#1006 — `ProxyBleChannel.openChannel` awaited the
`write_and_subscribe` command before registering the binary-frame observer, so
on BlueZ the indication arrived with no listener attached). `ble-proxy-pod.yaml`
in this directory is kept only for that case.

The proxy runs on the node with the Bluetooth adapter, so **the device must be
within BLE range of that node**, not of the border router.

One live defect remains, and it costs throughput rather than blocking: bleak
reports the ATT MTU as 23, so BTP fragments are capped at 20 bytes instead of
244. The server logs it plainly:

```
ProxyBleChannel  Connected to <addr>, handle=1, BTP segment size=20 bytes (peripheral ATT_MTU up to 23)
```

### 3. BLE and Thread must both reach the device at the same time

`connectNetwork` has to succeed inside the fail-safe window, so the device needs
the Bluetooth host *and* a live Thread router in range simultaneously. One
border router in a basement does not cover an upstairs room; a sensor that
commissions fine next to the ZBT-2 will not hold the mesh where it actually
lives. See [field-notes.md](field-notes.md) section 7.

**Check the border router is actually running first.** An OTBR that has lost its
dataset presents as `state: disabled` with an empty child table, and then every
device looks out of range:

```sh
ot-ctl state          # expect leader/router/child, never disabled
ot-ctl ifconfig       # expect up
ot-ctl dataset active | head    # expect a network name
```

Recovery, and how to restore it, is in [field-notes.md](field-notes.md) §6.

## Procedure

0. **Put the device on USB from the Bluetooth host** (`k8sn1-master`). That
   is power, BLE range and the commissioning-window reset in one plug, and
   the rest of the procedure runs from anywhere on the LAN — one trip to the
   rack. It does not need to be near the border router's node; the ZBT-2 on
   `k8sn3-agent` reaches across the same room.
1. **Get the sensor into its commissioning window.** It is time-limited from
   boot. A device that has never been paired is already advertising; one that
   was un-paired with `remove_node` reboots itself and comes back advertising
   (see Factory reset below). Otherwise power-cycle it.
   **The QR staying on the e-ink is not evidence the window is open** — it is
   drawn once and the panel simply holds the image.
2. Confirm it is advertising. From the Bluetooth host, look for service data
   under UUID `fff6`; the payload encodes discriminator 3840 and VID `0xFFF1`.
3. Confirm HA's BLE proxy is attached (precondition 2). Nothing to start.
4. Drive commissioning against the server's WebSocket API — **not** the HA UI,
   which gates Matter commissioning behind the mobile companion app:

   ```json
   {"message_id":"1","command":"commission_with_code",
    "args":{"code":"34970112332","network_only":false}}
   ```

   on `ws://<matter-server-host>:5580/ws`. Expect 18-19 seconds.

## Verify

```sh
ot-ctl child table          # the device should appear as a child, age near 0
```

and read attributes over Thread. `read_attribute` is **not** a command this
server implements — it is silently dropped, with no error and no log line. Use
`get_nodes` and read from the returned `attributes` map:
`1/1026/0` temperature (centi-°C), `2/1029/0` humidity (centi-%RH),
`3/47/11` battery millivolts.

Identity should read `homecadia` / `sensor-01` / `xiao-c6/driver-v2`
(`0/40/1`, `0/40/3`, `0/40/8`). If it reads `TEST_VENDOR` / `TEST_PRODUCT`, the
device was commissioned before `main/chip_project_config.h` existed — see
**Device identity is fixed at commissioning time** below.

If temperature and humidity read null while battery reads fine, that is the
esp-matter defect in [field-notes.md](field-notes.md) §9 — the fix is in
`sensor_loop.cpp`; do not go looking for a wiring fault.

## Pairing codes

Until per-device factory partitions are generated (`esp-matter-mfg-tool`, open
work item), all units use the compiled-in Matter **test credentials**: passcode
20202021, discriminator 3840, manual pairing code **34970112332**. The serial
console and the e-ink QR are authoritative if this ever disagrees. Consequence
of shared codes: only put **one** uncommissioned unit in pairing mode at a time.

These are Espressif's public test credentials, not secrets. Real per-device
codes, once generated, must **not** be committed — this repo is public.

## Factory reset / re-commissioning

**Preferred: `remove_node`.** As of `7895168` the device handles the rest itself:

```json
{"message_id":"1","command":"remove_node","args":{"node_id":<id>}}
```

The server sends `removeFabric`, the device reboots 3 seconds later, and it
comes back advertising over BLE with no physical access. Verified 2026-08-24.
This also clears the server-side node, so there is no ghost to tidy up.

Before that fix the device went **silent** after `remove_node` and needed a
power cycle. Two causes, both real:

- `kFabricRemoved` reopened the window with `kDnssdOnly`, advertising over
  DNS-SD on a network the device had just left.
- With `CONFIG_USE_BLE_ONLY_FOR_COMMISSIONING=y` the stack tears BLE down after
  commissioning and hands its RAM back to the heap
  (`BLEManagerImpl::DeinitESPBleLayer` → `ClaimBLEMemory`), so **no**
  advertisement mode could have worked. Hence the reboot.

**Fallback: erase NVS over USB.** Needed if the device is unreachable, or to
wipe user settings as well as the fabric:

```sh
esptool --chip esp32c6 -p <port> --before default_reset --after hard_reset \
        erase_region 0x10000 0xC000      # nvs, per partitions.csv
```

This is only possible from a host whose kernel will drive the C6's native USB
control lines. On the k3s nodes here it fails at `pyserial`'s `open()` with
`OSError: [Errno 71] Protocol error` on the `TIOCMBIC/TIOCM_RTS` ioctl, on both
esptool 4.7.0 and 5.3.1 — the reset sequence *is* DTR/RTS, so there is nothing
to route around. Flash and erase from the bench over usbipd instead.

**A plain reflash does not decommission.** The fabric lives in NVS and survives
`write_flash`, so firmware can be iterated without re-pairing — verified.

## Device identity is fixed at commissioning time

`VendorName`, `ProductName` and `HardwareVersionString` come from
`main/chip_project_config.h` at compile time (`CONFIG_CHIP_PROJECT_CONFIG`;
`CONFIG_ENABLE_ESP32_FACTORY_DATA_PROVIDER` is **not** set, so nothing is read
from the `fctry` partition).

The controller caches BasicInformation from the commissioning interview and does
not refresh it. **A reflash alone does not change what the controller shows** —
verified 2026-08-24: after flashing the corrected strings the device still
appeared as `TEST_VENDOR` / `TEST_PRODUCT`, and only read `homecadia` /
`sensor-01` after a decommission and re-commission.

Forcing it with `interview_node` does not work either. A complete read against a
sleepy end device on a 5-second poll exceeds the interview budget:

```
Controller~ndHandler  Interview requested for node @1:16 - do a complete read
WebSocketC~erHandler  [a] WebSocket error response (interview_node) 1 [aborted] Operation aborted
    at abort.timeoutHandler (@matter/protocol/src/peer/Peer.ts:447:27)
```

**Get identity right before commissioning the remaining units**, or plan to
decommission and re-commission each one.

Per-unit naming does *not* belong here — all three units share a model. Use
**NodeLabel**, set by the controller.

## Expected warning: uncertified vendor ID

The firmware uses Espressif's **test vendor ID 65521 (0xFFF1)**. It is not
Matter-certified, so controllers show an "uncertified device" warning. Accept
it — for a self-built device on a self-hosted controller this is the normal,
supported path.

## Apple Home: not available here

Apple's Matter commissioning requires an **Apple** Thread border router —
HomePod mini, HomePod (2nd gen), or a Thread-capable Apple TV 4K. Confirmed
2026-08-23 that neither Apple TV in this house qualifies: `AppleTV5,3` is an
Apple TV HD with no 802.15.4 radio, and `AppleTV6,2` is the 2017 Apple TV 4K,
which predates Thread (it arrived with the 2021 2nd gen). The iPhone reports
"Thread Border Router Required" and stops before any BLE traffic.

This also blocks the iOS companion-app route, since it hands Matter
commissioning to Apple's MatterSupport framework — which is why the API path
above exists.

## Troubleshooting

Symptoms actually seen during milestone 2, with what each one meant:

| Symptom | Cause |
|---|---|
| `PAA not found in trust store` | `ENABLE_TEST_NET_DCL` not set |
| `Only one BLE proxy client allowed` | HA holds the `/ble` slot, or an orphaned client does |
| `BTP handshake response not received` | matter-server older than v0.8.0 — upgrade, do not chase it |
| `No commissionable device was discovered` | window closed, or out of BLE range of the Bluetooth host. Confirm with `btmon` before assuming range: look for `Service Data: Matter Profile ID (0xfff6)` |
| Device silent after `remove_node` | firmware older than `7895168`; power-cycle it |
| Controller shows `TEST_VENDOR` after a reflash | cached interview — see **Device identity is fixed at commissioning time** |
| Reaches `connectNetwork`, then CASE fails | device out of Thread range, or the OTBR is not running |
| iOS companion app: `Thread network credentials does not match with any of the active thread networks around`, then `Home couldn't connect to this accessory` at "Setting Up…" | the app handed off to Apple's MatterSupport sheet (see **Apple Home: not available here**). Nothing reaches the Matter server — its log stays empty. Seen 2026-09-12 from the 2nd floor; use the API path instead |
| Commissions, then goes unavailable | sleepy ICD — normal between polls; if permanent, check the child table |
| Temperature/humidity null, battery fine | esp-matter defect, [field-notes.md](field-notes.md) §9 |

## Upstream status

| Issue | State |
|---|---|
| matter-js/matterjs-server#1006 | **resolved** — fixed in #710, released v0.8.0. Retested on 1.4.0 2026-08-24; HA's own proxy commissions in 18.8s. The noble pod and disable/enable dance are gone from this document. |
| matter-js/matterjs-server#1003 | open — consolidates the `write_and_subscribe` gap and the connect race from our #1005. Only affects the noble client, which is no longer on the critical path. |
| ATT MTU reported as 23 | open, being split out of #1006. Throughput only: 20-byte BTP fragments instead of 244. Upstream's fix is `char.max_write_without_response_size + 3`, which reads the cached D-Bus property (`bleak/backends/bluezdbus/manager.py:162`) and does **not** go through the `_acquire_mtu()`/`AcquireWrite` path that Matter's characteristics cannot satisfy. |
| espressif/esp-matter#1798 | open — `attribute::update()` routing to code-driven clusters would let `sensor_loop.cpp` drop its registry workaround. |

Re-test this procedure after any of them, and simplify it here.

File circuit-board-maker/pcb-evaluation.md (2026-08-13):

# Custom PCB evaluation — sensor-01

Should the hand-wired sensor-01 build be replaced by a custom PCB?

**Conclusion: not for three units.** Build a through-hole harness board that
fixes three of the six pain points for ~CAD 40, hand-wire the three units, and
measure the assembled device before letting any power argument justify a board
spin. Reasoning below.

Written 2026-08-13, against the build state in [docs/bom.md](../docs/bom.md),
[docs/pinmap.md](../docs/pinmap.md), and
[docs/power-budget.md](../docs/power-budget.md).

## Provenance markers

Every number below carries its source, because several of them are the
difference between a good and a bad decision:

| Marker | Meaning |
|---|---|
| **[DS]** | Read directly from the linked datasheet in preparing this doc |
| **[SEARCH]** | From a search-result summary of a datasheet, not read first-hand |
| **[UNVERIFIED]** | Recall or estimate. Treat as a starting point, not a fact |

Every URL in this document was checked and returns HTTP 200 as of 2026-08-13.

---

## Three premises that were wrong

### 1. "Quiescent current is the number that decides the design." It isn't.

[docs/power-budget.md](../docs/power-budget.md) models a sleep floor of
15–40 µA, divider bleed of 2.1 µA, and Thread ICD poll contribution of
10–30 µA. That is **27–72 µA against a 300 µA budget** — 230 µA of headroom.

A MAX17048 fuel gauge draws 3 µA, or 1% of budget. An MCP73831 charger leaks
under 2 µA, or 0.7%. Ten such parts could be added before it matters.

The real risk is the two terms that have never been measured: the C6's actual
sleep floor with esp-matter LIT ICD running, and the ePaper refresh charge.
**Neither is affected by any PCB decision.** [docs/bringup.md](../docs/bringup.md)
already tracks both; the measured column is empty.

The quiescent-current analysis below is real, but it is arithmetic on a rounding
error. Measure first.

### 2. Pain point 5 (SHT40 mounting) — a PCB makes this worse

[docs/bom.md](../docs/bom.md) already records the constraint: *"SHT40 sits in
the case airflow path, external to MCU heat — self-heating skews readings."*
Putting the sensor on the main board seats it beside the C6 module, the LDO, and
a 20 V booster inductor. That is the opposite of the requirement.

Correct fix: a case revision with a vented sensor pocket, or a ~10 × 10 mm
satellite board on a 4-wire cable. Both are enclosure work. Neither needs a
main-board redesign.

### 3. Pain point 4 (driver-board JST doesn't charge) is already solved

Solved by soldering the cell to the XIAO's BAT pads. It costs nothing at
runtime. It is a documentation problem, not a hardware one, and it is not a PCB
justification.

### Scorecard on the six pain points

| # | Pain point | Verdict |
|---|---|---|
| 1 | Battery divider has no home in the enclosure | **Real, cheap to fix** |
| 2 | No fuel gauge, battery % is an ADC guess | Marginal — divider + OCV LUT is adequate for hourly reporting |
| 3 | USB-C pigtail has no CC resistors, A-to-C only | **Real — needs a connector swap or a board-mount receptacle, see correction below** |
| 4 | Driver-board JST doesn't charge | Already solved |
| 5 | SHT40 hangs on a pigtail | Not a PCB problem — enclosure work |
| 6 | ~12 wires per unit × 3 | **Real, moderately fixed by a board** |

---

## The thing that shapes every option: where the e-ink driver lives

The **SSD1680 is not a part you place.** §14 of the
[SSD1680 datasheet Rev 0.14](https://www.crystalfontz.com/controllers/uploaded/SSD1680.pdf)
gives *die tray dimensions* for SSD1680Z / SSD1680Z8 — it ships as bare die,
chip-on-glass bonded to the panel's own flex. The panel already has it.

What the Seeed driver board provides is the **booster network** that makes the
on-chip charge pump work. From §13, Table 13-1 **[DS]**:

| Part | Value | Datasheet requirement |
|---|---|---|
| L1 | **47 µH** | CDRH2D18 / LDNP-470NC, Io = 500 mA max |
| Q1 | NMOS | Si1304BDL / NX3008NBK; BVdss ≥ 30 V, Vgs(th) 0.9 V typ / 1.3 V max, Rds(on) ≤ 2.1 Ω @ Vgs = 2.5 V |
| D1–D3 | Schottky | MBR0530; Vr ≥ 30 V, Io ≥ 500 mA, Vf ≤ 430 mV |
| R1 | 2.2 Ω | 0402–0805, 1%, ≥ 0.05 W |
| C0–C1 | 1 µF | X5R/X7R, 6 V or 25 V |
| C2–C7 | 1 µF | 0402/0603/0805, X5R/X7R, **25 V** |
| C8 | 0.47–1 µF | 0603/0805, X7R, 25 V; effective C > 0.25 µF @ 18 V DC bias |
| U1 | — | 24-pin, **0.5 mm pitch ZIF socket** |

§6.3 and §1.2 **[DS]**: VGH is 10–20 V, VGL = −VGH, **max 40 Vp-p** gate swing.
The absolute-max table gives VGH operating 19.5 / 20 / 20.5 V.

Table 13-1 also carries Solomon Systech's own caveat: *"The recommended component
value and reference part is subject to change depending on panel loading.
Customer is required to review if the selected component value and part is
suitable for their application."* — i.e. these values are a starting point for
a panel that is not necessarily ours.

**Consequence: any option that drops the Seeed driver board — the carrier board
*or* the integrated board — requires laying out a 47 µH switching booster
generating ±20 V, with a hard-switching node, seated within a few millimetres of
a 0.5 mm-pitch flex connector, on the same board as a 2.4 GHz radio.**

That is the difficulty of this project. It is not the ESP32 part, and it is
identical in both options. Any framing where the carrier board is "the easy one"
is wrong unless it also keeps the driver board — which is what Option 0 does.

---

## Option 0 — Passive harness board (recommended)

Keeps the XIAO and the Seeed driver board exactly as they are.

### Block diagram

```
[USB-C panel pigtail] -> 2-pin -> CC1/CC2 5.1k to GND -> VBUS/GND -> XIAO USB pads
[LiPo] -> JST-PH 2.0, polarity-keyed -> XIAO BAT pads
       \-> 1M/1M divider + 100nF -> header pin -> GPIO5
[EC11 encoder] -> through-hole footprint ON this board -> 3 header pins
[3mm LED] -> through-hole + series R -> 1 header pin
[SHT40] -> 4-pin JST-SH -> satellite, still on a cable
[2x7 female headers] <- XIAO plugs in
```

Fixes **1** (divider gets a home with mounting holes), **3**, **6** (encoder,
LED and divider wiring become zero flying wires; the 8 SPI wires stay, since the
driver board stays).
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

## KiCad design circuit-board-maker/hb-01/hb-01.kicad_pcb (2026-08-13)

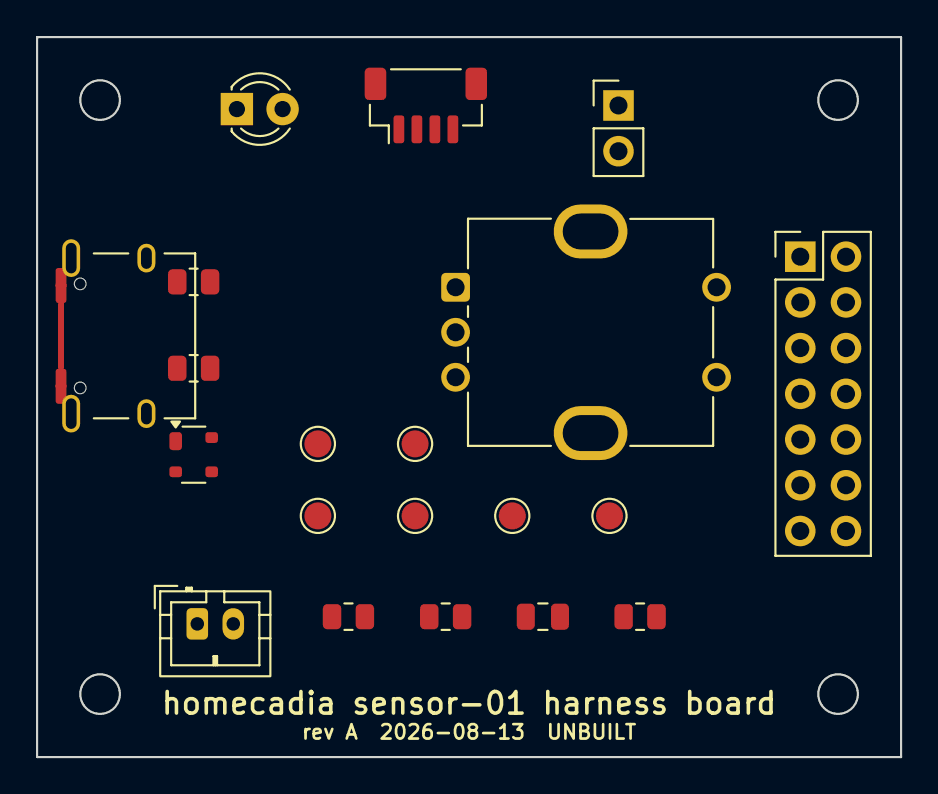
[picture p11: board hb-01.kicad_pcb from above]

Board: 2 copper layers, 48.0 x 40.0 mm, 24 parts (0 on the bottom side), 16 nets, no tracks yet.

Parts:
C1: 100nF; C_0805_2012Metric
D1: SP0503BAHTG; SOT-143
D2: LED 3mm; LED_D3.0mm
H1, H2, H3, H4: M2; MountingHole_2.2mm_M2
J1: USB-C 16P; USB_C_Receptacle_XKB_U262-16XN-4BVC11
J2: XIAO field 2x7; PinHeader_2x07_P2.54mm_Vertical
J3: BAT JST-PH; JST_PH_B2B-PH-K_1x02_P2.00mm_Vertical
J4: SHT40 JST-SH; JST_SH_BM04B-SRSS-TB_1x04-1MP_P1.00mm_Vertical
J5: 5V out; PinHeader_1x02_P2.54mm_Vertical
R1, R2: 5.1k; R_0805_2012Metric
R3, R4: 1M 1%; R_0805_2012Metric
R5: 1k; R_0805_2012Metric
SW1: PEC11R-4220F-S0024; RotaryEncoder_Bourns_Vertical_PEC12R-3x17F-Sxxxx
TP1: VBAT; TestPoint_Pad_D1.5mm
TP2: VDIV; TestPoint_Pad_D1.5mm
TP3: GND; TestPoint_Pad_D1.5mm
TP4: 3V3; TestPoint_Pad_D1.5mm
TP5: USB_DP; TestPoint_Pad_D1.5mm
TP6: USB_DM; TestPoint_Pad_D1.5mm

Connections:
+3V3: J2.12, J4.1, TP4.1
CC1: J1.A5, R1.1
CC2: J1.B5, R2.1
ENC_A: J2.8, SW1.A
ENC_B: J2.10, SW1.B
ENC_SW: J2.14, SW1.S1
GND: C1.2, D1.2, D2.1, J1.A1, J1.A12, J1.B1, J1.B12, J2.1, J3.2, J4.4, J5.2, R1.2, R2.2, R4.2, SW1.C, SW1.S2, TP3.1
LED_A: J2.7, R5.1
LED_K: D2.2, R5.2
SCL: J2.6, J4.2
SDA: J2.5, J4.3
USB_DM: J1.A7, J1.B7, TP6.1
USB_DP: D1.1, J1.A6, J1.B6, TP5.1
VBAT: J3.1, R3.1, TP1.1
VBUS: D1.3, J1.A4, J1.A9, J1.B4, J1.B9, J5.1
VDIV: C1.1, J2.13, R3.2, R4.1, TP2.1

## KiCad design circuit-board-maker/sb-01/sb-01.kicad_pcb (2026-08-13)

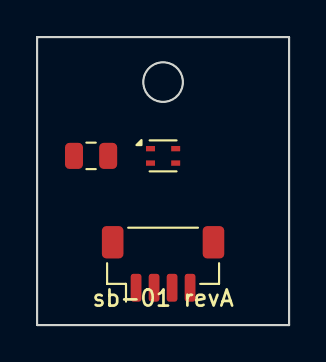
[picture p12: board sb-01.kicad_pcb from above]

Board: 2 copper layers, 14.0 x 16.0 mm, 4 parts (0 on the bottom side), 4 nets, no tracks yet.

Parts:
C1: 100nF; C_0805_2012Metric
H1: M2; MountingHole_2.2mm_M2
J1: JST-SH 4P; JST_SH_BM04B-SRSS-TB_1x04-1MP_P1.00mm_Vertical
U1: SHT40-AD1B-R2; Sensirion_DFN-4_1.5x1.5mm_P0.8mm_SHT4x_NoCentralPad

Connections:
+3V3: C1.1, J1.1, U1.1
GND: C1.2, J1.4, U1.3
SCL: J1.2, U1.2
SDA: J1.3, U1.4

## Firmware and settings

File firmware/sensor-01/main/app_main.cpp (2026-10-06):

/* homecadia sensor-01 — Matter-over-Thread temperature/humidity sensor.
 *
 * Endpoints: temperature sensor, humidity sensor, power source (battery).
 * SHT40 polled every SENSOR_POLL_INTERVAL_S; attributes update on delta
 * (sensor_loop.cpp). Structure follows the esp-matter icd_app example (v1.6).
 */

#include <driver/gpio.h>
#include <esp_err.h>
#include <esp_log.h>
#include <esp_system.h>
#include <esp_timer.h>
#include <nvs_flash.h>
#if CONFIG_PM_ENABLE
#include <esp_pm.h>
#include "sleep_diag.h"
#endif
#include <esp_attr.h>
#include <esp_rom_sys.h>
#include <esp_sleep.h>
#include <freertos/FreeRTOS.h>
#include <freertos/task.h>

#include <esp_matter.h>
#include <esp_matter_ota.h>

#include <common_macros.h>
#include <app_config.h>
#include <battery.h>
#include <bench_selftest.h>
#include <display.h>
#include <led.h>
#include <sensor_loop.h>
#include <settings.h>
#include <ui.h>

#include <setup_payload/OnboardingCodesUtil.h>
#include <setup_payload/QRCodeSetupPayloadGenerator.h>
#include <setup_payload/SetupPayload.h>
#if CHIP_DEVICE_CONFIG_ENABLE_THREAD
#include <esp_openthread_types.h>
#include <platform/ESP32/OpenthreadLauncher.h>
#endif

#include <app/server/CommissioningWindowManager.h>
#include <app/server/Server.h>

static const char *TAG = "sensor-01";

using namespace esp_matter;
using namespace esp_matter::attribute;
using namespace esp_matter::endpoint;

constexpr auto k_commissioning_window_timeout = chip::System::Clock::Seconds16(300);
constexpr int k_decommission_reboot_delay_s = 3;
#if CONFIG_HOMECADIA_UNPAIRED_DEEP_SLEEP
constexpr auto k_unpaired_check_delay = chip::System::Clock::Seconds16(30);
/* Past this much uptime an unpaired unit sleeps even if the window still
 * reads as open: after a failed pairing the SDK re-opens the window for a
 * retry with no timeout of its own (CommissioningWindowManager::
 * HandleFailedAttempt), and on 2026-10-02 that kept a unit awake at 67 mA
 * past the 15-minute window. One minute over the SDK's 15-minute window. */
constexpr int64_t k_unpaired_awake_cap_us = (int64_t)(CHIP_DEVICE_CONFIG_DISCOVERY_TIMEOUT_SECS + 60) * 1000000;
constexpr uint32_t k_asleep_screen_timeout_ms = 8000; /* full refresh is ~1.8 s */
#endif

#if CHIP_DEVICE_CONFIG_ENABLE_THREAD
#define ESP_OPENTHREAD_DEFAULT_RADIO_CONFIG() \
    {                                         \
        .radio_mode = RADIO_MODE_NATIVE,      \
    }

#define ESP_OPENTHREAD_DEFAULT_HOST_CONFIG()               \
    {                                                      \
        .host_connection_mode = HOST_CONNECTION_MODE_NONE, \
    }

#define ESP_OPENTHREAD_DEFAULT_PORT_CONFIG()                                            \
    {                                                                                   \
        .storage_partition_name = "nvs", .netif_queue_size = 10, .task_queue_size = 10, \
    }
#endif

/* Renders the commissioning QR + manual code on the e-ink (they also go to
 * the serial console via the stack's own PrintOnboardingCodes). With asleep
 * set, adds the "turn the dial" line and returns once it is on the panel. */
static void show_commissioning_screen(bool asleep = false)
{
    char qr[chip::QRCodeBasicSetupPayloadGenerator::kMaxQRCodeBase38RepresentationLength + 1];
    char manual[chip::kManualSetupLongCodeCharLength + 1];
    chip::MutableCharSpan qr_span(qr);
    chip::MutableCharSpan manual_span(manual);
    if (GetQRCode(qr_span, chip::RendezvousInformationFlags(chip::RendezvousInformationFlag::kBLE)) != CHIP_NO_ERROR ||
        GetManualPairingCode(manual_span, chip::RendezvousInformationFlags(chip::RendezvousInformationFlag::kBLE)) !=
            CHIP_NO_ERROR) {
        ESP_LOGE(TAG, "Failed to get onboarding codes");
        return;
    }
    qr[qr_span.size()] = '\0';
    manual[manual_span.size()] = '\0';
#if CONFIG_HOMECADIA_UNPAIRED_DEEP_SLEEP
    if (asleep) {
        esp_err_t err = display_show_pairing_asleep(qr, manual, k_asleep_screen_timeout_ms);
        if (err != ESP_OK) {
            ESP_LOGW(TAG, "Asleep screen not confirmed: %s", esp_err_to_name(err));
        }
        return;
    }
#else
    (void)asleep;
#endif
    display_show_commissioning(qr, manual);
}

#if CONFIG_HOMECADIA_UNPAIRED_DEEP_SLEEP
/* An unpaired unit never light-sleeps: ESP-IDF's OpenThread port holds its
 * "ot_sleep" PM lock until the 802.15.4 radio reports the sleep state
 * (esp_openthread_sleep.c), which needs a Thread network. Measured 28 mA
 * (field-notes.md section 26). So once the commissioning window has closed
 * with no fabric, the unit deep-sleeps and a turn of the dial (encoder A, an
 * LP GPIO) brings it back with a new window.
 *
 * Restart first, sleep second. The running system draws the "asleep" screen
 * and restarts with a request flag set; the next boot enters deep sleep from
 * the top of app_main(), before Bluetooth, Thread, the PHY or power
 * management exist. Entering deep sleep from the running system worked on USB
 * and stuck at ~20 mA on battery (bringup.md, 2026-10-01), and the IDF docs
 * require the radios to be stopped before deep sleep (sleep_modes.rst). */
#define WAKE_INFO_MAGIC 0x57414B45u  /* "WAKE": the RTC block below holds data, not power-on noise */
#define SLEEP_REQUEST_MAGIC 0x534C5050u /* "SLPP": the restart was asked for by unpaired_sleep_check() */
static RTC_NOINIT_ATTR uint32_t s_wake_magic;
static RTC_NOINIT_ATTR uint32_t s_wake_count;
static RTC_NOINIT_ATTR uint32_t s_wake_cause;
static RTC_NOINIT_ATTR uint32_t s_sleep_request;
#define EMPTY_DRAWN_MAGIC 0x454D5054u /* "EMPT": the battery-empty screen is already on the panel */
static RTC_NOINIT_ATTR uint32_t s_empty_drawn;

/* The wake pin keeps a pull-up through deep sleep and wakes on the level it
 * is not at, as in ec11.c arm_wake(). CONFIG_PM_SLP_DISABLE_GPIO has already
 * set every pin to switch to an isolated, floating state in sleep
 * (esp_sleep_startup_init, sleep_gpio.c); left on, the wake pin floated and
 * the unit woke by itself within seconds. With timer_s > 0 a timer wakes it
 * too. Never returns, except when the dial wake cannot be armed. */
static void enter_deep_sleep(uint32_t timer_s = 0)
{
#if CONFIG_PM_SLP_DISABLE_GPIO
    gpio_sleep_sel_dis((gpio_num_t)ENC_PIN_A);
#endif
    gpio_config_t io = {};
    io.pin_bit_mask = 1ULL << ENC_PIN_A;
    io.mode = GPIO_MODE_INPUT;
    io.pull_up_en = GPIO_PULLUP_ENABLE;
    gpio_config(&io);
    esp_rom_delay_us(100); /* let the pull-up settle before reading the rest level */
    esp_deepsleep_gpio_wake_up_mode_t mode =
        gpio_get_level((gpio_num_t)ENC_PIN_A) ? ESP_GPIO_WAKEUP_GPIO_LOW : ESP_GPIO_WAKEUP_GPIO_HIGH;
    esp_err_t err = esp_deep_sleep_enable_gpio_wakeup(BIT64(ENC_PIN_A), mode);
    if (err != ESP_OK) {
        /* Without a wake source deep sleep would need a power cycle to leave:
         * boot normally instead and stay awake. */
        ESP_LOGE(TAG, "Deep-sleep wake on GPIO%d failed (%s): staying awake", ENC_PIN_A, esp_err_to_name(err));
        return;
    }
    if (timer_s > 0) {
        esp_sleep_enable_timer_wakeup((uint64_t)timer_s * 1000000);
    }
    esp_deep_sleep_start();
}

/* First thing in app_main(). */
static void unpaired_sleep_on_boot(void)
{
    if (s_wake_magic != WAKE_INFO_MAGIC) {
        s_wake_magic = WAKE_INFO_MAGIC;
        s_wake_count = 0;
        s_wake_cause = 0;
        s_sleep_request = 0;
        s_empty_drawn = 0;
    }
    esp_reset_reason_t reason = esp_reset_reason();
    if (reason == ESP_RST_DEEPSLEEP) {
        /* Woken by the dial (or the empty-battery recheck timer). This boot inherits the wake pin's pad hold and
         * LP wake setting, and on 2026-09-30 such a boot hung in the GPIO
         * interrupt setup at ~20 mA. Undo both and restart cleanly. */
        s_wake_count++;
        s_wake_cause = (uint32_t)esp_sleep_get_wakeup_cause();
        gpio_hold_dis((gpio_num_t)ENC_PIN_A);
        gpio_deep_sleep_wakeup_disable((gpio_num_t)ENC_PIN_A);
        esp_restart();
    }
    bool requested = s_sleep_request == SLEEP_REQUEST_MAGIC;
    s_sleep_request = 0; /* one shot: whatever happens next, the following boot is a normal one */
    if (requested && reason == ESP_RST_SW) {
        ESP_LOGW(TAG, "Unpaired: entering deep sleep from early boot; turn the dial to wake");
        enter_deep_sleep();
    }
}

#if CONFIG_HOMECADIA_EMPTY_BATTERY_SLEEP
/* Second thing in app_main(), still before Bluetooth, Thread and the PHY. At
 * brown-out the unit restarted about once a second, starting the radio and
 * redrawing the panel each time (2026-10-05, 2900 mV on the PPK2): the worst
 * load for a cell at its protection cutoff. An empty reading instead draws one
 * "battery empty" screen and deep-sleeps; the dial or an hourly timer wakes it,
 * and the wake path above restarts into this check again. The screen is drawn
 * once per empty spell (s_empty_drawn), so a cell too weak for even the panel
 * refresh does not restart in a loop on that instead. Whether RTC_NOINIT
 * survives a brown-out reset is unverified; if it does not, the cost is one
 * redraw attempt per boot, with the radio still off.
 *
 * Draw, restart, then sleep -- the unpaired path's order. Sleeping straight
 * after the refresh, with the panel's SPI bus and pins configured, sat at
 * 292 uA (2026-10-06, capture ppk2-20261006T030820) against 19.7 uA for the
 * unpaired sleep, which enters before the display exists. Once a spell has
 * begun, resuming needs EMPTY_BATTERY_BROWNOUT_MV: hysteresis, so a cell that
 * reads 3100-3300 mV after a brown-out stays asleep instead of cycling. */
static void empty_battery_on_boot(void)
{
    if (battery_init() != ESP_OK) {
        return;
    }
    uint32_t mv = 0;
    if (battery_read_mv(&mv) != ESP_OK || mv < EMPTY_BATTERY_NO_READING_MV) {
        return; /* no divider reading (USB only, or no divider fitted): nothing to judge */
    }
    bool brownout = esp_reset_reason() == ESP_RST_BROWNOUT;
    bool in_spell = s_empty_drawn == EMPTY_DRAWN_MAGIC;
    uint32_t limit = (brownout || in_spell) ? EMPTY_BATTERY_BROWNOUT_MV : EMPTY_BATTERY_MV;
    if (mv >= limit) {
        s_empty_drawn = 0; /* charged or replaced: the next empty spell draws its screen again */
        return;
    }
    ESP_LOGW(TAG, "Battery empty: %lu mV (limit %lu%s); deep sleep, recheck in %d s", (unsigned long)mv,
             (unsigned long)limit, brownout ? ", after a brown-out" : "", EMPTY_BATTERY_RECHECK_S);
    if (!in_spell) {
        s_empty_drawn = EMPTY_DRAWN_MAGIC; /* set before the refresh: a brown-out mid-refresh must not retry it */
        if (display_init() == ESP_OK) {
            esp_err_t err = display_show_battery_empty(mv, k_asleep_screen_timeout_ms);
            if (err != ESP_OK) {
                ESP_LOGW(TAG, "Battery-empty screen not confirmed: %s", esp_err_to_name(err));
            }
        }
        esp_restart(); /* the next boot finds the flag and sleeps before any driver exists */
    }
    enter_deep_sleep(EMPTY_BATTERY_RECHECK_S);
}
#else
static void empty_battery_on_boot(void) {}
#endif

static void unpaired_sleep_check(chip::System::Layer *layer, void *);

static void schedule_unpaired_sleep_check(void)
{
    chip::DeviceLayer::SystemLayer().CancelTimer(unpaired_sleep_check, nullptr); /* one pending check at a time */
    CHIP_ERROR err =
        chip::DeviceLayer::SystemLayer().StartTimer(k_unpaired_check_delay, unpaired_sleep_check, nullptr);
    if (err != CHIP_NO_ERROR) {
        ESP_LOGE(TAG, "Unpaired sleep check not scheduled: %" CHIP_ERROR_FORMAT, err.Format());
    }
}

static void unpaired_sleep_check(chip::System::Layer *, void *forced)
{
    chip::Server &server = chip::Server::GetInstance();
    if (server.GetFabricTable().FabricCount() != 0) {
        return;
    }
    /* A commissioner mid-way holds the fail-safe; never cut that off (the SDK
     * caps a fail-safe at 15 min). An open window holds the unit only until
     * the uptime cap. */
    bool pairing_in_progress = server.GetFailSafeContext().IsFailSafeArmed();
    bool window_open = server.GetCommissioningWindowManager().IsCommissioningWindowOpen();
    bool over_cap = esp_timer_get_time() > k_unpaired_awake_cap_us;
    if (!forced && (pairing_in_progress || (window_open && !over_cap))) {
        schedule_unpaired_sleep_check();
        return;
    }
    ESP_LOGW(TAG, "Unpaired and the commissioning window is closed: restarting into deep sleep");
    show_commissioning_screen(true); /* the panel keeps this image through the sleep */
    s_sleep_request = SLEEP_REQUEST_MAGIC;
    esp_restart();
}
#else
static void schedule_unpaired_sleep_check(void) {} /* feature off (bench profile: the console needs USB) */
static void unpaired_sleep_on_boot(void) {}
static void empty_battery_on_boot(void) {}
#endif
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
extern "C" void app_main()
{
#if CONFIG_HOMECADIA_UNPAIRED_SLEEP_TEST_S > 0
    vTaskDelay(pdMS_TO_TICKS(3000)); /* let a re-enumerating USB console catch the boot */
#endif
    unpaired_sleep_on_boot();
    empty_battery_on_boot();
#if CONFIG_HOMECADIA_UNPAIRED_SLEEP_TEST_S > 0
    {
        char line[26];
        snprintf(line, sizeof(line), "rst%d wakes%lu cause%lu", (int)esp_reset_reason(), (unsigned long)s_wake_count,
                 (unsigned long)s_wake_cause);
        display_set_debug_line(line);
    }
#endif
    ESP_LOGW(TAG, "boot: reset reason %d, wakeup cause %d", (int)esp_reset_reason(), (int)esp_sleep_get_wakeup_cause());

    /* Before anything claims a pin: a pin a driver owns reports the driver. */
    bench_selftest();
    board_rf_switch_init();

    esp_err_t err = nvs_flash_init();
    if (err == ESP_ERR_NVS_NO_FREE_PAGES || err == ESP_ERR_NVS_NEW_VERSION_FOUND) {
        ESP_ERROR_CHECK(nvs_flash_erase());
        err = nvs_flash_init();
    }
    ESP_ERROR_CHECK(err);

#if CONFIG_PM_ENABLE
    esp_pm_config_t pm_config = {
        .max_freq_mhz = CONFIG_ESP_DEFAULT_CPU_FREQ_MHZ,
        .min_freq_mhz = CONFIG_ESP_DEFAULT_CPU_FREQ_MHZ,
#if CONFIG_FREERTOS_USE_TICKLESS_IDLE
        .light_sleep_enable = true,
#endif
    };
    err = esp_pm_configure(&pm_config);
    ABORT_APP_ON_FAILURE(err == ESP_OK, ESP_LOGE(TAG, "Failed to configure power management, err:%d", err));
    sleep_diag_init(); /* no-op unless CONFIG_HOMECADIA_SLEEP_DIAG */
#endif

    node::config_t node_config;
    node_t *node = node::create(&node_config, app_attribute_update_cb, app_identification_cb);
    ABORT_APP_ON_FAILURE(node != nullptr, ESP_LOGE(TAG, "Failed to create Matter node"));

    /* Thread diagnostics with all counters (attach attempts, parent changes,
     * MAC retries), so a controller read shows whether the sensor keeps losing
     * its parent. The SDK accepts only none or all four features
     * (thread-network-diagnostics-server/CodegenIntegration.cpp:57). Nothing
     * marks the counters dirty, so they cost no reports; a read (interview)
     * fetches them. */
    {
        cluster_t *tnd = cluster::get(endpoint::get(node, 0), chip::app::Clusters::ThreadNetworkDiagnostics::Id);
        ABORT_APP_ON_FAILURE(tnd != nullptr, ESP_LOGE(TAG, "No Thread diagnostics cluster on the root endpoint"));
        cluster::thread_network_diagnostics::feature::packet_counts::add(tnd);
        cluster::thread_network_diagnostics::feature::error_counts::add(tnd);
        cluster::thread_network_diagnostics::feature::mle_counts::add(tnd);
        cluster::thread_network_diagnostics::feature::mac_counts::add(tnd);
    }

    /* BootReason (0/51/4): the legacy data model creates only its event, so a
     * controller read returned nothing (2026-10-06). The served cluster enables
     * the attribute when it exists in the store (general_diagnostics
     * integration.cpp) and reads esp_reset_reason() through the platform's
     * DiagnosticDataProvider, which maps a brown-out to BrownOutReset. */
    {
        cluster_t *gd = cluster::get(endpoint::get(node, 0), chip::app::Clusters::GeneralDiagnostics::Id);
        ABORT_APP_ON_FAILURE(gd != nullptr, ESP_LOGE(TAG, "No General Diagnostics cluster on the root endpoint"));
        cluster::general_diagnostics::attribute::create_boot_reason(gd, 0);
    }

    /* Temperature sensor endpoint (MeasuredValue in 0.01°C; SHT40 range) */
    endpoint::temperature_sensor::config_t temp_cfg;
    temp_cfg.temperature_measurement.min_measured_value = nullable<int16_t>(-4000);
    temp_cfg.temperature_measurement.max_measured_value = nullable<int16_t>(12500);
    endpoint_t *temp_ep = endpoint::temperature_sensor::create(node, &temp_cfg, ENDPOINT_FLAG_NONE, nullptr);
    ABORT_APP_ON_FAILURE(temp_ep != nullptr, ESP_LOGE(TAG, "Failed to create temperature endpoint"));

    /* Humidity sensor endpoint (MeasuredValue in 0.01 %RH) */
    endpoint::humidity_sensor::config_t hum_cfg;
    hum_cfg.relative_humidity_measurement.min_measured_value = nullable<uint16_t>(0);
    hum_cfg.relative_humidity_measurement.max_measured_value = nullable<uint16_t>(10000);
    endpoint_t *hum_ep = endpoint::humidity_sensor::create(node, &hum_cfg, ENDPOINT_FLAG_NONE, nullptr);
    ABORT_APP_ON_FAILURE(hum_ep != nullptr, ESP_LOGE(TAG, "Failed to create humidity endpoint"));

    /* Power source endpoint, battery feature. BatPercentRemaining and
     * BatVoltage are optional attributes, created explicitly below. */
    endpoint::power_source::config_t ps_cfg;
    ps_cfg.power_source.status =
        chip::to_underlying(chip::app::Clusters::PowerSource::PowerSourceStatusEnum::kActive);
    ps_cfg.power_source.order = 0;
    snprintf(ps_cfg.power_source.description, sizeof(ps_cfg.power_source.description), "2000mAh LiPo");
    ps_cfg.power_source.feature_flags = cluster::power_source::feature::battery::get_id();
    ps_cfg.power_source.features.battery.bat_charge_level =
        chip::to_underlying(chip::app::Clusters::PowerSource::BatChargeLevelEnum::kOk);
    ps_cfg.power_source.features.battery.bat_replaceability =
        chip::to_underlying(chip::app::Clusters::PowerSource::BatReplaceabilityEnum::kUserReplaceable);
    endpoint_t *ps_ep = endpoint::power_source::create(node, &ps_cfg, ENDPOINT_FLAG_NONE, nullptr);
    ABORT_APP_ON_FAILURE(ps_ep != nullptr, ESP_LOGE(TAG, "Failed to create power source endpoint"));

    cluster_t *ps_cluster = cluster::get(ps_ep, chip::app::Clusters::PowerSource::Id);
    ABORT_APP_ON_FAILURE(ps_cluster != nullptr, ESP_LOGE(TAG, "Failed to get power source cluster"));
    cluster::power_source::attribute::create_bat_percent_remaining(
        ps_cluster, nullable<uint8_t>(), nullable<uint8_t>(0), nullable<uint8_t>(200));
    cluster::power_source::attribute::create_bat_voltage(
        ps_cluster, nullable<uint32_t>(), nullable<uint32_t>(0), nullable<uint32_t>(4500));

#if CHIP_DEVICE_CONFIG_ENABLE_THREAD
    esp_openthread_platform_config_t config = {
        .radio_config = ESP_OPENTHREAD_DEFAULT_RADIO_CONFIG(),
        .host_config = ESP_OPENTHREAD_DEFAULT_HOST_CONFIG(),
        .port_config = ESP_OPENTHREAD_DEFAULT_PORT_CONFIG(),
    };
    set_openthread_platform_config(&config);
#endif
    err = settings_init();
    if (err != ESP_OK) {
        ESP_LOGW(TAG, "Settings load failed (%s), using defaults", esp_err_to_name(err));
    }

    err = led_init();
    if (err != ESP_OK) {
        ESP_LOGW(TAG, "LED init failed: %s", esp_err_to_name(err));
    }
    err = display_init();
    if (err != ESP_OK) {
        ESP_LOGE(TAG, "Display init failed: %s — continuing headless", esp_err_to_name(err));
    }
    err = ui_init();
    if (err != ESP_OK) {
        ESP_LOGE(TAG, "UI init failed: %s — continuing without input", esp_err_to_name(err));
    }
    err = esp_matter::start(app_event_cb);
    ABORT_APP_ON_FAILURE(err == ESP_OK, ESP_LOGE(TAG, "Failed to start Matter, err:%d", err));

    /* Not paired to any controller yet: put the onboarding QR on the screen,
     * and start the unpaired-sleep check so the uptime cap holds even if no
     * window or fail-safe event ever arrives. */
    if (chip::Server::GetInstance().GetFabricTable().FabricCount() == 0) {
        show_commissioning_screen();
        chip::DeviceLayer::PlatformMgr().ScheduleWork([](intptr_t) { schedule_unpaired_sleep_check(); });
    }
    sensor_loop_endpoints_t eps = {
        .temperature_endpoint_id = endpoint::get_id(temp_ep),
        .humidity_endpoint_id = endpoint::get_id(hum_ep),
        .power_source_endpoint_id = endpoint::get_id(ps_ep),
    };
    err = sensor_loop_start(&eps);
    if (err != ESP_OK) {
        /* Keep the node up for commissioning/bench tests without the sensor wired. */
        ESP_LOGE(TAG, "Sensor loop not running (%s)", esp_err_to_name(err));
    }
    ESP_LOGI(TAG, "homecadia sensor-01 up (poll %ds, report on ≥%.1f°C / ≥%.0f%%RH delta)",
             SENSOR_POLL_INTERVAL_S, REPORT_DELTA_TEMP_C, REPORT_DELTA_RH_PCT);
#if CONFIG_HOMECADIA_UNPAIRED_SLEEP_TEST_S > 0
    ESP_LOGW(TAG, "TEST BUILD: unpaired sleep forced %ds after boot", CONFIG_HOMECADIA_UNPAIRED_SLEEP_TEST_S);
    chip::DeviceLayer::PlatformMgr().ScheduleWork([](intptr_t) {
        CHIP_ERROR e = chip::DeviceLayer::SystemLayer().StartTimer(
            chip::System::Clock::Seconds16(CONFIG_HOMECADIA_UNPAIRED_SLEEP_TEST_S), unpaired_sleep_check,
            reinterpret_cast<void *>(1));
        if (e != CHIP_NO_ERROR) {
            ESP_LOGE(TAG, "test sleep timer: %" CHIP_ERROR_FORMAT, e.Format());
        }
    });
#endif
}

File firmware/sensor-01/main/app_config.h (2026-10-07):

#pragma once

// Pin map for sensor-01 (XIAO ESP32-C6 + Seeed ePaper Driver Board V2).
// Mirrors docs/pinmap.md — change both together.
// Verification status of each value is tracked in docs/bringup.md.

// e-paper, fixed by driver board routing (Seeed wiki, ePaper Driver Board V2)
#define EPD_PIN_RST        0    // D0 — also the A0 pad; battery ADC must not use it
#define EPD_PIN_CS         1    // D1
#define EPD_PIN_BUSY       2    // D2
#define EPD_PIN_DC         21   // D3
#define EPD_PIN_SCK        19   // D8
#define EPD_PIN_MOSI       18   // D10

// SHT40 on I2C (Grove cable soldered to D4/D5)
#define SHT40_I2C_SDA      22   // D4
#define SHT40_I2C_SCL      23   // D5
#define SHT40_I2C_ADDR     0x44

// EC11 encoder. A/B assignment chosen so that clockwise = +1 = view advances;
// verified on the bench 2026-08-26 (with A on D6 clockwise read -1, so the two
// were swapped here rather than on the board). A moved D9/GPIO20 -> MTCK pad
// 2026-09-23: with CONFIG_PM_POWER_DOWN_PERIPHERAL_IN_LIGHT_SLEEP only LP GPIOs
// (0-7) can wake light sleep (ESP-IDF sleep_modes docs), and a detent always
// changes A. B stays on an HP pin and is decoded in the awake window after.
// The push switch stays on a header pin (D9): turn to wake, then press. A
// press-only wake would need a fifth underside pad (MTDO). XIAO #2 lost
// MTDI, MTDO and MTCK to pad lifts and stays a bench unit (bringup.md).
// Wake on a detent from light sleep verified on battery 2026-09-28 (node 26).
// The 3V3 pad sits beside MTCK: see assembly.md before soldering.
#define ENC_PIN_A          6    // MTCK underside pad (TP6); LP GPIO, light-sleep wake
#define ENC_AWAKE_MS       2000 // chip held out of light sleep after the last detent
#define ENC_PIN_B          16   // D6 -- was D7/GPIO17: on both driver boards D7 sits at
                                //      0V once the SPI bus is up (2026-08-25, unexplained;
                                //      field-notes.md s16). D6's only neighbour is SCL.
#define ENC_PIN_SW         20   // D9 header pin; HP GPIO: registers only within ENC_AWAKE_MS of a turn

// LED (commissioning state + low battery only)
#define LED_PIN            17   // D7 — an output; does not care what its neighbour does

// Battery divider 2x1M + 100nF on MTMS underside pad (NOT A0 — see docs/pinmap.md;
// schematic-verified: no divider is populated on the board). GPIO4 is in Seeed's
// "avoid" list (strapping/JTAG) — see the strapping caveat in docs/pinmap.md.
#define VBAT_ADC_GPIO      4    // MTMS, ADC1_CH4 -- see pinmap.md; GPIO5/MTDI is
                                //   equivalent (both strap only SDIO clock edge, unused here)
#define VBAT_ADC_SETTLE_MS 20   // high-impedance source (500k || 100nF, tau 50 ms): delay after ADC config before read

// XIAO ESP32-C6 board-internal pins (schematic XIAO-ESP32-C6_v1.0_SCH_PDF_24028,
// sheet 4/5). Not on the header. The FM8625H RF switch is powered through
// P-FET Q3 (gate = GPIO3, 10k pull-up => OFF at reset): firmware MUST drive
// GPIO3 low or the radios have no antenna. GPIO14 = VCTL: low selects the
// onboard ceramic antenna (ANT1), high the U.FL (ANT2).
#define RF_SWITCH_POWER_GPIO 3   // drive low to power the RF switch
#define RF_ANT_SELECT_GPIO   14  // low = ceramic antenna
#define ONBOARD_LED_GPIO     15  // yellow LED via 1.5k to 3V3, ACTIVE LOW; C6 strapping
                                 // pin — leave high-Z (LED off), never hold low into sleep

// Measurement / reporting policy (defaults; user-configurable from milestone 4)
#define SENSOR_POLL_INTERVAL_S 120
#define REPORT_DELTA_TEMP_C    0.2f
#define REPORT_DELTA_RH_PCT    1.0f
#define FORCE_REPORT_EVERY_N_POLLS 10  // report even without delta every N polls (staleness guard)

#define LOW_BATTERY_PCT 10             // below this: LED pulse + display warning
#define BATTERY_RISE_REPORT_PCT 5      // a rise this large reports at once (charging, new cell)

// Empty battery (CONFIG_HOMECADIA_EMPTY_BATTERY_SLEEP). Measured 2026-10-05,
// node 28 on the PPK2: runs at 3000 mV, resets about once a second at 2900 mV
// (brown-out level 7, on the 3V3 rail behind the regulator). At boot, below
// EMPTY_BATTERY_MV -- or below EMPTY_BATTERY_BROWNOUT_MV after a brown-out
// reset, for a cell that sags under the radio's peaks -- the unit draws one
// "battery empty" screen and deep-sleeps instead of starting the radio.
#define EMPTY_BATTERY_MV          3100
#define EMPTY_BATTERY_BROWNOUT_MV 3300
#define EMPTY_BATTERY_NO_READING_MV 2000  // below this the divider reads nothing real (no divider, USB only)
#define EMPTY_BATTERY_RECHECK_S   3600    // deep-sleep timer: re-measure hourly (after a USB charge, say)
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

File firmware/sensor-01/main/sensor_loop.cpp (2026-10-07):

#include "sensor_loop.h"

#include <math.h>

#include "esp_log.h"
#include "esp_system.h"
#include "esp_timer.h"

#include <esp_matter.h>
#include <esp_matter_attribute_utils.h>
#include <app-common/zap-generated/ids/Attributes.h>
#include <app-common/zap-generated/ids/Clusters.h>
#include <app/ConcreteClusterPath.h>
#include <app/clusters/relative-humidity-measurement-server/RelativeHumidityMeasurementCluster.h>
#include <app/clusters/temperature-measurement-server/TemperatureMeasurementCluster.h>
#include <data_model_provider/esp_matter_data_model_provider.h>

#include "app_config.h"
#include "battery.h"
#include "display.h"
#include "led.h"
#include "settings.h"
#include "sht40.h"

static const char *TAG = "sensor_loop";

using namespace chip::app::Clusters;
using esp_matter::attribute::update;

static sensor_loop_endpoints_t s_eps;
static sht40_handle_t s_sht40;
static esp_timer_handle_t s_timer;

static sensor_readings_t s_readings;

/* Last values actually reported over Matter (delta reference). */
static float s_reported_temp_c = NAN;
static float s_reported_rh = NAN;
static uint8_t s_reported_bat_pct = 0xFF;
static unsigned s_polls_since_report;

/* esp_matter::attribute::update() returns a code that is easy to discard; a silent
 * failure here is indistinguishable from a healthy device until a controller reads
 * the attribute and gets null. */
static void log_update(const char *what, uint16_t endpoint_id, esp_err_t err)
{
    if (err != ESP_OK) {
        ESP_LOGE(TAG, "attribute update failed for %s on endpoint %u: %s", what,
                 (unsigned)endpoint_id, esp_err_to_name(err));
    }
}

/* MeasuredValue on the measurement clusters must NOT go through attribute::update().
 *
 * esp-matter v1.6 serves TemperatureMeasurement and RelativeHumidityMeasurement from
 * code-driven cluster objects it registers in the data-model provider
 * (data_model_provider/clusters/<cluster>/integration.cpp). Reads hit that object
 * first, and it keeps its own copy of MeasuredValue. attribute::update() writes only
 * esp-matter's attribute store, returns ESP_OK, and nothing forwards the value — so a
 * controller reads null forever while the device logs healthy readings. Espressif's own
 * examples/sensors is affected the same way. Min/Max survive because the object seeds
 * them from the store at startup; MeasuredValue is never seeded.
 *
 * The served value lives on the registered object, so set it there. The cast is safe
 * because esp-matter's integration registers exactly this class for this cluster id.
 * Caller must hold the Matter stack lock. See docs/field-notes.md section 9. */
template <typename ClusterT, typename ValueT>
static void set_measured_value(const char *what, uint16_t endpoint_id, chip::ClusterId cluster_id, ValueT value)
{
    chip::app::ServerClusterInterface *iface = esp_matter::data_model::provider::get_instance().registry().Get(
        chip::app::ConcreteClusterPath(endpoint_id, cluster_id));
    if (!iface) {
        ESP_LOGE(TAG, "%s: no server cluster registered on endpoint %u", what, (unsigned)endpoint_id);
        return;
    }
    CHIP_ERROR err = static_cast<ClusterT *>(iface)->SetMeasuredValue(chip::app::DataModel::MakeNullable(value));
    if (err != CHIP_NO_ERROR) {
        ESP_LOGE(TAG, "%s: SetMeasuredValue failed on endpoint %u: %" CHIP_ERROR_FORMAT, what,
                 (unsigned)endpoint_id, err.Format());
    }
}

static void report_matter(float temp_c, float rh, uint32_t bat_mv, uint8_t bat_pct)
{
    /* Attribute updates must run under the Matter stack lock; this runs in the
     * esp_timer task. One locked section batches all clusters into one wake.
     * With portMAX_DELAY the scoped lock only ever proceeds locked. */
    esp_matter::lock::ScopedChipStackLock stack_lock(portMAX_DELAY);

    set_measured_value<chip::app::Clusters::TemperatureMeasurementCluster>(
        "temperature", s_eps.temperature_endpoint_id, TemperatureMeasurement::Id,
        (int16_t)lroundf(temp_c * 100.0f));
    set_measured_value<chip::app::Clusters::RelativeHumidityMeasurementCluster>(
        "humidity", s_eps.humidity_endpoint_id, RelativeHumidityMeasurement::Id,
        (uint16_t)lroundf(rh * 100.0f));

    /* PowerSource is still served from esp-matter's own attribute store (its upstream
     * implementation is AAI-based, not a registered cluster object), so update() is
     * the right call here. A failed update leaves the attribute at its previous value
     * while the sensor log still shows a good reading — never drop these codes.
     * BatPercentRemaining is in half-percent units (0..200). */
    esp_matter_attr_val_t val = esp_matter_nullable_uint8(bat_pct * 2);
    log_update("battery pct", s_eps.power_source_endpoint_id,
               update(s_eps.power_source_endpoint_id, PowerSource::Id,
                      PowerSource::Attributes::BatPercentRemaining::Id, &val));

    val = esp_matter_nullable_uint32(bat_mv);
    log_update("battery mV", s_eps.power_source_endpoint_id,
               update(s_eps.power_source_endpoint_id, PowerSource::Id,
                      PowerSource::Attributes::BatVoltage::Id, &val));
}

static void poll_cb(void *arg)
{
#if CONFIG_HOMECADIA_SLEEP_DIAG_NO_POLL
    return; /* hang bisect: poll does nothing (main/Kconfig.projbuild) */
#endif
    float temp_c, rh;
    esp_err_t err;
#if CONFIG_HOMECADIA_SLEEP_DIAG_POLL_NO_SHT40
    temp_c = 21.0f, rh = 50.0f; /* hang bisect: no I2C traffic (main/Kconfig.projbuild) */
#else
    err = sht40_read(s_sht40, &temp_c, &rh);
    if (err != ESP_OK) {
        ESP_LOGW(TAG, "SHT40 read failed: %s", esp_err_to_name(err));
        return;
    }
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

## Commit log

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2026-08-08 Milestone 2: temperature/humidity/power-source endpoints, SHT40 driver, battery gauge
    - firmware/components/sht40: single-shot high-precision driver on the
    IDF 5.x i2c_master API, Sensirion CRC-8 checked.
    - main/battery: adc_oneshot + curve-fitting calibration on GPIO5
    (ADC1_CH5), 2x divider correction, LiPo OCV lookup table.
    - main/sensor_loop: 120s poll; Matter attribute updates only on delta
    (>=0.2C / >=1%RH / battery drop) or every 10th poll as staleness
    guard; updates batched under one Matter stack lock (v1.6 RAII
    ScopedChipStackLock - the free lock functions are gone in v1.6).
    - Power source endpoint with battery feature; BatPercentRemaining and
    BatVoltage created as option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
    [app_config.h, app_main.cpp, battery.cpp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]
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2026-08-08 Milestones 5/6 (pre-hardware): LIT ICD, factory reset, LED policy, low-battery display
    - sdkconfig: CONFIG_ENABLE_ICD_LIT=y (pulls in check-in protocol and
    user-active-mode trigger); idle mode interval 120s aligned with the
    sensor poll; short-idle 60s for SIT-mode operation. Verified the
    options exist in this connectedhomeip revision and land in the
    generated sdkconfig. On-hardware tuning remains milestone 5.
    - ui: encoder held 10s -> esp_matter::factory_reset() (wipes fabrics +
    NVS, reboots into the commissioning screen).
    - led: commissioning window open = 500ms blink; battery <10% = 100ms
    pulse every 10s; otherwise off. Commissioning overrides low battery.
    - View 1 shows LOW BA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
    [app_config.h, app_main.cpp, display.cpp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]
2026-08-08 hardware/case: wall-mount STLs (veltoc remix rev 1), preview, print notes
    STLs from veltoc-wallmount.zip: case-back remixed (side USB-C, keyhole
    rails, plugged rear port), front/tray/knob unchanged from upstream.
    Print notes merged into the case README; upstream's 2x100k battery
    divider corrected to this build's 2x1M + 100nF with rationale.
    [case-back-wallmount.stl, case-front.stl, encoder-knob.stl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]
2026-08-08 Fix RF switch init and console; record schematic-verified board facts
    Two defects found by checking the XIAO ESP32-C6 schematic
    (XIAO-ESP32-C6_v1.0_SCH_PDF_24028, sheets 3/5 and 4/5):
    - The FM8625H antenna switch is unpowered at reset (P-FET gate GPIO3
    pulled up) and firmware never enabled it - the radios had no antenna.
    board_rf_switch_init() now drives GPIO3 low (power) and GPIO14 low
    (ceramic antenna) before the Matter stack starts. Arduino's XIAO
    variant init does this implicitly; pure esp-idf must do it explicitly.
    - No UART bridge exists (USB D+/- wire to native USB): console now
    CONFIG_ESP_CONSOLE_USB_SERIAL_JTAG=y instead of unconnected UART0.
    docs/pinmap.md: schematic-ve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
    [app_config.h, app_main.cpp]
2026-08-08 Keep USB Serial/JTAG alive while a host is connected
    Light sleep powers down the USB Serial/JTAG peripheral; with PM +
    tickless idle the port died seconds after boot (host logs
    'device descriptor read/8, error -32', flashing needs the BOOT
    button every time). CONFIG_USJ_NO_AUTO_LS_ON_CONNECTION=y holds an
    ESP_PM_NO_LIGHT_SLEEP lock only while USB is connected; battery
    operation is unaffected.
    Hardware-verified on unit 1: with this option the port stays
    enumerated indefinitely; without it, dead in under 2s.
2026-08-08 docs: field notes from first flash of unit 1
    - build.md: WSL2 flashing via usbipd, and the three gotchas hit in
    practice (old firmware needs BOOT-button download mode because light
    sleep kills USB; attach doesn't survive re-enumeration without
    --auto-attach; raw tty reads can hard-reset the chip via the USB-SJ
    control-line latch - use idf.py monitor interactively).
    - commissioning.md: compiled-in test pairing codes (34970112332,
    one-unit-at-a-time caveat), the Matter-server URL prompt on HA
    (add-on vs container paths, OTBR implication), and the Apple Home
    path (needs an Apple Thread border router; multi-fabric with HA).
    - bringup.md: flash & console section - chip rev, USB-aliv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
2026-08-13 fix(case): zero STL attribute-byte field on knob and tray for strict parsers
    [encoder-knob.stl, insert-tray.stl]
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2026-08-13 docs(pcb): evaluate replacing the hand-wired build with a custom PCB
    Conclusion: not worth it for three units. Build a through-hole harness
    board for pain points 1/3/6 (~CAD 40, one evening), hand-wire the three
    units, and measure the assembled device before any power argument
    justifies a board spin.
    Three options costed: passive harness board, XIAO carrier with FPC +
    booster, and a fully integrated ESP32-C6-MINI-1 board. Option B's
    hardware floor is ~15uA vs the XIAO's unmeasured 15-300uA, so the
    saving is unknowable until docs/power-budget.md has real numbers.
    Key findings:
    - The SSD1680 ships as bare die, chip-on-glass on the panel flex
    (datasheet section 14). Dropping the Seeed driv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
2026-08-13 fix(pcb): validate both boards against KiCad 10, place footprints, fix real errors
    Ran the generated files through the Windows KiCad 10.0.5 install via
    kicad-cli from WSL. This turned the boards from unvalidated text into
    something KiCad parses, places, DRCs and renders - and caught six real
    errors in the process.
    Verified:
    - all 13 footprint library refs resolve against KiCad 10's libraries
    - kicad-cli pcb upgrade accepts both boards
    - 26 footprints place with nets assigned, 0 missing
    - J1's 17 pads are byte-identical to the library after round-trip
    - both boards render in 3D (img/*-render.png are kicad-cli output)
    - sb-01 passes DRC with 0 errors
    - encoder terminals checked against the Bo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
    [hb-01.kicad_pcb, sb-01.kicad_pcb]
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2026-08-13 feat(case): rev 4 - revert embossed wordmark, laser-engrave instead; switch to PLA
    [case-front.stl]
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2026-08-17 fix(firmware): ICD ActiveModeThreshold 1000→5000ms — LIT minimum, was boot-looping
    connectedhomeip ICDManager.cpp:82 VerifyOrDies when a LIT ICD configures
    ActiveModeThreshold below 5s; the device abort()ed ~1.3s after app_main
    on every boot. 11,374 reboots on the NVS counter before it was caught on
    the first powered bench test (unit 1, bench PSU + SHT40). Threshold only
    extends awake time after user activity, so the power cost is
    per-interaction, not per-idle-cycle.
    Verified on unit 1: boots to Server Listening, no abort.
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2026-08-18 docs(assembly): driver board ships with bare holes — solder headers before bring-up
    Found on unit 1's bench session: jumper wires pushed into unpopulated
    plated holes make contact only by luck, and the intermittent connections
    imitate real faults — floating BUSY (panel looks dead), SHT40 dropping
    off I2C between resets, and two USB brownouts. Step 7 assumed the XIAO
    could seat on the board as shipped.
2026-08-18 docs(bom): add female headers as an assembly blocker, plus solder/flux line
    The ePaper driver board ships with bare through-holes; 2x7 female sockets
    per unit are required before the XIAO can seat on it. Missing from the BOM
    until hardware bring-up surfaced it.
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2026-08-22 fix(ssd1680): require BUSY to rise after MASTER_ACTIVATE
    busy_wait() returned ESP_OK the moment BUSY read low, which is also the
    resting state of a panel that never received the command stream at all —
    a disconnected display and a completed refresh were indistinguishable.
    Every refresh reported success through two days of bring-up in which
    nothing was ever drawn, so the fault was hunted in the wrong layer.
    A real update raises BUSY first: ~1.8s for a full refresh, ~0.5s for a
    partial one on the GDEY029T94. busy_wait_update() now requires that rise
    within 200ms of MASTER_ACTIVATE and returns ESP_ERR_INVALID_RESPONSE
    otherwise. display.cpp already logs the failure and holds back the
    partial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
    [ssd1680.c]
2026-08-22 fix(display): flip the long axis so the image is upright
    Verified on hardware with the panel in the case and the FPC at the
    bottom. Closes the two orientation HW-VERIFY markers.
    [app_config.h]
2026-08-22 fix(display): hold the onboarding codes until a fabric exists
    app_main drew the commissioning QR once at startup when FabricCount()==0,
    then the first sensor poll called display_show_readings() and painted over
    it — about a second later on the bench. The device was still unpaired and
    its only pairing code was gone until a reboot.
    display.cpp now latches: display_show_commissioning() stores the codes and
    sets s_awaiting_commissioning, and while that is set a readings message
    re-renders the codes instead (or drops if they are already on the panel,
    since e-ink holds the image). This also covers the settings/diagnostics
    views and the UI idle timeout, which returned to the readings view.
    displ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
    [app_main.cpp, display.cpp]
2026-08-22 docs: record the ePaper bring-up outcome and the FPC rules it produced
    The display works: driver board #1, XIAO seated directly, panel refreshing
    full (1790ms BUSY) and partial (540ms), readings on screen. Two days of
    probing were spent on a fault that was mechanical, so the docs now carry the
    rules that would have caught it.
    - assembly.md: FPC orientation goes by insertion force, not by which way the
    copper faces — the correct way slides in, the reversed way needs pushing,
    and reversed it mirrors the pin order so the MCU drives the panel's supply
    rails. Seat to the stiffener, not to "as far as it goes". Handle the bare
    flex as ESD-sensitive. XIAO seats USB-C end away from the FPC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
2026-08-23 fix(sensor): surface attribute update failures instead of discarding them
    report_matter() dropped the esp_err_t from all four attribute::update() calls.
    A failed write leaves the attribute at its previous value — null on a fresh
    boot — so the device logs a healthy "reported 26.56°C 71.6%RH" while a
    controller reading MeasuredValue over Matter gets null, with nothing anywhere
    to connect the two.
    That is exactly the state sensor-01 was in after commissioning on 2026-08-23:
    console showing readings, 1/1026/0 and 2/1029/0 reading null from
    matter-server, and 3/47/11 on the same node reading fine. This does not
    diagnose that — the writes are logged as accepted by esp_matter_attribute —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
    [sensor_loop.cpp]
2026-08-23 docs: field notes — the traps from sensor-01 bring-up
    Two days of bring-up produced a set of failure modes that each looked like
    something they were not. Written down so units 2 and 3 cost minutes rather
    than hours: the observability rule behind the busy_wait() defect, light sleep
    killing the USB-serial-JTAG console, mapping a tty to its USB VID before
    opening it, FPC insertion by feel, the three preconditions for Matter
    commissioning, and checking the border router is actually running before
    concluding a device is out of range.
2026-08-23 docs(field-notes): record the open MeasuredValue-reads-null defect
    Temperature and humidity read null over Matter while the device logs correct
    readings, so HA creates no sensor entities. Captures what has been ruled out —
    device types, cluster serving, matter-server caching, creation-time vs runtime
    setting — and the decisive observation that a device-side get_val() right after
    update() returns the null sentinel while esp_matter logs the written value.
    Left open rather than guessed at; the next experiment is written down.
2026-08-24 docs(field-notes): controlled repro for the MeasuredValue defect, meter trap, prior art
    Adds the decisive control for section 9: the same update() call stores
    BatVoltage correctly and loses TemperatureMeasurement MeasuredValue in the same
    function one line apart, so the fault is the attribute rather than the API, and
    esp_matter's attribute log prints the requested value rather than the stored one.
    Adds two things learned from outside: multimeter burden voltage restarting the
    C6 and masquerading as a power fault (relevant to milestone 5), and a survey
    showing no published implementation combines this board with esp-matter over
    Thread plus ePaper and battery — so there is nothing to diff ag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
2026-08-24 docs(field-notes): root-cause the MeasuredValue defect to split write/read stores
    set_val() with a value that cannot already be present returns ESP_OK and the
    read immediately after still returns the null sentinel; writing the same value
    twice returns ESP_ERR_NOT_FINISHED, which is only emitted when val_compare
    finds the stored value equal. So writes land and reads do not see them.
    set_val writes _attribute_t::attribute_val and val_compare reads it, while
    get_val(attribute_t*) resolves the path and delegates to the path-based read
    that the wire also uses. Those are not linked for MeasuredValue and are for
    BatVoltage, which the app creates explicitly rather than via the endpoint
    helper — m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
2026-08-24 fix(sensor): set MeasuredValue on the registered cluster object, not the attribute store
    Temperature and humidity read null over Matter while the device logged correct
    readings, so Home Assistant created no sensor entities. Battery on the same node
    worked through the identical attribute::update() call one line away.
    Cause: esp-matter v1.6 serves TemperatureMeasurement and
    RelativeHumidityMeasurement from code-driven cluster objects it registers in the
    data-model provider. The provider's ReadAttribute checks that registry before
    esp-matter's own attribute store, and the registered object keeps its own copy
    of MeasuredValue that is never seeded (StartupConfiguration carries min, max and
    toler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
    [sensor_loop.cpp]
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2026-08-24 fix(matter): advertise the reopened commissioning window over BLE
    kFabricRemoved passed kDnssdOnly to OpenBasicCommissioningWindow, so the
    window it reopens was advertised over DNS-SD only. Removing the last
    fabric also drops the device off Thread, so that advertises on a network
    it is no longer attached to -- nowhere.
    The block's own comment says the point is re-adoption "without a manual
    factory reset"; the code guaranteed the opposite. Any unit un-paired by a
    controller became unreachable and needed a physical NVS erase to recover.
    Found on hardware while retesting matter-js/matterjs-server#1006: after
    remove_node the device stopped advertising entirely and only came back
    after a power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
    [app_main.cpp]
2026-08-24 fix(matter): reboot on last-fabric-removal so BLE comes back
    kAllSupported (7acb5b7) was necessary but not sufficient. With
    CONFIG_USE_BLE_ONLY_FOR_COMMISSIONING=y the stack tears BLE down once
    commissioning finishes and hands its RAM back to the heap:
    void BLEManagerImpl::DeinitESPBleLayer() {
    VerifyOrReturn(DeinitBLE() == CHIP_NO_ERROR);
    #ifdef CONFIG_USE_BLE_ONLY_FOR_COMMISSIONING
    BLEManagerImpl::ClaimBLEMemory(nullptr, nullptr);
    #endif
    }
    -- connectedhomeip src/platform/ESP32/nimble/BLEManagerImpl.cpp:1004
    ClaimBLEMemory releases the controller memory to the general heap, which
    cannot be undone in place. So the window reopened in kFabricRemoved had
    no BLE stack to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
    [app_main.cpp]
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2026-08-25 diag(ssd1680): scan and drive-test panel signals at init
    A misseated FPC put a panel supply rail onto MOSI: D10 sat at 3.1V and
    could not be driven low, so every byte clocked to the panel was 0xFF and
    the panel went deaf. It presented first as a dead panel, then as a
    firmware bug. Neither. Half a bench session went into finding it.
    ssd1680_init() now reports the electrical state of every panel signal
    before any SPI traffic, then drive-tests the five outputs: a line the C6
    drives high that does not read high is shorted, and that is unambiguous
    where a passive reading is not.
    power_up() additionally requires BUSY to rise after SW_RESET. busy_wait()
    cannot show this -- it returns OK the momen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
    [ssd1680.c]
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2026-08-26 bench: encoder and LED verified; encoder moves to D9/D6, LED to D7
    Encoder rotation, clockwise = view advances, and the LED are all
    verified on hardware (2026-08-26). Three findings changed the pin map:
    - D7/GPIO17 reads 0 V from the moment display_init() brings the SPI bus
    up, on both driver boards. A 45k internal pull-up cannot lift it, the
    meter reads it open unpowered, and the Seeed schematic has nothing on
    the net. Unexplained; routed around. The LED, an output, takes D7 and
    the encoder input moves to D6, whose only neighbour is SCL.
    - With A on D6 clockwise decoded as -1, so A/B are swapped in firmware
    (A=D9, B=D6) rather than on the board. Verified: 4 clockwise detents
    gi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
    [app_config.h]
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2026-09-15 battery: create the ADC unit per reading; a held unit kept the modem domain on
    On the C6 adc_oneshot_new_unit() pins ESP_PD_DOMAIN_MODEM on until the unit
    is deleted (ADC_LL_ADC_FE_ON_MODEM_DOMAIN). battery_init() created it once, so
    the modem domain stayed up for 100% of sleep time (sleep-diag image). Fix
    built, not yet measured on the PPK2.
    Docs: field-notes s21 (the investigation, what was ruled out, the buck
    regulator's pulse train, the dial dead on battery), bringup rows for the
    modem domain, the shipping-image ADC sweep and the dial, power-budget floor,
    build.md diagnostic image and Windows-native flashing.
    Claude-Ses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
    [battery.cpp]
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2026-09-23 battery: fitted scale replaces the 340 mV offset; 64 samples, 20 ms settle
    Swept on the shipping image against BAT+ (PPK2, meter in-circuit): one gain,
    x1.019, fits 3.68 and 4.00 V; a 3.39 V check the fit never saw reads 3389
    and 3387. Report scatter 4 mV, was +/-120 mV. The earlier offset-0 attempt
    compared against the meter-loaded divider midpoint (field-notes section 23).
    tools/matter-node.py: the one-shot matter-server read, out of the scratchpad.
    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
    [app_config.h, battery.cpp]
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2026-09-23 dial: wake from light sleep on turn and press (encoder A on MTCK, switch on MTDO)
    With peripheral power-down in light sleep only LP GPIOs (0-7) can wake the
    C6 (ESP-IDF sleep_modes docs), so encoder A moves D9 -> MTCK/GPIO6 and the
    push switch MTCK -> MTDO/GPIO7.
    ec11: ec11_enable_light_sleep_wake() arms A for the level it is not at and
    holds the chip awake ENC_AWAKE_MS after activity so B (HP pin) decodes too.
    A detent is emitted when the contacts return to rest rather than after
    exactly 4 steps, so a detent whose first steps were lost to the wake counts.
    ui: own push-switch handler replaces espressif/button, whose power-save mode
    takes over ext1 wake and pin hold under peripheral power-d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
    [app_config.h, bench_selftest.cpp, ec11.c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]
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2026-09-28 dial: bench profile builds without PM locks; self-test waits for the console
    ui.cpp: the push-switch PM lock is created, taken and released only under
    CONFIG_PM_ENABLE. The bench profile has no PM, esp_pm_lock_create() failed
    there and ui_init() returned before the encoder was set up.
    bench_selftest.cpp: 4 s delay before the harness scan, so a host that
    reopens the USB console after a reset sees it. The ENC A note no longer
    attributes "held HIGH" to the JTAG pull-up: that reading was taken with the
    wire on the 3V3 pad.
    app_config.h: wake on a detent verified on battery 2026-09-28 (node 26).
    Claude-Session: https://claude.ai/code/ses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
    [app_config.h, bench_selftest.cpp, ui.cpp]
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2026-09-29 docs: pinout drawing, encoder diagram and BOM match the unit as built
    sensor-01-pinout.svg (shown in the README) had the divider on MTDI/GPIO5,
    the LED on D6 and the encoder on D7/D9. It now shows MTMS/GPIO4, encoder A
    on the MTCK pad, encoder B on D6, the LED on D7 and the push switch on D9.
    encoder-led.html: encoder A is drawn to TP6 and the switch to D9; table,
    caption and closing rows rewritten. battery-divider.html, pinmap.md,
    bom.md, source-reliability.md and the app_config.h comment no longer name
    MTDI/GPIO5 as the divider pin.
    hardware/case/README.md: notice that rev 4 does not fit the parts.
    bom.md: header sockets fitted, flux and wire as delivered, XIAO count, and
    30 AWG pad wir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
    [app_config.h]
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2026-10-03 sensor-01: an unpaired unit deep-sleeps once its commissioning window closes
    An unpaired unit advertises at ~28 mA and drained a cell in about three
    days. Now, once the 15-minute window has closed with no fabric (or 16 min
    after boot, whatever the window reads, unless a pairing holds the
    fail-safe), it draws the onboarding screen with an "asleep, turn the dial"
    line, restarts, and enters deep sleep from the top of the next boot, before
    Bluetooth, Thread, the PHY or power management are started. Encoder A
    (GPIO6, LP) is the wake pin, held up and armed for the level it is not at.
    A woken boot releases the pad hold and wake setting and restarts once more.
    Measured on XIAO #4: 19.7 uA asleep on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
    [app_main.cpp, display.cpp]
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2026-10-05 sensor-01: test-only delay before arming the dial's light-sleep wake
    CONFIG_HOMECADIA_DIAG_DIAL_WAKE_DELAY_S defers ec11_enable_light_sleep_wake()
    so one capture compares the sleep floor with and without the GPIO wake source
    (which keeps RTC_PERIPH on). Result 2026-10-04: <=3 uA, not the floor rise.
    check-profiles.sh fails a shipping sdkconfig with a non-zero delay.
    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
    [ui.cpp]
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2026-10-06 sensor-01: empty-battery sleep, LED pulse through light sleep, report every point below 10 %
    Found by a PPK2 sweep 3700 -> 2900 mV on node 28 (docs/field-notes.md
    section 29):
    - At 2900 mV boots failed and the unit restarted about once a second,
    radio and panel each time (RebootCount 141 -> 639). empty_battery_on_boot()
    reads the battery before the radio exists; below 3100 mV (3300 mV after a
    brown-out or once an empty spell began) it draws a large-text "BATTERY
    EMPTY" screen, restarts and deep-sleeps, woken by the dial or an hourly
    timer. A running unit reading under 3050 mV restarts into the same check.
    New option CONFIG_HOMECADIA_EMPTY_BATTERY_SLEEP, asserted on in shipping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
    [app_config.h, app_main.cpp, battery.cpp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]
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2026-10-06 sensor-01: BootReason attribute, report poll 2 after boot, LED hold order
    - GeneralDiagnostics BootReason (0/51/4): the legacy data model creates only
    the event, so controllers read nothing. Created after node::create; reads 6
    (software reset) after a dial wake, verified 2026-10-06.
    - The first poll runs during Thread attach and has read 30-80 mV low; poll 2
    now always reports, so the low value stands 2 minutes, not up to 20.
    - set_led(): release the pad hold, set the level, re-latch; direction set once
    by gpio_config(); gpio_sleep_sel_dis() for light sleeps that keep the
    peripheral domain up.
    Research and the stepped-supply capture are in docs/field-notes.md section 29.
    Co-Autho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
    [app_main.cpp, led.cpp, sensor_loop.cpp]
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2026-10-07 sensor-01: report a battery rise of 5 points or more at once
    A rise used to wait for a temperature/humidity change or the forced report,
    up to 20 minutes: after a cell reconnect on 2026-10-06 Home Assistant showed
    0 % until a temperature change. BATTERY_RISE_REPORT_PCT (5) is well above
    the ~1-point reading noise, so a charge or a fresh cell reports within one
    120 s poll and a battery-only unit transmits no more than before.
    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
    [app_config.h, sensor_loop.cpp]
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

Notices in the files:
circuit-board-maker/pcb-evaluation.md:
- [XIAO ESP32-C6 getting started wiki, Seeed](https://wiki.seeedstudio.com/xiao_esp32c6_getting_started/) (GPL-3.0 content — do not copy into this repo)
